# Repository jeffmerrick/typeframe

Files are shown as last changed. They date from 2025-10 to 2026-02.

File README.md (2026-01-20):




The Typeframe project is a collection of open-source hardware and software for building writerdecks/cyberdecks.

# PX-88

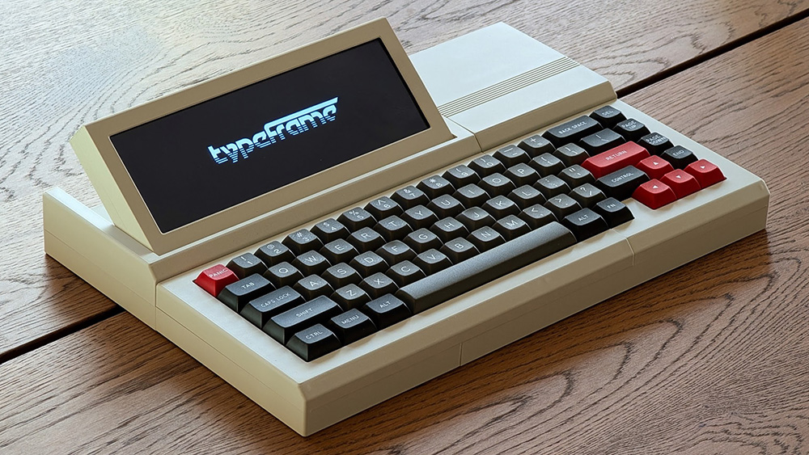
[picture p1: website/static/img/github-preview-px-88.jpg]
Typeframe PX-88


The first model, the PX-88, is a portable-ish computer inspired by the [Epson PX-4](https://www.homecomputermuseum.nl/en/collectie/epson/epson-px-4). The goal was to create a writerdeck that could be used with modern web-based editors.

## Features

- **Mechanical Keyboard**: A detachable 65% keyboard with hot-swappable switches.
- **Touch Screen**: No mouse needed.
- **One Power Connection**: A USB-C port that powers the device _and_ charges the battery.
- **Raspberry Pi 4 B:** Powerful enough to run web-based editors like Google Docs.
- **Software Setup**: A distraction-free laucher, boot splash images, and set up for keyboard shortcuts for screen brightness.
- **Easy to Build**: Minimal soldering required (just the power switch and status light!)

---

# PS-85

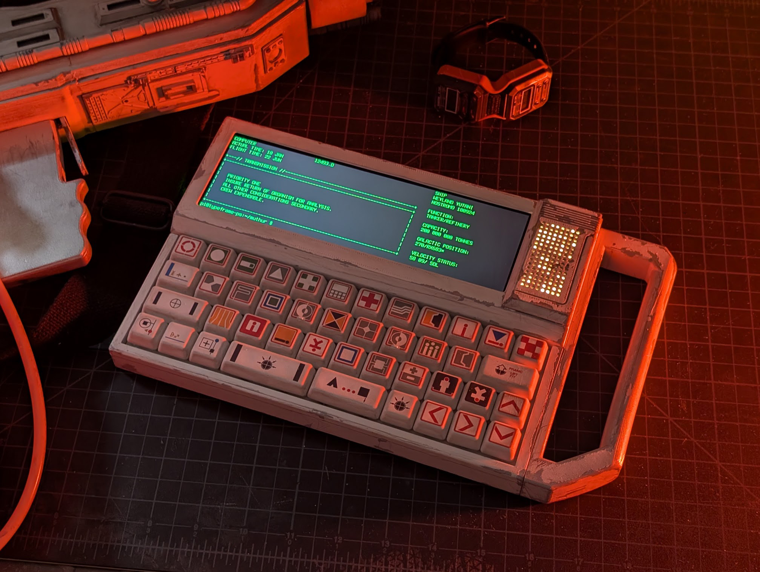
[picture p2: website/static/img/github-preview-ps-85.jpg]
Typeframe PS-85


The second model, the PS-85, is a rugged barebones slate-style portable computer inspired by the Alien universe

### Features

- **Carrying Handle**: A sturdy handle for easy transport.
- **Exposed GPIO**: Access to all GPIO pins for tinkering or adding your own Bonnets.
- **[MU/TH/UR](https://avp.fandom.com/wiki/MU/TH/UR_6000) LED Matrix**: An optional 9x16 LED matrix, just for fun.
- **Mechanical Keyboard**: A 40% keyboard with hot-swappable switches.
- **One Power Connection**: A Micro USB port that powers the device _and_ charges the battery.
- **Raspberry Pi Zero 2W**: Low power and compact.

## Documentation

For full assembly guides, bill of materials, and software setup instructions, please visit **[typeframe.net](https://www.typeframe.net)**

## Project Structure

- `px-88/`: Contains all files for the PX-88 model.
  - `hardware/`: 3D models and source CAD files.
  - `software/`: Scripts and configuration for the device.
- `ps-85/`: Contains all files for the PS-85 model.
  - `hardware/`: 3D models and source CAD files.
  - `software/`: Scripts and configuration for the device.
- `website/`: The Docusaurus source for the documentation site.

## License

This project uses multiple licenses for different parts of the work. Please see the `LICENSE` file for more details.

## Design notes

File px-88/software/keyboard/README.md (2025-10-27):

Keymaps for MK Point65 PCB from https://mechanicalkeyboards.com/products/mk-point65-keyboard-kit

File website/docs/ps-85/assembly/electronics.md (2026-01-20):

---
title: Electronics
sidebar_position: 2
description: Hooking up the electronics.
---

# Electronics Assembly

## Overview

Unlike the PX-88, you'll need to do more soldering for the PS-85. I'd never done it before this, so don't be intimidated if you haven't also! You will likely want to hook most things up before you start putting the case together to make sure the key components work. These steps will be repeated later with less detail in the full assembly guide.

## Soldering Connections to the PowerBoost

When I was putting mine together, I wished I had a diagram like this, so hopefully this helps you out.

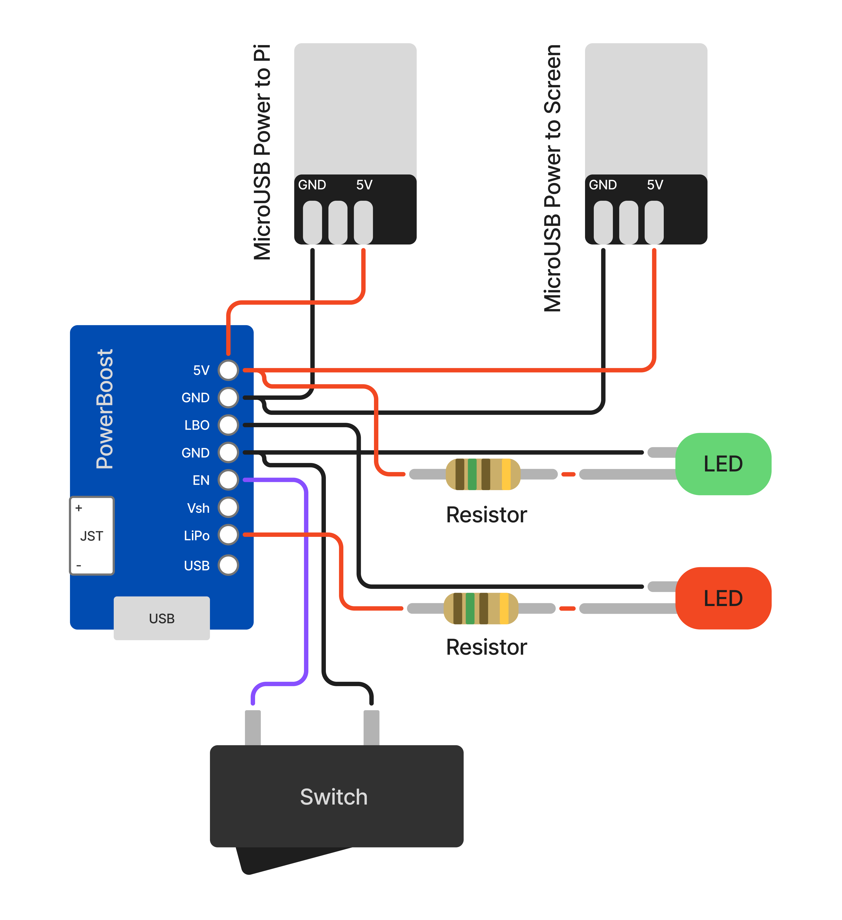
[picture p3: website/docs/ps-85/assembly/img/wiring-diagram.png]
PS-85 Wiring Diagram


| Soldered Connections                                              |
| ----------------------------------------------------------------- |
| PowerBoost `5V` &rarr; MicroB Plug 1 (Pi) `5V`                    |
| PowerBoost `GND` &rarr; MicroB Plug 1 (Pi) `GND`                  |
| PowerBoost `5V` &rarr; MicroB Plug 2 (Screen) `5V`                |
| PowerBoost `GND` &rarr; MicroB Plug 2 (Screen) `GND`              |
| PowerBoost `5V` &rarr; `Resistor` &rarr; Green LED `Long Leg`     |
| PowerBoost `GND` &rarr; Green LED `Short Leg`                     |
| PowerBoost `LBO` &rarr; Red LED `Short Leg`                       |
| PowerBoost `LiPo/BAT` &rarr; `Resistor` &rarr; Red LED `Long Leg` |
| PowerBoost `GND` &rarr; Power Switch `Terminal 1`                 |
| PowerBoost `EN` &rarr; Power Switch `Terminal 2`                  |

You can use any of the `GND` pins on the PowerBoost for the ground connections.

Remember that the power switch requires the wires to be disconnected to be seated in the case later, so you may want to use Dupont connectors for it here.

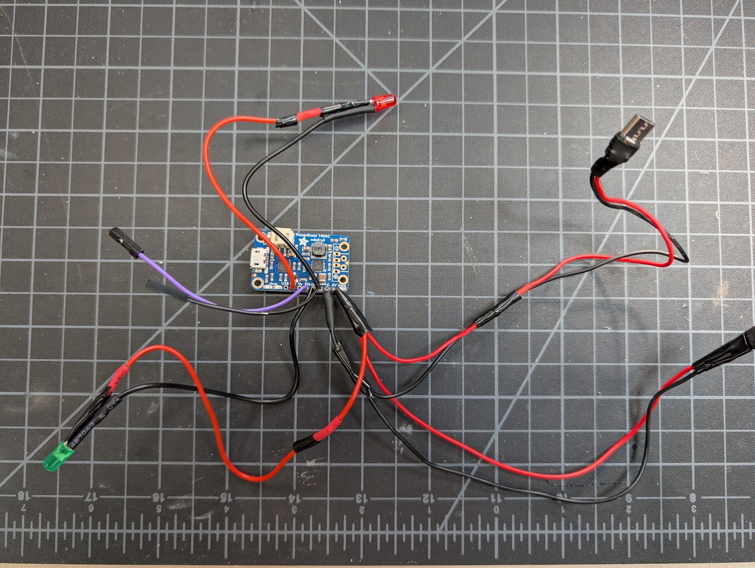
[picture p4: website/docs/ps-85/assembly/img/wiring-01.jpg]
PS-85 Wiring


## Screen

### 1. Assemble the DIY HDMI Cable and Plugs

Attach the two DIY HDMI plugs to either end of the DIY ribbon cable. If you're not sure which direction to insert the cable, look for the metal contacts on the cable - they should face the contacts inside the plugs.

### 2. Connect the Screen to Power and the Raspberry Pi

Plug the Micro USB power into the screen USB port labeled "Power". Plug one end of the DIY HDMI cable into the HDMI port on the screen and the other end into the Raspberry Pi's HDMI port.

## Raspberry Pi Power

Plug the remaining Micro USB port coming from the PowerBoost into the Pi port labeled `PWR IN`.

## Keyboard

You will likely want to print the keyboard plate before you start putting switches in the keyboard PCB. But once assembled, the keyboard should easily drop into the case.

Once assembled, just plug it in to the Raspberry Pi's USB port labeled `USB` with the USB-C to Micro USB cable.

## Battery

### 1. Reverse the Polarity of the Battery Connector

:::danger[Heads up!]

The battery connector may come with the polarity reversed. If the red wire is connected on the wrong side, you'll need to swap the wires so that red goes to positive and black goes to negative. You will 100% fry your PowerBoost if you don't check this! (Ask me how I know...)

:::

This is easy to do, no need to re-solder. You can use a small flathead screwdriver to gently pry up the plastic tabs on the connector and slide the wires out. Then just reinsert them in the correct order.

### 2. Connect the Battery to the PowerBoost 1000c

Plug the battery connector into the JST plug on the PowerBoost. Note the + and - symbols to ensure the polarity is correct. The Pi should power on at this point but won't boot until you complete the software setup.

## Testing

You'll need to jump to the [Software setup section](../software-setup/) to get the Pi booted and the screen working. Once you've done that, you can test all the connections before moving on to final assembly.

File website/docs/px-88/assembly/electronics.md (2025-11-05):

---
title: Electronics
sidebar_position: 2
description: Hooking up the electronics.
---

# Electronics Assembly

## Overview

Here, I'll go over how to connect the electronics for the PX-88. This includes connecting the Raspberry Pi, screen, Power Management HAT, and other components like the power switch and status light. You will likely want to hook most things up before you start putting the case together to make sure the key components work. These steps will be repeated later with less detail in the full assembly guide.

## Battery and Power Management HAT

### 1. Reverse the Polarity of the Battery Connector

:::danger[Heads up!]

The battery connector may come with the polarity reversed. If the red wire is connected on the wrong side, you'll need to swap the wires so that red goes to positive and black goes to negative.

:::

This is easy to do, no need to re-solder. You can use a small flathead screwdriver to gently pry up the plastic tabs on the connector and slide the wires out. Then just reinsert them in the correct order.

You want it to look like this:

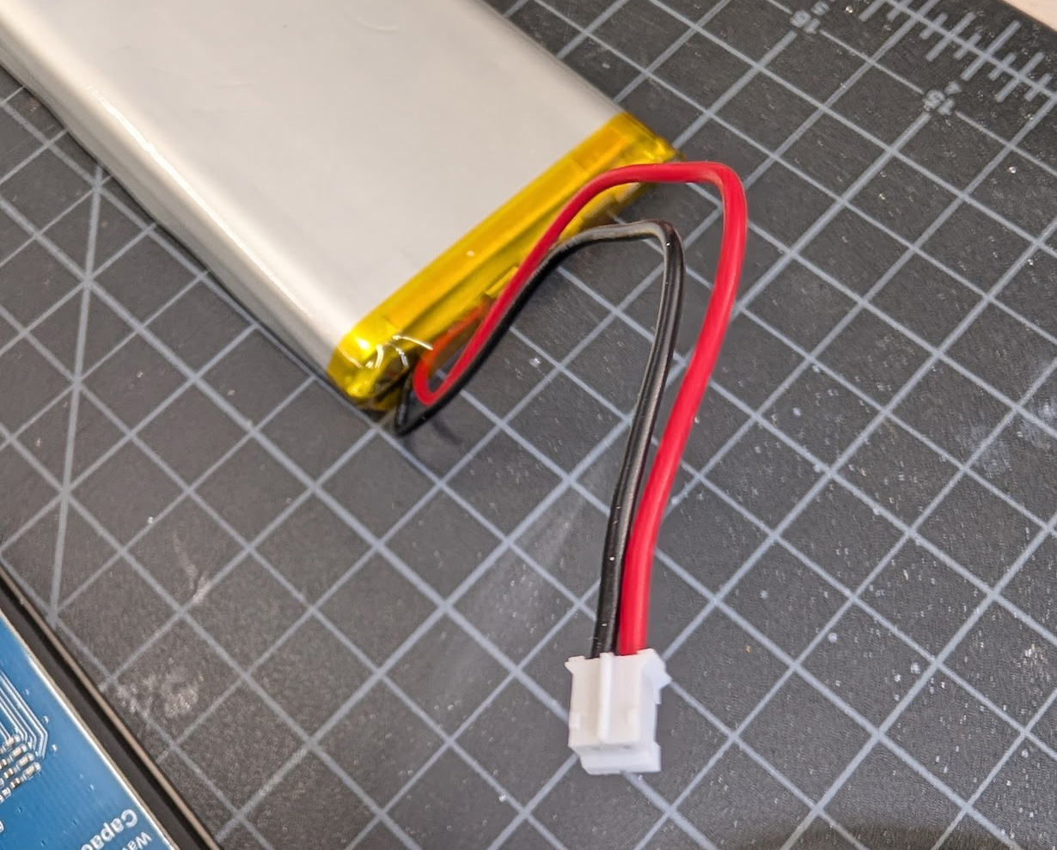
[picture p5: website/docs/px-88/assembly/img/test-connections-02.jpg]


Photos where the battery connects to the HAT may be a bit confusing as the extension cable does not have the wires swapped, but the battery connector does.

### 2. Attach the 200mm Extension Cable to the Battery

If you really want the colors to match, you can swap the wires on the extension cable as well, but it's not strictly necessary as long as you keep track of which wire is which.

### 3. Install the 1220 Lithium Battery

Insert the 1220 lithium battery into the battery holder on the Power Management HAT.

### 4. Attach the Power Management HAT to the Raspberry Pi

Push the GPIO header that came with the Power Management HAT into the GPIO pins on the Raspberry Pi, then the HAT itself onto the header. Don't worry about the standoffs since we're just testing, but hold on to them for later.

### 5. Connect the Battery to the Power Management HAT

Plug the battery connector into the battery port on the Power Management HAT. Note the + and - symbols to ensure the polarity is correct. In my photos the black wire on the extension cable is actually the positive wire.

## Screen

### 1. Connect the DSI Cable from the Screen to the Raspberry Pi

Using the longer 500mm DSI ribbon cable, connect one end to the screen and the other end to the DSI port on the Raspberry Pi. Make sure the cable is securely inserted and the connectors are properly aligned. If you're not sure which direction to insert the cable, look for the metal contacts on the cable - they should face the contacts inside the connector.

### 2. Connect the 4 Pin Cable to the GPIO Header

1. Plug the provided 4 pin connector into the screen - you'll see labels for each pin on the back of the screen. For mine they corresponded to the following wire colors (yours may be different, so double check!):

   - 5V - Yellow
   - GND - Blue
   - SDA1 - Purple
   - SCL1 - Green

2. Connect the other ends of the 4 pin connector to your Dupont female to male jumpers. You can choose the same colors to make things easier. Again, as we're just testing you can skip this step if you want to add the extension cable later.

3. Connect the jumpers to the GPIO header on the Power Management HAT as follows:

   - 5V - Yellow - 5V Power (Physical Pin 4)
   - GND - Blue - Ground (Physical Pin 6)
   - SDA - Purple - GPIO2 (SDA) (Physical Pin 3)
   - SCL - Green - GPIO3 (SCL) (Physical Pin 5)

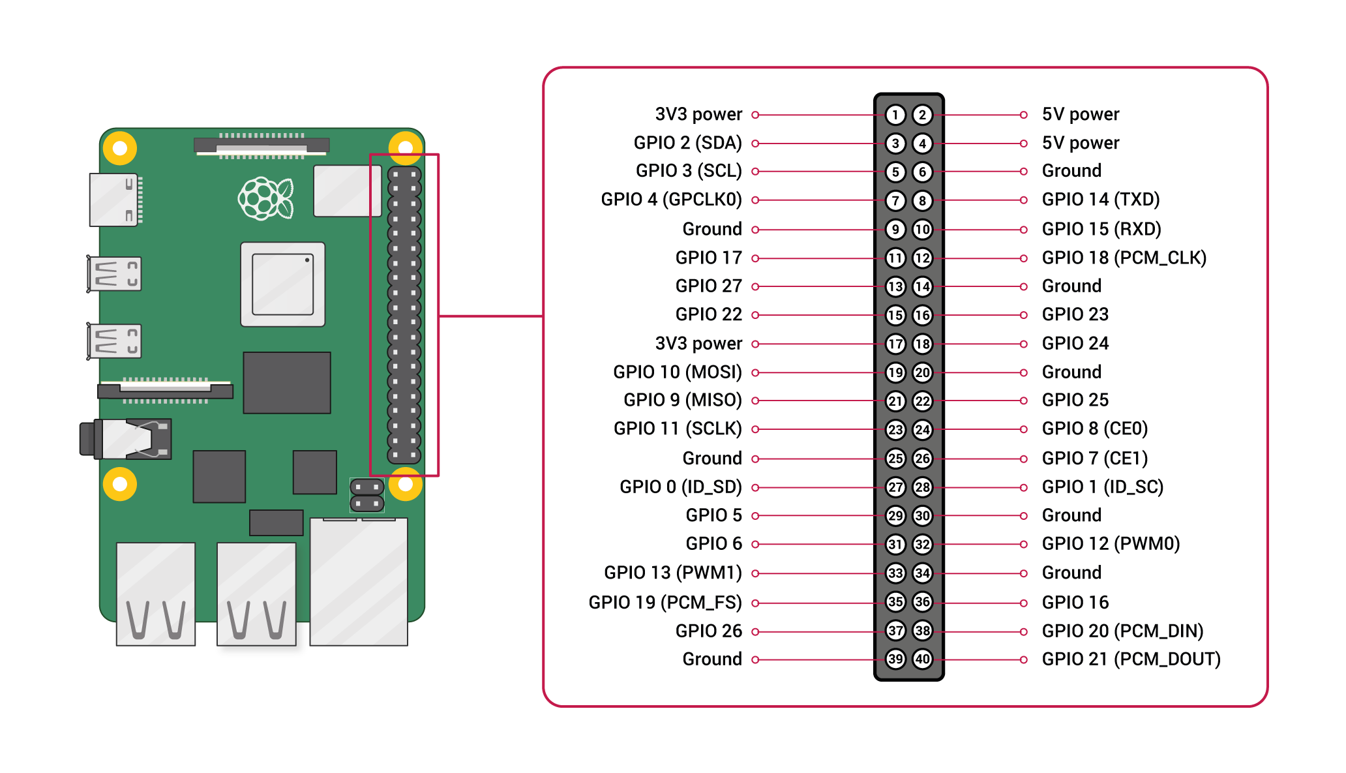
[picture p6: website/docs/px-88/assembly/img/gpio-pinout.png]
Raspberry Pi Pinout


Here's an older photo from when I was testing things out. You won't need to have the standoffs installed, but you can see the connections:

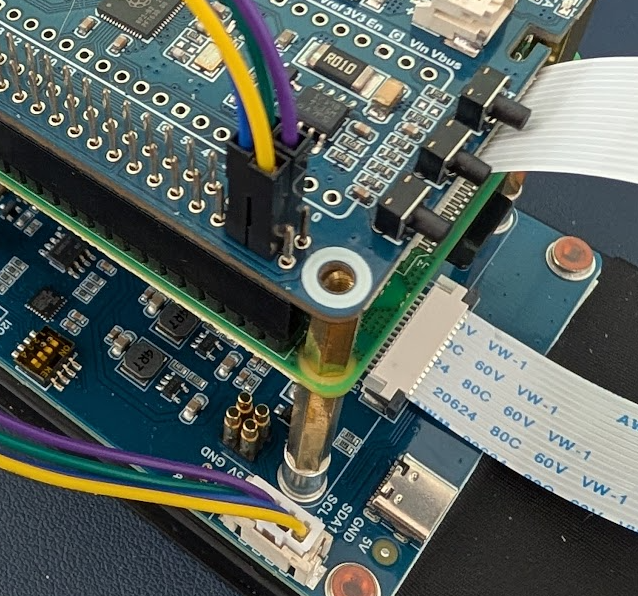
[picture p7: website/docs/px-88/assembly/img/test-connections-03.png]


## Keyboard

If you want to test out the keyboard, you can hook it up, but you'll need to follow the keyboard assembly to get the stabilizers, switches, and keycaps installed as well. You'll be able to assemble the rest of the keyboard case around it later, just removing a few of the switches and keys to access the screw mount points. But, you may elect to wait until later and use SSH or an extra keyboard for initial testing.

### 1. Connect Keyboard to Daughterboard

It connects with a small included cable. The cable goes in with the bigger metal contacts facing out and slots straight down.

### 2. Connect Daughterboard to Raspberry Pi

Using your small USB-A to USB-C cable, connect the daughterboard to one of the Raspberry Pi's USB ports.

## Power Switch

You'll need to do a bit of soldering here. You can also skip this step and use the onboard power button on the Power Management HAT for testing. If you choose to solder before installing the switch in the case, you may want to use Dupont jumpers to make it easier to connect and disconnect later. (Otherwise, you'll likely need to re-solder!)

### 1. Solder Wires to Power Switch

Solder Wires to Power Management HAT

Solder two female Dupont jumpers to the two terminals on the power switch. It doesn't matter which wire goes to which terminal. My soldering kit came with some heat shrink tubing, which I used here to cover the exposed contacts after soldering.

### 2. Solder Two Male Dupont Connectors to the Power Management HAT.

- Connect one to the Pin 19
- Connect the other to a Ground pin (labeled G)

Once the firmware is installed, this switch will perform the same function as the onboard power button on the HAT.

## Status LED

As with the power switch, you can add the status LED later if you'd like - it's easy to drop in after everything else is assembled.

### 1. Solder Dupont Jumpers to Status LED

Solder two female Dupont connectors to the two terminals on the status LED. Solder the red wire to the longer leg (positive) and the black wire to the shorter leg (negative). Include your 150Ω resistor in series with either wire.

### 2. Connect Jumpers to GPIO Header on Power Management HAT

- Connect the red wire (with resistor) to GPIO 19 (Physical Pin 35)
- Connect the black wire to a Ground pin (Physical Pin 39)

Note that the status LED won't work until some configuration is done later in the software setup section.

My test connections:

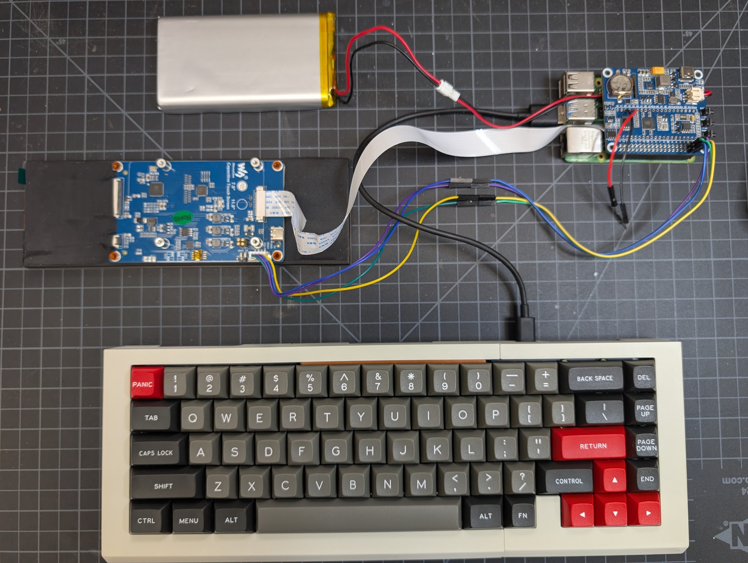
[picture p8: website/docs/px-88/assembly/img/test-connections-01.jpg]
Most Connections


Everything connected when it's installed in the case later:

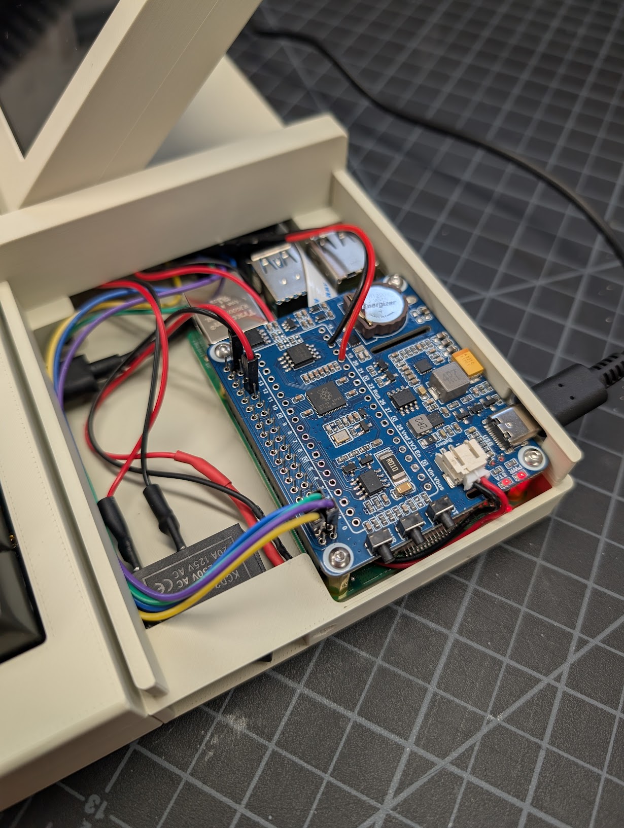
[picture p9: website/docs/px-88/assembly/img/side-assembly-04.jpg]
Completed Connections


## Testing

You'll need to jump to the [Software setup section](../software-setup/) to get the Pi booted, the screen working, and the Power Management HAT firmware installed. Once you've done that, you can test all the connections before moving on to final assembly.

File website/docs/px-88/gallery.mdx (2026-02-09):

---
title: Gallery
sidebar_position: 4
hide_table_of_contents: true
---

import { GalleryGrid } from "@site/src/components/GalleryGrid";

## Typeframe PX-88

<GalleryGrid
  images={[
    require("./img/typeframe-px-88-01.jpg"),
    require("./img/typeframe-px-88-02.jpg"),
    require("./img/typeframe-px-88-03.jpg"),
    require("./img/typeframe-px-88-04.jpg"),
    require("./img/typeframe-px-88-05.jpg"),
    require("./img/typeframe-px-88-06.jpg"),
    require("./img/typeframe-px-88-07.jpg"),
    require("./img/typeframe-px-88-08.jpg"),
  ]}
/>

### Earlier Prototype with Alternate Keycaps

<GalleryGrid
  images={[
    require("./img/typeframe-px-88-10.jpg"),
    require("./img/typeframe-px-88-09.jpg"),
    require("./img/typeframe-px-88-11.jpg"),
  ]}
/>

---

## Community Builds

### Paul's Build

[Paul Rickards](https://biosrhythm.com/) built a Typeframe with a ton of enhancements including a Pi 5, speaker, alternate power switch, and modified case to fit a different keyboard. He even made a battery status system tray icon! Thanks to Paul for also helping to uncover some issues with the build and documentation.

[Check out his build on Mastodon](https://mastodon.social/@paulrickards/115703267825409926).

<GalleryGrid
  images={[
    require("./img/typeframe-px-88-paul-1.jpg"),
    require("./img/typeframe-px-88-paul-2.jpg"),
    require("./img/typeframe-px-88-paul-3.jpg"),
  ]}
/>

---

Did you build your own? [E-mail me](mailto:jeff@typeframe.net) photos and I'll add them to the gallery!

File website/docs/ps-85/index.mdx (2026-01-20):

---
title: PS-85
sidebar_position: 1
hide_table_of_contents: true
---

import Image from "@theme/IdealImage";
import DocCardList from "@theme/DocCardList";

# Typeframe PS-85

<p>
  <Image img={require("./img/typeframe-ps-85-01.jpg")} />
</p>

The PS-85 is a rugged barebones slate-style portable computer inspired by the Alien universe.

Before I built the [PX-88](/docs/px-88/), I tried to modify the awesome [Penkesu](https://penkesu.computer) by Penk Chen to fit a hot-swap keyboard PCB. While I was somewhat successful, I wasn't happy with the result and it lost the charm of the original. After pivoting to the PX-88, I still had the working guts from my Penkesu experiment - so I decided to design a simple slate-style case around it. You'll find the parts and wiring are very similar to the Penkesu with a couple of additions.

### Features

- **Carrying Handle**: A sturdy handle for easy transport.
- **Exposed GPIO**: Access to all GPIO pins for tinkering or adding your own Bonnets.
- **[MU/TH/UR](https://avp.fandom.com/wiki/MU/TH/UR_6000) LED Matrix**: An optional 8x16 LED matrix, just for fun.
- **Mechanical Keyboard**: A 40% keyboard with hot-swappable switches.
- **One Power Connection**: A Micro USB port that powers the device _and_ charges the battery.
- **Raspberry Pi Zero 2W**: Low power and compact.

### Caveats

- **Lite OS**: With a Pi Zero you're likely going to want to run Raspberry Pi OS Lite and have a command-line only interface.
- **No Touch Screen**: While the screen supports touch, it requires a separate USB connection. (Doesn't matter if you're using the Lite OS anyway.)
- **No Hardware Screen Brightness**: The HDMI screen doesn't allow brightness control like a DSI screen.

<DocCardList />

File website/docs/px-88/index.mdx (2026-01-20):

---
title: PX-88

sidebar_position: 2
hide_table_of_contents: true
---

import Image from "@theme/IdealImage";
import DocCardList from "@theme/DocCardList";

# Typeframe PX-88

<p>
  <Image img={require("./img/typeframe-px-88-01.jpg")} />
</p>

The PX-88 is a portable-ish computer inspired by the [Epson PX-4](https://www.homecomputermuseum.nl/en/collectie/epson/epson-px-4). The goal was to create a writerdeck that could be used with modern web-based editors.

This is my first time building something of this scope, especially with CAD and electronics. I've tried to document everything in detail, so someone like myself with limited experience can tackle the project as well. If I can do it, you can too!

### Features

- **Mechanical Keyboard**: A detachable 65% keyboard with hot-swappable switches.
- **Touch Screen**: No mouse needed.
- **One Power Connection**: A USB-C port that powers the device _and_ charges the battery.
- **Raspberry Pi 4 B:** Powerful enough to run web-based editors like Google Docs.
- **Software Setup**: A distraction-free launcher, boot splash images, and setup for keyboard shortcuts for screen brightness.
- **Easy to Build**: Minimal soldering required (just the power switch and status light!)

<DocCardList />

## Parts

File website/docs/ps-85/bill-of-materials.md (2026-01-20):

---
sidebar_position: 1
description: Everything you need to build the PS-85.
---

# Bill of Materials

These are the components you'll need to build the PS-85. I've linked to the manufacturer, Adafruit, or Amazon, where I purchased most of my parts. Often the Amazon link will be a set of multiple variants/sizes, so you may be able to find the same part individually elsewhere. If you can find the parts at [Adafruit](https://www.adafruit.com/), please consider supporting them.

## Keyboard

| Component | Notes | Link |
| --- | --- | --- |
| **KPrepublic BM43 PCB** | I had the 43 key version from my earlier experiments, but an ortholinear layout would match the aesthetic better. No idea if the [BM40](https://kprepublic.com/products/bm40-rgb-40-hot-swap-custom-mechanical-keyboard-pcb-qmk-underglow-type-c-planck) would be able to be swapped in easily, you'd at least need a new plate. | [kprepublic.com](https://kprepublic.com/collections/bm43/products/bm43a-bm43-43-keys-40-custom-mechanical-keyboard-pcb-programmed-numpad-layouts-qmk-firmware-with-rgb-bottom-underglo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) [amazon.com](https://www.amazon.com/dp/B09163VRTV?th=1) |
| **Low Profile Plate Mount Stabilizers** | | [amazon.com](https://www.amazon.com/dp/B0F48MHHDR?th=1) |
| **Keyboard Switches - Cherry MX Compatible (x43)** | I had medium profile switches but you could get a different profile, just make sure you get the matching stabilizers. | [amazon.com](https://www.amazon.com/dp/B0F4Y41SLJ) |
| **Keycaps - MX Compatible (x43)** | Flat profiles like DSA or XDA match the aesthetic well and are more flexible since they don't need to go in a specific row. But any MX compatible keycaps will work. Because of the 40% layout you'll need some odd sizes - buying a full 80% TKL set should get you what you need. | [spkeyboards.com](https://spkeyboards.com/collections/keycap-sets/products/g20-semiotic-keycaps) |
| **Short USB-C to Micro-USB Cable** | I had one in my hoarded cables that I was able to use. It just has to reach from the keyboard to the Pi, so it can be quite short. | [adafruit.com](https://www.adafruit.com/product/3879) |

## Screen

| Component | Notes | Link |
| --- | --- | --- |
| **Waveshare 7.9inch HDMI LCD** | | [waveshare.com](https://www.waveshare.com/7.9inch-hdmi-lcd.htm) |
| **DIY Cable Parts - Straight HDMI Plug** | In my photos I have an angled version but the straight one should work fine. | [adafruit.com](https://www.adafruit.com/product/3548) |
| **DIY Cable Parts - Straight Mini HDMI Plug**  | | [adafruit.com](https://www.adafruit.com/product/3552) |
| **DIY Cable Parts - 20 cm Ribbon Cable** | | [adafruit.com](https://www.adafruit.com/product/3561) |
| **USB DIY Slim Connector Shell - MicroB Plug** | You'll actually need two, for the power to the screen and Pi. Get some extras in case you mess up the soldering like me. | [adafruit.com](https://www.adafruit.com/product/1826) |

## Computer

| Component | Notes | Link |
| --- | --- | --- |
| **Raspberry Pi Zero 2W with Header** | | [adafruit.com](https://www.adafruit.com/product/6008) |
| **microSD Card - 16GB+** | Get a quality SD card from a reputable brand. | [adafruit.com](https://www.adafruit.com/product/6010) [amazon.com](https://www.amazon.com/dp/B08L5HMJVW) |
| **3.7V 6000mAh 906090 LiPo JST PH2.0mm Battery** | | [amazon.com](https://www.amazon.com/dp/B0CRDMZQ3Q) |
| **PowerBoost 1000C** | | [adafruit.com](https://www.adafruit.com/product/2465) |
| **KCD3 SPST On-Off Switch, 2 Pin** | | [amazon.com](https://www.amazon.com/dp/B082PNCL61) |
| **Dupont Female to Male Extension Wires (x2)** | Optional, but recommended to make disconnecting the power switch easier. | [adafruit.com](https://www.adafruit.com/product/1954) [amazon.com](https://www.amazon.com/dp/B0BRTHR2RL) |
| **~150Ω Resistor (2x)** | | |
| **5mm Green LED** | For power indicator | [adafruit.com](https://www.adafruit.com/product/4203) [amazon.com](https://www.amazon.com/dp/B0CR886L92) |
| **5mm Red LED** | For low battery indicator | [adafruit.com](https://www.adafruit.com/product/4203) [amazon.com](https://www.amazon.com/dp/B0CR886L92) |
| **USB DIY Slim Connector Shell - MicroB Plug** | You'll actually need two, for the power to the screen and Pi. Get some extras in case you mess up the soldering like me. | [adafruit.com](https://www.adafruit.com/product/1826) |

## LED Matrix (Optional)

| Component | Notes | Link |
| --- | --- | --- |
| **2x20 Socket Riser Header for Raspberry Pi HATs and Bonnets** | You may want this either way to make the GPIO pins more easily accessible. | [adafruit.com](https://www.adafruit.com/product/4079) |
| **Adafruit CharliePlex LED Matrix Bonnet - 8x16 Warm White LEDs** | | [adafruit.com](https://www.adafruit.com/product/4122) |

## Screws and More

I used self-tapping M3 screws to avoid having to use heat-set inserts. You may be able to use normal M3 screws instead, but I have not tested that. There is enough room for socket head caps, so other heads should work as well.

| Component | Quantity | Notes | Link |
| --- | --- | --- | --- |
| **M3 x 10mm Self-tapping Screws** | 2 | | |
| **M3 x 16mm Self-tapping Screws** | 5 | | |
| **M3 x 20mm Self-tapping Screws** | 2 | | |
| **M3 x 25mm Self-tapping Screws** | 3 | | |
| **M2.5 x 4mm Screws** | 4 | | |
| **M2.5 x 8mm Screws** | 4 | | |
| **M2.5 x 20mm Screws** | 4 | | |
| **M2 x 4mm Screws** | 4 | | |
| **Wire** | | | [adafruit.com](https://www.adafruit.com/product/290) |
| **Matte White PLA Filament** | | If you're painting, any light color will be fine. | [amazon.com](https://www.amazon.com/dp/B089S1HB8K?th=1) |
| **Heat Resistant Tape** | | For securing the battery in the case. | [amazon.com](https://www.amazon.com/dp/B07F8TZZ4N) |
| **Grip Tape** | | Optional, for the bottom of the case to keep it from sliding around. Anything rubber and grippy would work. | [amazon.com](https://www.amazon.com/dp/B0FBGYF432) |

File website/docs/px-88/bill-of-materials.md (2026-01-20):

---
sidebar_position: 1
description: Everything you need to build the PX-88.
---

# Bill of Materials

These are the components you'll need to build the PX-88. I've linked to the manufacturer, Adafruit, or Amazon, where I purchased most of my parts. Often the Amazon link will be a set of multiple variants/sizes, so you may be able to find the same part individually elsewhere. If you can find the parts at [Adafruit](https://www.adafruit.com/), please consider supporting them.

## Keyboard

| Component | Notes | Link |
| --- | --- | --- |
| **MK Point65 PCB** | I chose the multi-layout version, however the RGB version should also work. | [mechanicalkeyboards.com](https://mechanicalkeyboards.com/products/mk-point65-pcb?variant=49801892331820) |
| **MK Point65 Daughterboard** | | [mechanicalkeyboards.com](https://mechanicalkeyboards.com/products/mk-point65-daughterboard-s11-udb) |
| **PCB Mount Stabilizers** | | [mechanicalkeyboards.com](https://mechanicalkeyboards.com/products/durock-stabilizers-v2-pcb-mount-screw-in-tkl-kit) |
| **Keyboard Switches - Cherry MX Compatible (x70)** | You can of course get whatever type of switches you prefer. But since there is no plate for the switches, just make sure you get switches that have 5 pins (the extra two plastic pins on the sides) for better stability. | [mechanicalkeyboards.com](https://mechanicalkeyboards.com/products/cherry-mx2a-blue-60g-clicky) |
| **Keycaps - MX Compatible (x70)** | Flat profiles like DSA or XDA match the portable computer aesthetic well and are more flexible since they don't need to go in a specific row. But any MX compatible keycaps will work. Note that if you get the linked 60% modifiers, you'll still need a `1.75U Shift`, a `1U Fn`, and the four `1U` keys you want on the right (typically `Del` or `Home`, `PgUp`, `PgDn`, and `End`). The "Alternate" kit will cover that and hopefully comes back in stock. | [spkeyboards.com](https://spkeyboards.com/products/dsa-dolch?variant=49434848428310) |
| **Short USB-C to USB-A Cable** | I had one in my hoarded cables that I was able to use. It just has to reach from the keyboard to the Pi, so it can be quite short: ~150mm (6 in). | [adafruit.com](https://www.adafruit.com/product/4472) |

## Screen

| Component | Notes | Link |
| --- | --- | --- |
| **Waveshare 7.9inch DSI LCD** | | [waveshare.com](https://www.waveshare.com/7.9inch-dsi-lcd.htm) |
| **500mm DSI Cable** | These may be labeled for use with the Raspberry Pi Camera, but they will work for the DSI screen as well. | [amazon.com](https://www.amazon.com/dp/B08662272F) |
| **150-200mm Dupont Female to Male Extension Wires (x4)** | Note that these need to be low-profile (it's a tight fit) and they apparently come in different sizes. | [adafruit.com](https://www.adafruit.com/product/1954) [amazon.com](https://www.amazon.com/dp/B0BRTHR2RL) |

## Computer

| Component | Notes | Link |
| --- | --- | --- |
| **Raspberry Pi 4 Model B - 4GB+ RAM** | | [adafruit.com](https://www.adafruit.com/product/4564) [raspberrypi.com](https://www.raspberrypi.com/products/raspberry-pi-4-model-b/) |
| **microSD Card - 32GB+** | Get a quality SD card from a reputable brand. | [adafruit.com](https://www.adafruit.com/product/6010) [amazon.com](https://www.amazon.com/dp/B08L5HMJVW) |
| **3.7V 10000mAh LiPo JST PH2.0mm Battery** | I ran into issues with some batteries not having a high enough discharge rate. Look for batteries with a 1S 3C rate or higher. There is room in the case for batteries with slightly different dimensions, but not much taller than 11mm. | [amazon.com](https://www.amazon.com/dp/B0D3LMBJC5) |
| **200mm JST PH2.0mm 2 Pin Male to Female Extension Cable** | | [amazon.com](https://www.amazon.com/dp/B0D1XS3W39) |
| **Waveshare Power Management HAT (B)** | | [waveshare.com](https://www.waveshare.com/power-management-hat-b.htm) |
| **1220 Lithium Battery** | For the clock on the Power Management HAT. Not sure if it's strictly necessary, but I added it. | [amazon.com](https://www.amazon.com/dp/B00004YK0L) |
| **KCD3 SPST Momentary Switch, 2 Pin** | I'm linking to the listing where I found mine, however the momentary version seems to no longer be there. Searching for "KCD3 momentary switch" brings up some options. | ~~[amazon.com](https://www.amazon.com/dp/B0BLJVFYKV)~~ |
| **Dupont Female to Male Extension Wires (x2)** | Optional, but recommended to make disconnecting the power switch easier. You'll have extras if you get a pack for the screen. | [adafruit.com](https://www.adafruit.com/product/1954) [amazon.com](https://www.amazon.com/dp/B0BRTHR2RL) |
| **~150Ω Resistor** | | |
| **5mm Green LED** | | [adafruit.com](https://www.adafruit.com/product/4203) [amazon.com](https://www.amazon.com/dp/B0CR886L92) |
| **Dupont Female to Any Jumper Wires (x2)** | You'll only need the female side, the other side will be soldered to the LED and resistor. | [adafruit.com](https://www.adafruit.com/product/1954) [amazon.com](https://www.amazon.com/dp/B0BRTHR2RL) |
| | | |

## Screws and More

I used self-tapping M3 screws to avoid having to use heat-set inserts. You may be able to use normal M3 screws instead, but I have not tested that. There is enough room for socket head caps, so other heads should work as well.

| Component | Quantity | Notes | Link |
| --- | --- | --- | --- |
| **M3 x 6mm Self-tapping Screws**  | 2 | | [amazon.com](https://www.amazon.com/dp/B0CDBCJBYK) |
| **M3 x 10mm Self-tapping Screws** | 7 | | |
| **M3 x 12mm Self-tapping Screws** | 1 | | |
| **M3 x 14mm Self-tapping Screws** | 2 | | |
| **M3 x 16mm Self-tapping Screws** | 5 | | |
| **M3 x 20mm Self-tapping Screws** | 9 | | |
| **M3 Washers** | 4 | Optional, but I used for the PCB mounting. | |
| **M2.5 x 12mm Screws** | 4 | | |
| **Matte Beige PLA Filament** | | I got good results with Overture Matte Beige PLA if you're going beige. | [amazon.com](https://www.amazon.com/dp/B0DRG3P2PY) |
| **Heat Resistant Tape** | | For securing the battery in the case. | [amazon.com](https://www.amazon.com/dp/B07F8TZZ4N) |

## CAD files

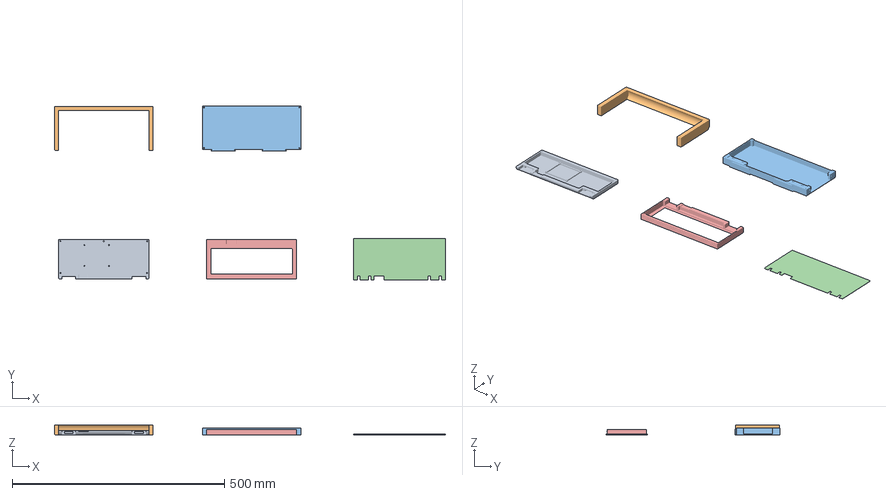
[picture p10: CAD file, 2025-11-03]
px-88/hardware/print-files/tight-tolerances/3MF/main.3mf
920.0 x 409.9 x 23.4 mm
screen bottom
screen border
case
case lid
screen top

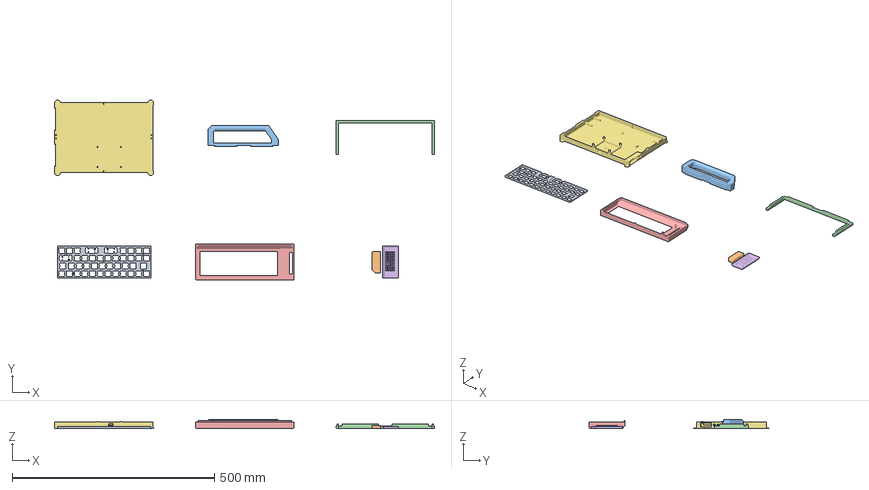
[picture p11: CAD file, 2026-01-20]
ps-85/hardware/print-files/3MF/px-85-all.3mf
940.5 x 445.2 x 22.0 mm
plate
gpio cover
handle
keyboard top
screen top
charlieplex
case bottom

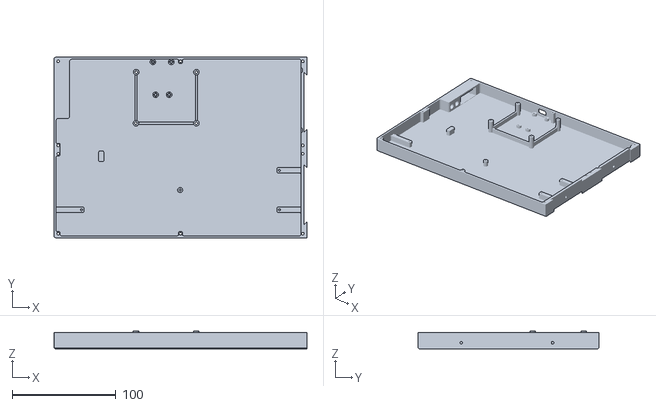
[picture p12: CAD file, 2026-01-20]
ps-85/hardware/print-files/STL/case_bottom.stl
243.6 x 174.0 x 17.3

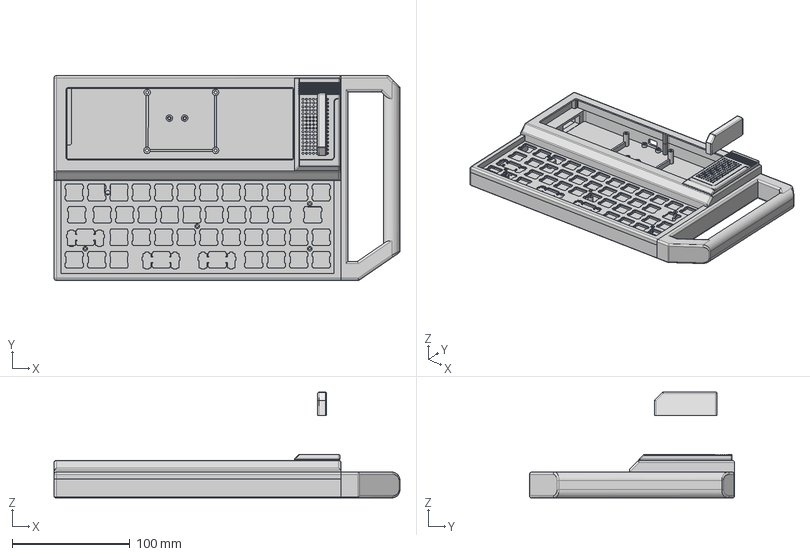
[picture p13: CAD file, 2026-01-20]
ps-85/hardware/source-files/typeframe-ps-85.step
293.6 x 174.0 x 89.9 mm
keyboard plate (1)
case bottom
screen top
keyboard top
handle
charlieplex

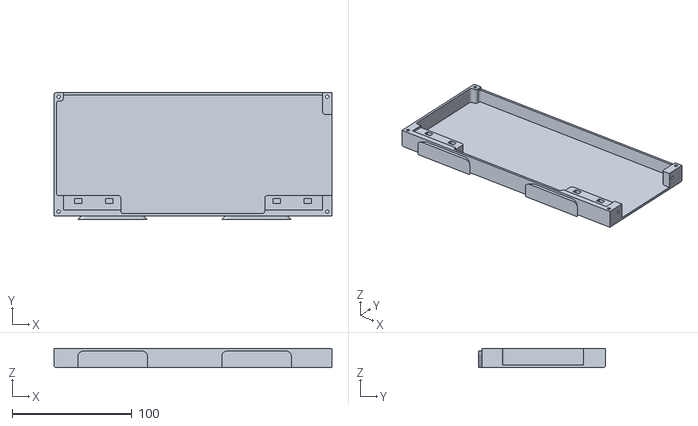
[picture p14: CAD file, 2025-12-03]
px-88/hardware/print-files/loose-tolerances/STL/case_bottom.stl
232.0 x 106.0 x 16.0

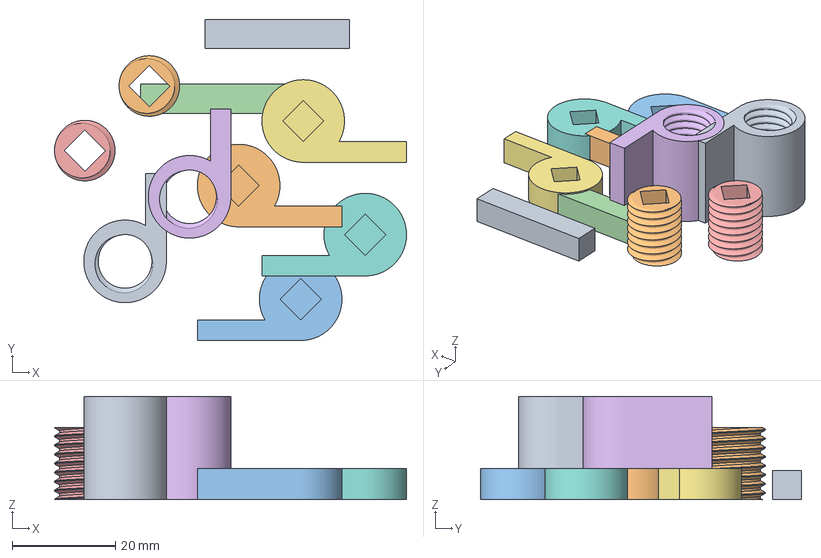
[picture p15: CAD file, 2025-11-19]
px-88/hardware/print-files/tight-tolerances/3MF/hinges.3mf
68.2 x 62.2 x 20.0 mm
hinge barrel x 2
hinge cap left x 2
hinge cap right x 2
hinge shaft x 2
hinge slider x 2

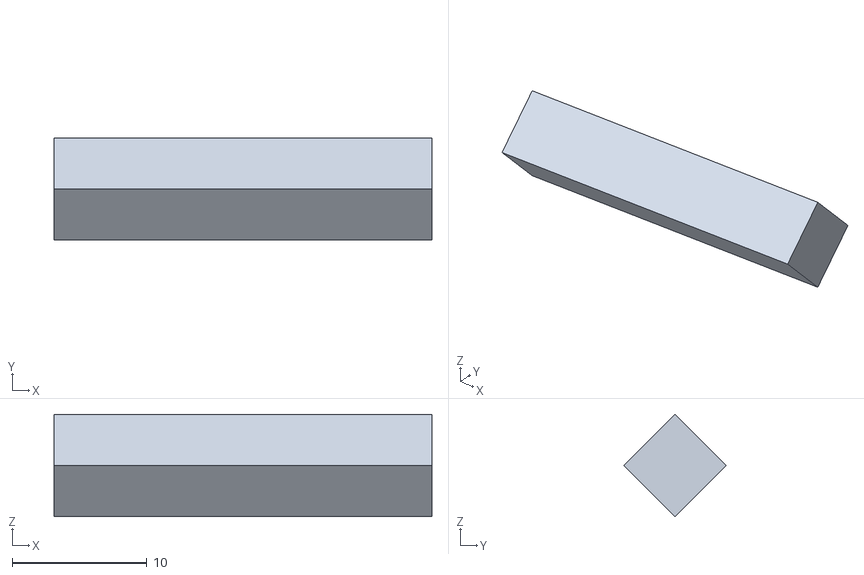
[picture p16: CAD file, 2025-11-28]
px-88/hardware/print-files/tight-tolerances/STL/hinge_shaft_x2_0.15mm.stl
28.0 x 7.58 x 7.58

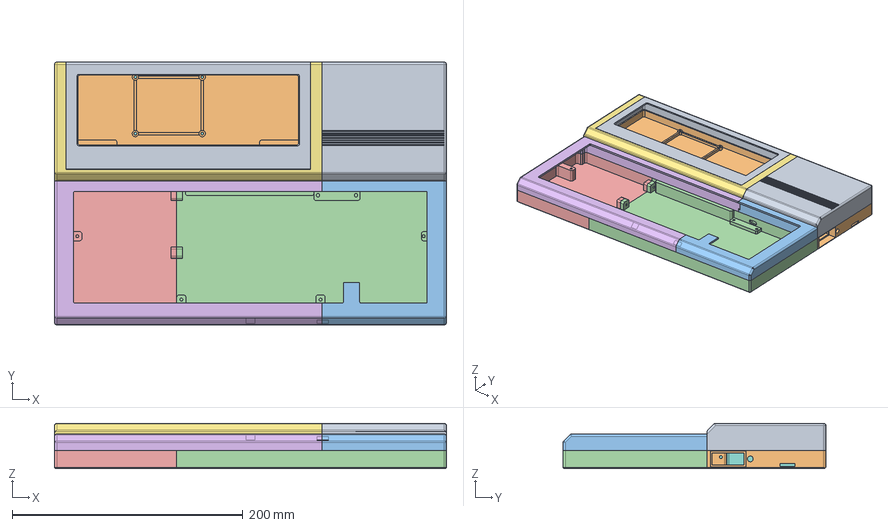
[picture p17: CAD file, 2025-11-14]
px-88/hardware/source-files/typeframe-px-88.step
340.0 x 228.1 x 39.4 mm
screen
hinge x 2
screen border
case
side
keyboard case

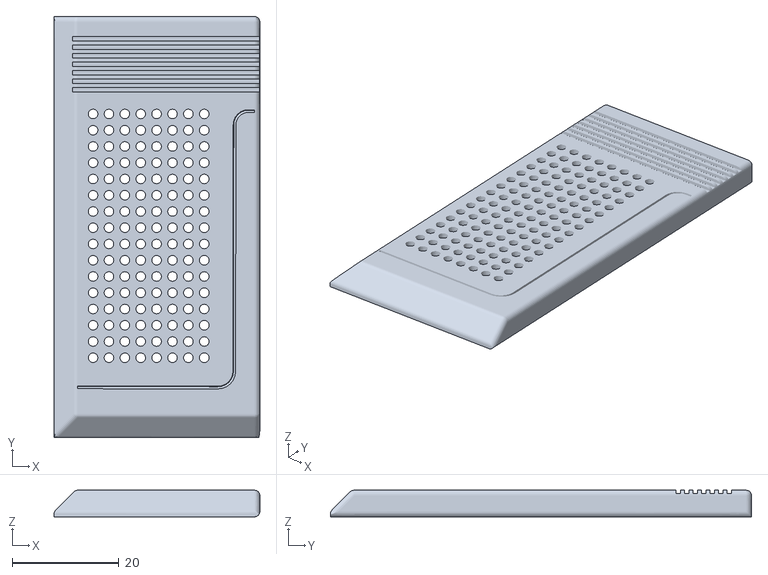
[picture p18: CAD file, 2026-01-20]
ps-85/hardware/print-files/STL/charlieplex.stl
38.6 x 79.0 x 5.00

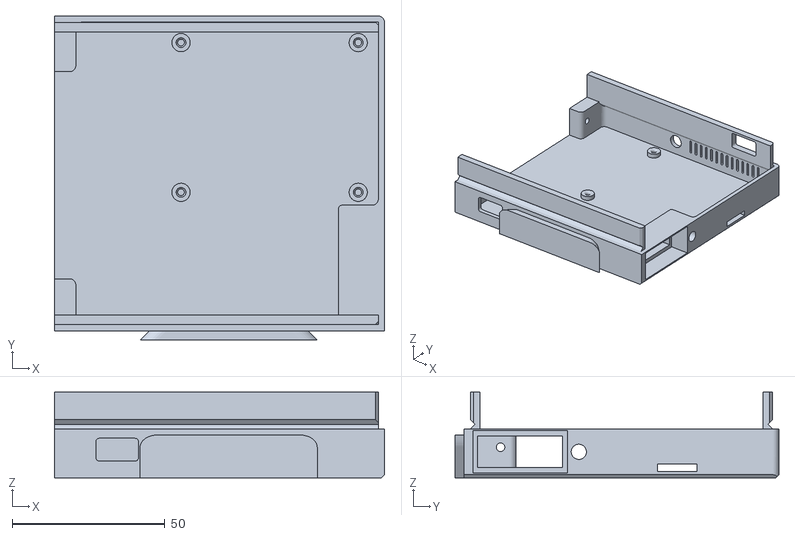
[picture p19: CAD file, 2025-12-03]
px-88/hardware/print-files/loose-tolerances/STL/side_bottom.stl
108.0 x 106.0 x 28.0

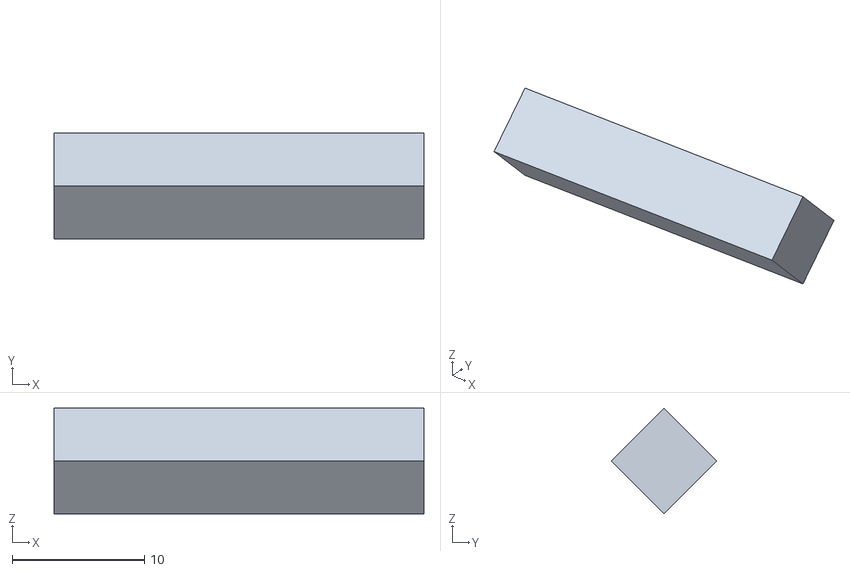
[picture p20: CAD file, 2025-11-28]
px-88/hardware/print-files/tight-tolerances/STL/hinge_shaft_x2_0mm.stl
28.0 x 8.00 x 8.00

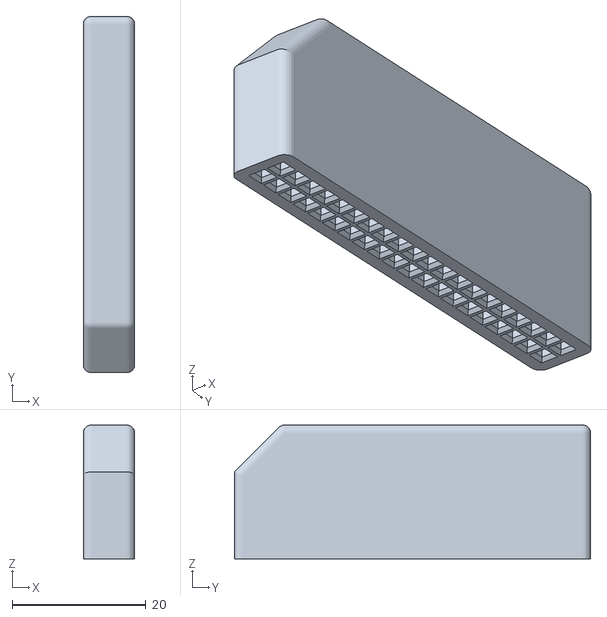
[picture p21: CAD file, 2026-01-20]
ps-85/hardware/print-files/STL/gpio_cover.stl
7.68 x 53.2 x 20.0

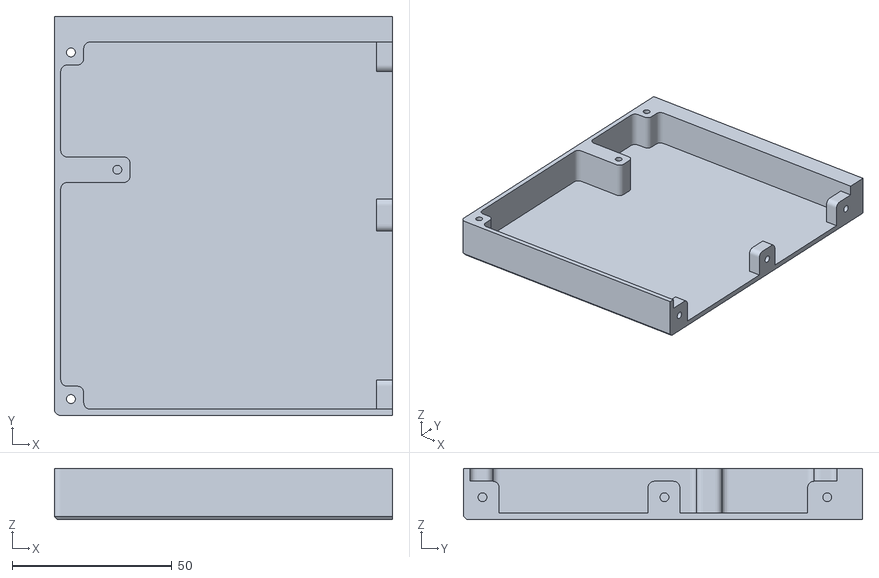
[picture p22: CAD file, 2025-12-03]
px-88/hardware/print-files/loose-tolerances/STL/keyboard_case_bottom_left.stl
106.0 x 125.0 x 16.0

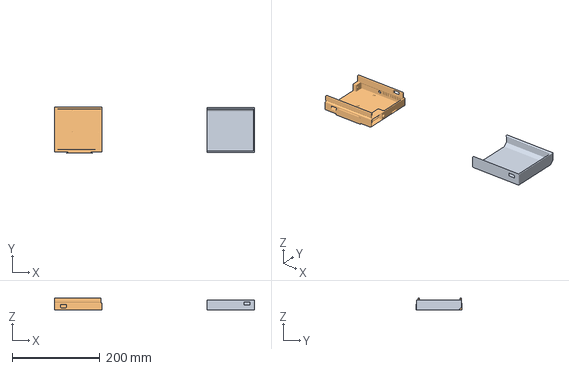
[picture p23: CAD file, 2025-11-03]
px-88/hardware/print-files/tight-tolerances/3MF/side.3mf
455.9 x 106.0 x 28.0 mm
side top
side bottom

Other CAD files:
px-88/hardware/print-files/tight-tolerances/STL/hinge_shaft_x2_0.05mm.stl
ps-85/hardware/print-files/STL/keyboard_plate.stl
px-88/hardware/print-files/loose-tolerances/STL/keyboard_case_top_right.stl
px-88/hardware/print-files/tight-tolerances/3MF/keyboard_case.3mf
ps-85/hardware/print-files/STL/handle.stl
ps-85/hardware/print-files/STL/keyboard_top.stl
ps-85/hardware/print-files/STL/screen_top.stl
ps-85/hardware/source-files/typeframe-ps-85.f3z
px-88/hardware/print-files/loose-tolerances/STL/badge_bottom.stl
px-88/hardware/print-files/loose-tolerances/STL/badge_top.stl
px-88/hardware/print-files/loose-tolerances/STL/case_lid.stl
px-88/hardware/print-files/loose-tolerances/STL/hinge_barrel_x2_0.05mm.stl
px-88/hardware/print-files/loose-tolerances/STL/hinge_barrel_x2_0.10mm.stl
px-88/hardware/print-files/loose-tolerances/STL/hinge_barrel_x2_0.15mm.stl
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

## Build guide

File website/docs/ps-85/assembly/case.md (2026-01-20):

---
title: Case
sidebar_position: 3
description: Putting everything together.
---

# Case Assembly

## Overview

This section covers the full assembly of the PS-85 case, including installing the electronics, screen, and keyboard. Familiarize yourself with the [electronics assembly](./electronics.md) guide first - there's less detail here as I'm assuming you already have an idea of how the electronics all connect. You can do most of the first steps in any order, just make sure you get the handle on before securing the battery. If you plan on [painting and weathering](./finishing.md), it will be easier to do that before final assembly.

## Main Assembly

### 1. Install PowerBoost, Switch and LEDs

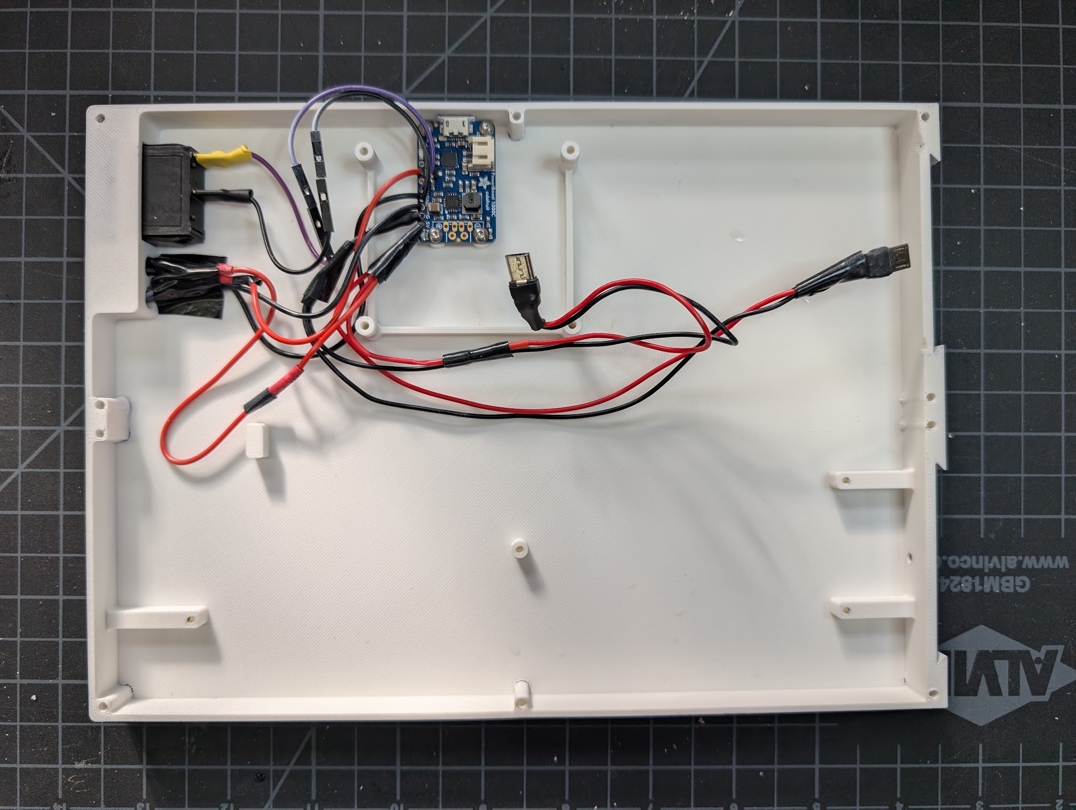
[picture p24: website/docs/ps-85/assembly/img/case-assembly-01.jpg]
Installing PowerBoost, Switch and LEDs


Screw the PowerBoost into the standoffs using four M2.5x4 screws. Insert the power switch from the outside of the case and the LEDs from the inside. You may need to tape down the LEDs to keep them in place.

### 2. Install Handle

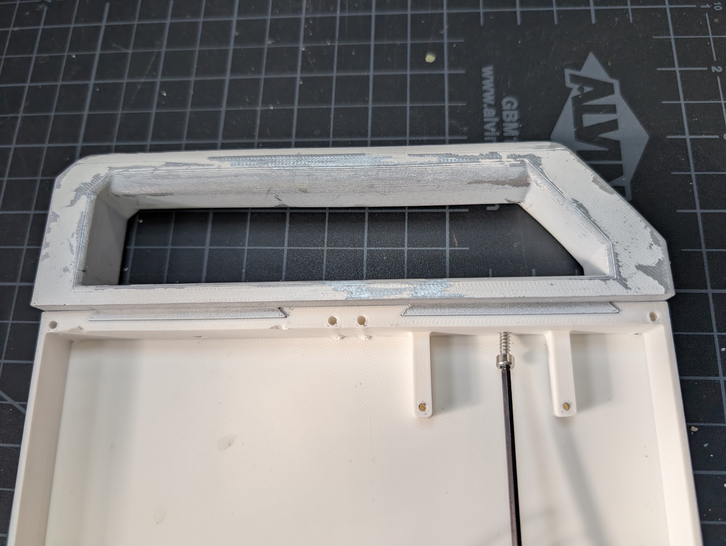
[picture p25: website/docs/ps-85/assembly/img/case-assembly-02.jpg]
Installing Handle


Slide the handle into the dovetail joints, then secure it with two M3x10 screws. A ball-end allen wrench will make this easier.

### 3. Install Keyboard and Keyboard Plate

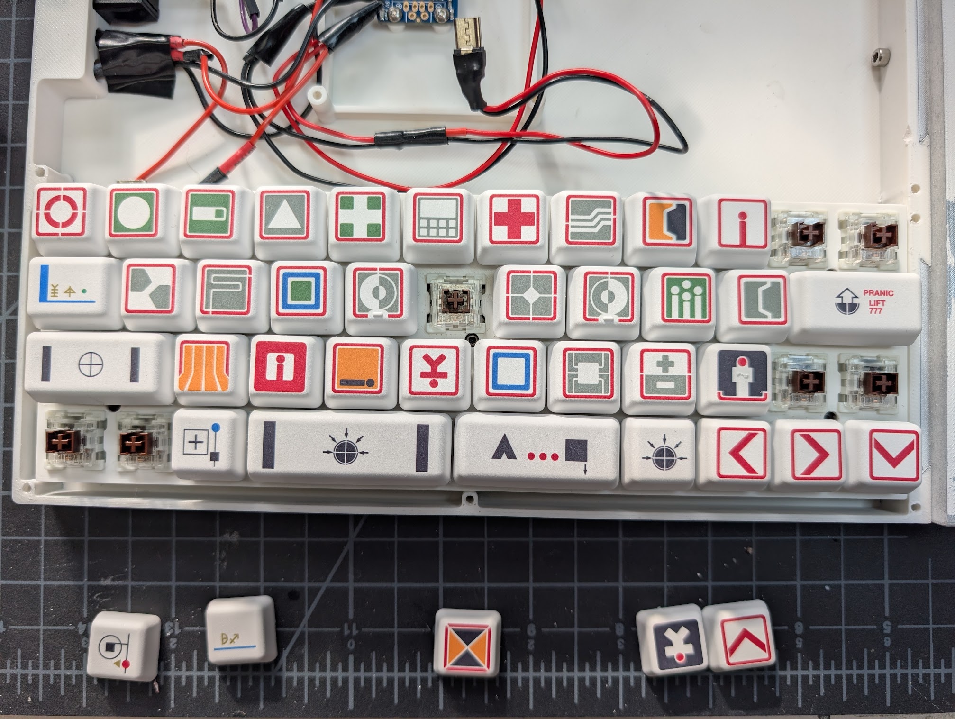
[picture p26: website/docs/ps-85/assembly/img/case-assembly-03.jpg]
Installing Keyboard and Keyboard Plate


I had the keyboard already assembled, so the photo here just shows the keys removed to access the PCB screws. But essentially you'll just need to secure the PCB to the case with four M2x4 screws - the switches will hold the plate in place once snapped in.

### 4. Install Pi Zero

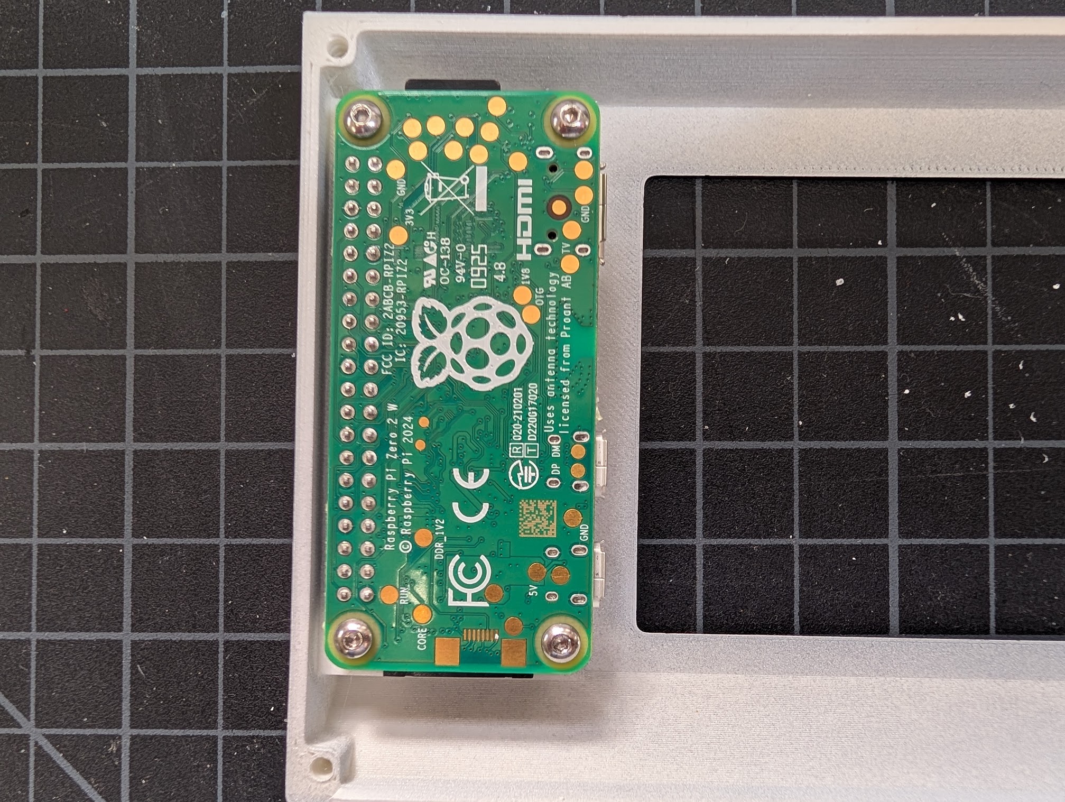
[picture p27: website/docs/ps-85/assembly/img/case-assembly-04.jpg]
Installing Pi Zero


Secure the Pi Zero to the standoffs on the screen top with four M2.5x8 screws.

### 5. Connect Electronics

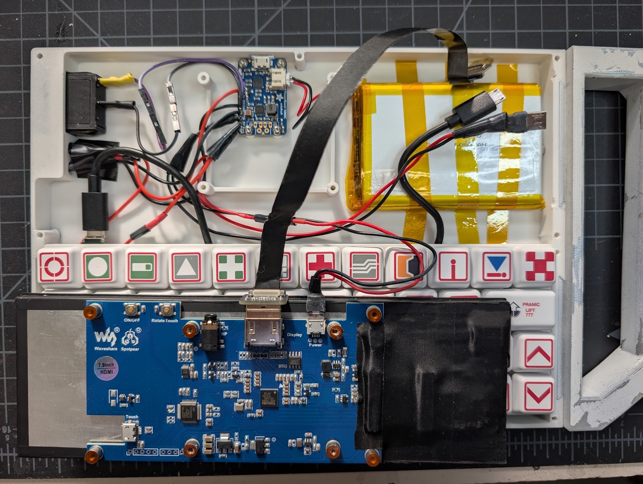
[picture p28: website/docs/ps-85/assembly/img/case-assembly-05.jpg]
Connecting Electronics


Plug in everything except the cables that go to the Pi. More details on this in the [electronics assembly](./electronics.md) guide. Secure the battery with the thermal tape and plug it into the PowerBoost.

### 6. Partly Install Screen

Screw in the screen from the bottom of the case _**only on the non-handle side**_ with two M2.5x20 screws. I found this was easiest from the bottom with the case hanging off the edge of a table. Be careful not to pinch any cables inside. Make sure the HDMI, power and keyboard cables are sticking out towards the handle.

### 7. Connect Cables to Pi

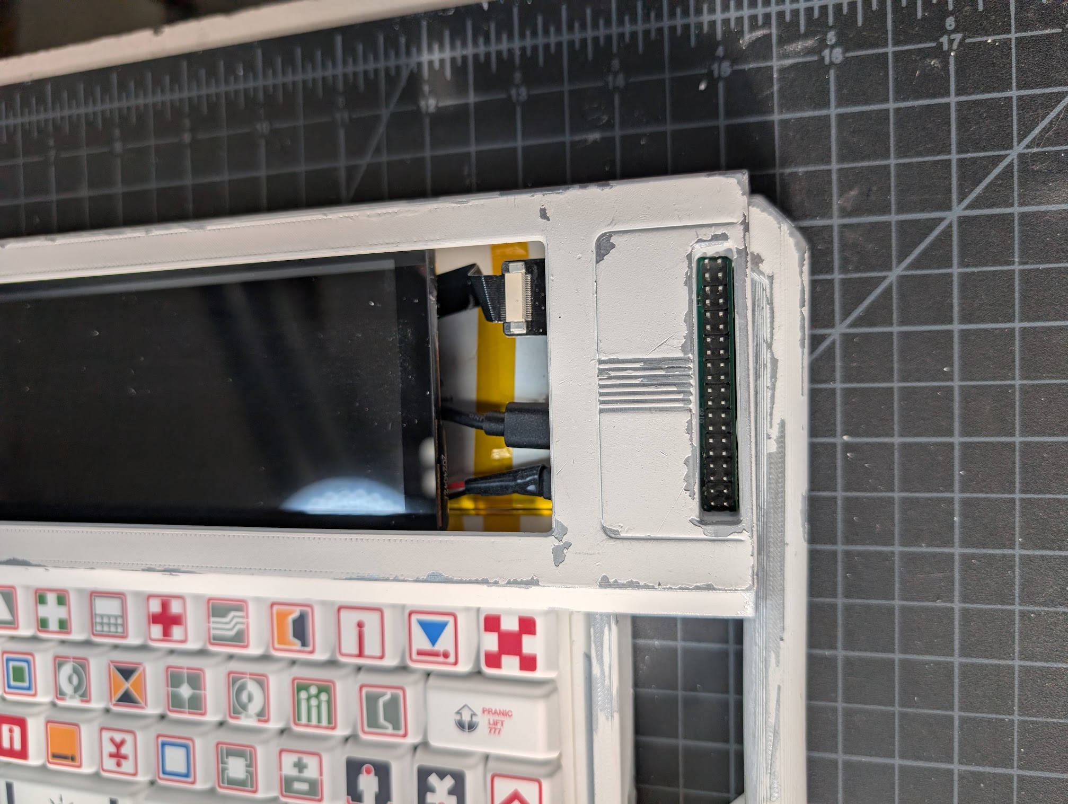
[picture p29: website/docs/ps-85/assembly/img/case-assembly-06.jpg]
Connecting Cables to Pi


Flip the screen top over and place it so it overlaps the screen, then plug the cables into the Pi. (Note the different PWR and USB labeled ports on the Pi Zero.) Then gently lift up the handle side of the screen so you can slide the cables under it and the screen top into place.

### 8. Finish Installing Screen

Screw in the remaining two M2.5x20 screws from the bottom to secure the left side of the screen.

### 9. Join Screen Top to Case Bottom

Using three M3x25 screws in the back and two M3x20 screws in the middle, secure the screen top to the case bottom.

### 10. Install Keyboard Top

Using five M3x16 screws, secure the keyboard top to the case bottom.

### 11. Grip Tape (Optional)

Optionally, you can apply grip tape to the bottom of the case for added traction.

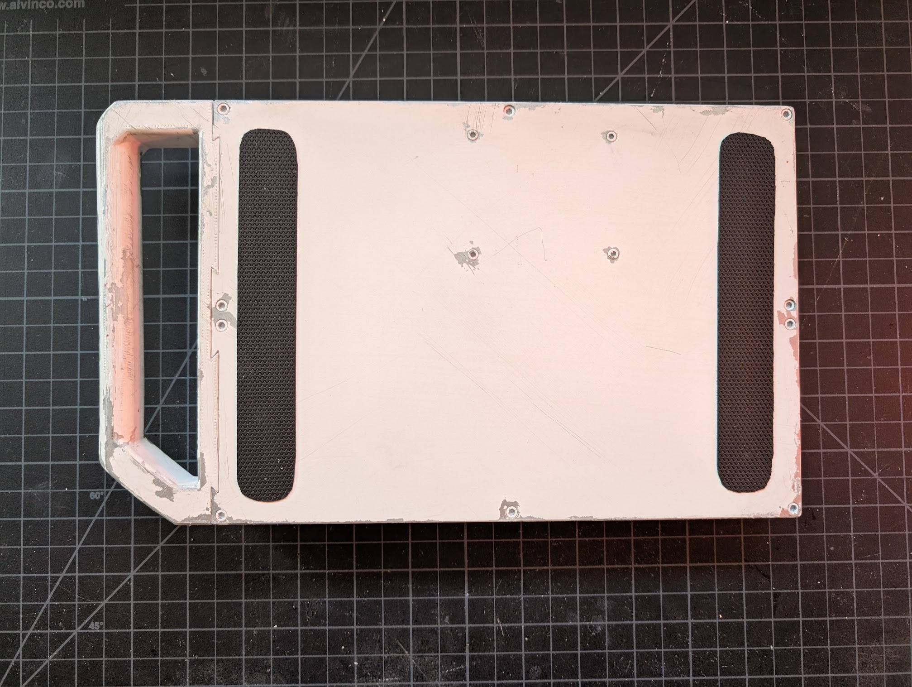
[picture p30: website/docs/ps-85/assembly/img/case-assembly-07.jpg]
Grip Tape


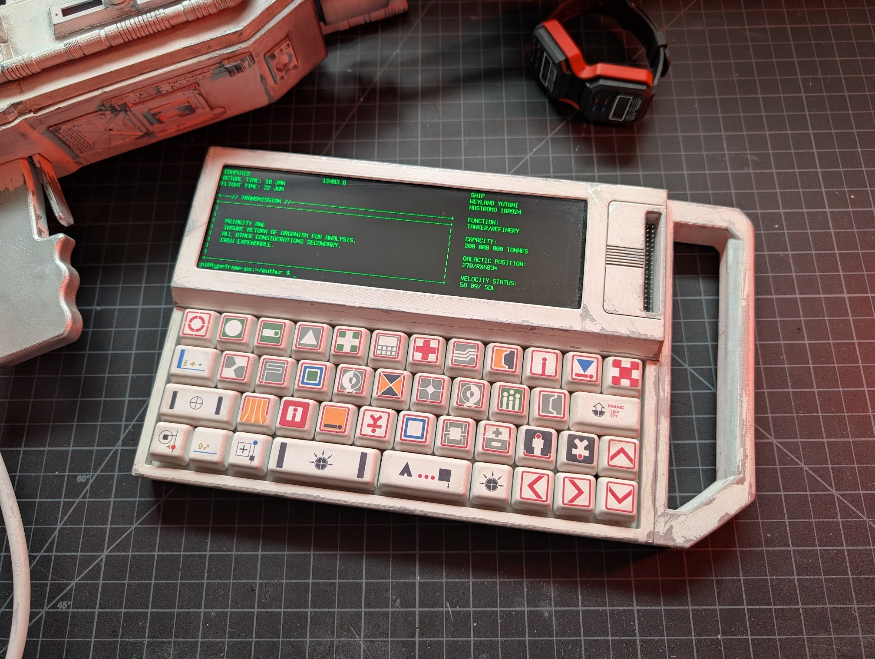
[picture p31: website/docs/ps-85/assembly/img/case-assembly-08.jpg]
Complete PS-85


Your PS-85 is now fully assembled!

## GPIO Cover (Optional)

The GPIO cover can be installed at any time. It just slots into the GPIO cutout.

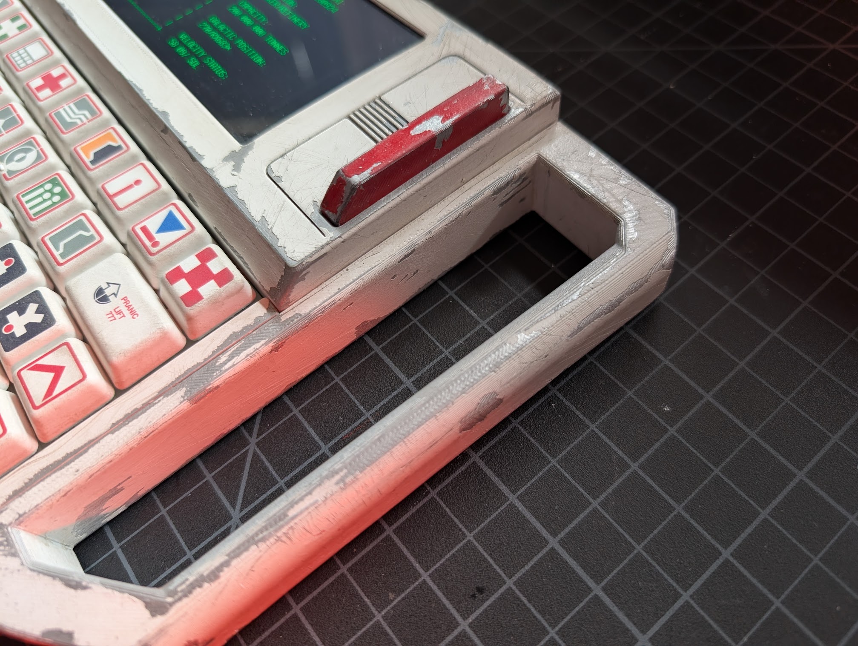
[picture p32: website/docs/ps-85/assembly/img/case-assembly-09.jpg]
Installing GPIO Cover


## MU/TH/UR LED Matrix (Optional)

This will be pretty self-explanatory, the cover for the CharliePlex just snaps on and you can plug the matrix into the Pi's GPIO pins using the riser.

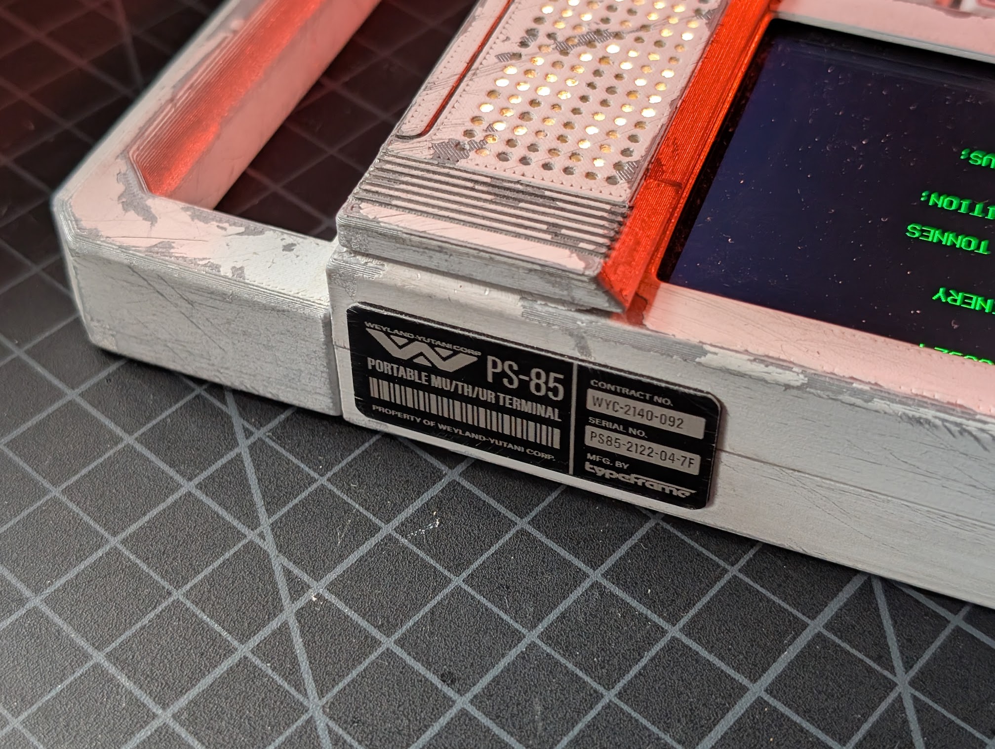
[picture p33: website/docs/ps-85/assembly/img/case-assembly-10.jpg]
Installing MU/TH/UR LED Matrix


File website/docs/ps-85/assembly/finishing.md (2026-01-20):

---
title: Finishing
sidebar_position: 4
description: Finishing touches
---

# Finishing Touches

## Painting and Weathering

I won't go into a ton of detail here, just the general process. For more details, check out OddViking on YouTube, his techniques for weathering stormtrooper armor work well here.

1. Spray the parts with a [metallic silver paint](https://www.amazon.com/dp/B000PQGE2M). Let dry.
2. Apply a masking agent (I used toothpaste) to the areas you want to be chipped. Let dry.
3. Spray the parts with a [satin white paint](https://www.amazon.com/dp/B002BWOS8A). Let dry.
4. Scrape off the masking agent with a fingernail and/or brush to reveal the silver underneath. (Easiest to do under running water.)
5. Add additional scratches with 80 grit sandpaper, a file or any other tools.
6. Assemble everything.
7. Apply an acrylic wash. Mix a bit of black and brown acrylic paint with water and carefully brush it onto the case, avoiding getting water on any electronics. Wipe off the excess with a towel. Let dry.

## Laser Engraved Badge

This was just an excuse for me to get a cheap laser engraver. The SVG for the badge can be found in the repository and will engrave on a 50mm x22mm (Approx. 2" x 1") metal plate [like these](https://www.amazon.com/dp/B0BMX68HGD).

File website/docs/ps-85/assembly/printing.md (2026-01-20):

---
title: Printing
sidebar_position: 1
description: Tips for printing.
---

# Printing the Case

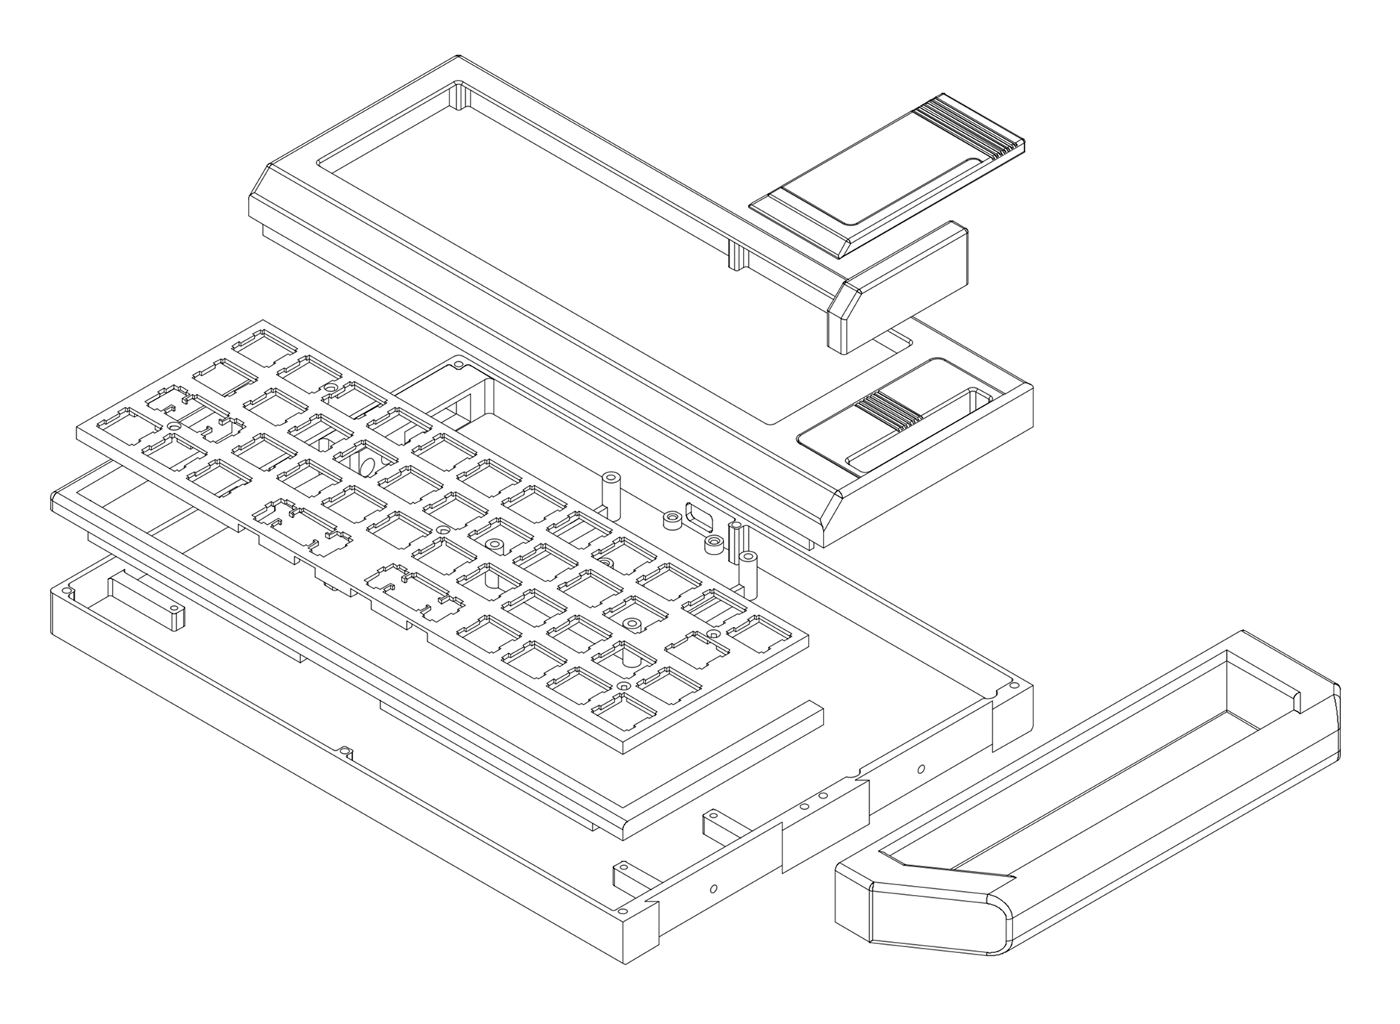
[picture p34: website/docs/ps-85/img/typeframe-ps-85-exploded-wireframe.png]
PS-85 Exploded Wireframe


## Overview

The case is split into parts that can be printed on an FDM printer with at least a 250mm x 200mm bed.

## Print Files

- [**3MF**](https://github.com/jeffmerrick/typeframe/tree/main/ps-85/hardware/print-files/3MF) - Saved from PrusaSlicer with painted-on supports. These should be ready to slice and print.
- [**STL**](https://github.com/jeffmerrick/typeframe/tree/main/ps-85/hardware/print-files/STL) - Raw STL files for each part.

## Source Files

- [**STEP**](https://github.com/jeffmerrick/typeframe/tree/main/ps-85/hardware/source-files/typeframe-ps-85.step) - STEP file of the entire assembly.
- [**F3Z**](https://github.com/jeffmerrick/typeframe/tree/main/ps-85/hardware/source-files/typeframe-ps-85.f3z) - Fusion 360 file. Fair warning that the timeline is a bit of a mess, though I did try to keep components named and somewhat organized.

## Keyboard Plate

I generated the keyboard plate using [Keyboard STL Generator](https://github.com/jeffminton/keyboard_stl_generator). I modified the exported file, so if you want to use a different keyboard you'll likely need to do the same. But this should get you most of the way there!

## Tolerances and Parameters

Default tolerances are pretty tight but worked for me on my Prusa MK4. If you run into issues, let me know which parts and I can try to export out STLs with looser tolerances.

### Default Tolerance Parameters

| Parameter | Value |
| --- | --- |
| `pressFitTolerance` | 0.00 mm |
| `closeFitTolerance` | 0.05 mm |
| `freeFitTolerance` | 0.1 mm  |
| `screwCounterboreDepth` | 2.8 mm  |
| `screwCounterboreDiameter` | 5 mm |
| `screwPassthroughDiameter` | 3 mm |
| `screwTappingDiameter` | 2.6 mm  |

## Changing Parameters in Fusion 360

If you need to customize the parameters further for your printer, you can open the F3Z file in Fusion 360 and modify them there.

1. Download [Fusion 360 for Personal Use](https://www.autodesk.com/products/fusion-360/personal).
2. Open the `typeframe-ps-85.f3z` file.
3. Go to the **Modify** menu and select **Change Parameters**. <br />
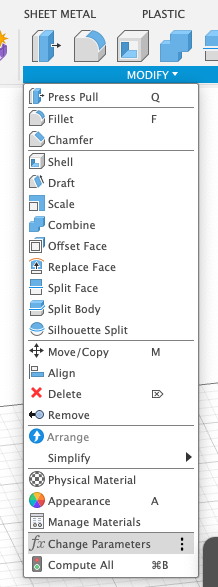
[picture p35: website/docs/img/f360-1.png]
   
4. Modify the parameters as needed.
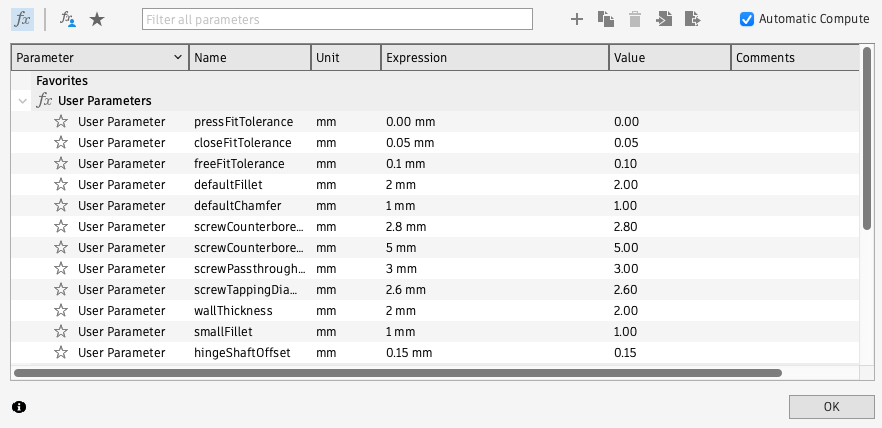
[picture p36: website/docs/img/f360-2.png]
   
5. You can now export new STL files with **File > Export**. Make sure only the part you want to export is visible in the browser. (Otherwise it seems to export out everything visible.)<br />
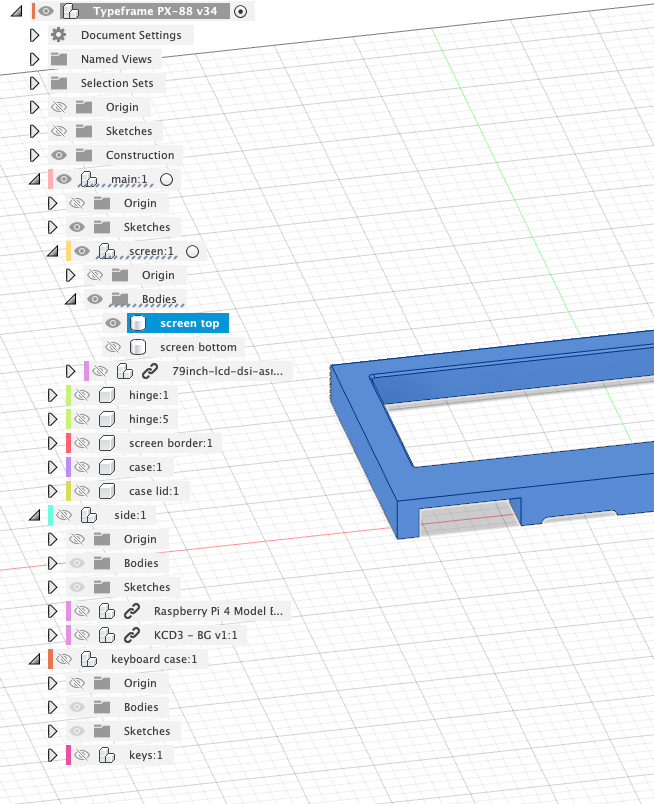
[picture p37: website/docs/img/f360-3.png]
   
6. Alternatively you may be able to send the selected part directly to your slicer with **File > 3D Print**. No need to hide the other parts this way.

## Supports

The files print pretty well with minimal supports. But you will need supports for some parts, mostly for the larger port holes. The 3MF files have supports painted on.

## Print Settings

I printed on a Prusa MK4 with a 0.4mm nozzle and 0.2mm layer height using PLA filament. I had the best results with a smooth PEI sheet for bed adhesion. For the case bottom I used helper discs to keep the corners from lifting. You may also want to use a brim for some parts if you have adhesion issues.

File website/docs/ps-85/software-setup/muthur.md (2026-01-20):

---
title: MU/TH/UR LED Matrix
sidebar_position: 5
description: Light up the LED Matrix
---

# MU/TH/UR LED Matrix

If you opted to include the [MU/TH/UR](https://en.wikipedia.org/wiki/MU_/_TH_/_UR) LED Matrix in your PS-85 build, you can set it up to display a simple blinking pattern similar that seen in the Alien movies.

The CharliePlex LED Matrix Bonnet is well documented over on [Adafruit's website](https://learn.adafruit.com/adafruit-charlieplex-bonnet/python-examples) if you want to explore more functionality.

### 1. Installation

1. Make the MU/TH/UR Directory

   ```bash
   cd /home/pi
   mkdir muthur
   cd muthur
   ```

2. Download the Script and Bash Files

   ```bash
   wget https://raw.githubusercontent.com/jeffmerrick/typeframe/main/ps-85/software/muthur/lights.py
   wget https://raw.githubusercontent.com/jeffmerrick/typeframe/main/ps-85/software/muthur/start.sh
   wget https://raw.githubusercontent.com/jeffmerrick/typeframe/main/ps-85/software/muthur/stop.sh
   chmod +x start.sh stop.sh
   ```

3. Create Virtual Environment

   ```bash
   python3 -m venv venv
   ```

4. Activate Virtual Environment

   ```bash
   source venv/bin/activate
   ```

5. Install Dependencies

   ```bash
   pip install adafruit-circuitpython-is31fl3731 adafruit-circuitpython-framebuf RPi.GPIO Pillow
   ```

6. Enable I2C (if not already enabled)

   ```bash
   sudo raspi-config nonint do_i2c 0
   ```

### 2. Controlling the Lights

#### Manually with the Python script

With the virtual environment activated:

```bash
python3 lights.py
```

```bash
python3 lights.py off
```

When you're done:

```bash
deactivate
```

#### With the Bash scripts

To turn on the lights:

```bash
./start.sh
```

To turn off the lights:

```bash
./stop.sh
```

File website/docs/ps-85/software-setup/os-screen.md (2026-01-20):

---
title: OS & Screen
sidebar_position: 2
description: Installing Raspberry Pi OS and configuring the display.
---

## Flash OS & Boot

### 1. Flash Raspberry Pi OS Trixie

1. Connect the SD card to your computer
2. Download and use [Raspberry Pi Imager](https://www.raspberrypi.com/software/) to flash the latest Raspberry Pi OS Lite (64-bit) - Trixie to the SD card.

:::tip[OS customization]

I highly recommend configuring WiFi and SSH options in the imager under **"OS customization -> Edit Settings"**. This will allow the Pi to connect to your WiFi right after the first boot, and you can SSH in to more easily configure it. You can choose a hostname and username. For the purposes of this guide, we'll assume the hostname is `typeframe-ps.local` and the username is `pi`. Leaving the username as `pi` will make things easier on you later as it's hardcoded in some scripts.

:::

### 2. Configure Display Support

1. After image flashing is completed, open the `config.txt` file in the root directory of the SD card.
2. Add the following code at the end of `config.txt`, save, and safely eject the SD card:

   ```
   hdmi_group=2
   hdmi_mode=87
   hdmi_timings=400 0 220 32 110 1280 0 10 10 10 0 0 0 60 0 59400000 3
   ```

If you boot before adding this, you can SSH into the Pi and edit the file in `/boot/firmware/config.txt`. Then reboot. (Side note: everything seems to work fine without this, but it's in the Waveshare documentation so I included it here.)

### 3. First Boot

1. Insert the SD card into the Raspberry Pi.
2. Plug the USB power cable into the Pi.
3. The Raspberry Pi will power on - wait for a few seconds for the display to initialize.
4. You're booted up and should be in the terminal.

## SSH into the Raspberry Pi

If you configured WiFi and SSH in the imager, you can SSH into the Pi from your computer using the hostname you set (e.g., `typeframe-ps.local`):

```bash
ssh pi@typeframe-ps.local
```

This will allow you to copy and paste commands more easily than working directly on the PS-85.

## Screen Rotation Configuration

The default display orientation is portrait. We want it to be landscape. You'll need to set this in two places: one for the desktop environment and one for the terminal.

### Terminal Configuration

1. To rotate the display in the terminal, open the boot command line for editing.

   ```bash
   sudo nano /boot/firmware/cmdline.txt
   ```

2. Add the following command to the **beginning** of the first line in `cmdline.txt`, followed by a space before the existing `console=` parameter:

   ```bash
   video=HDMI-A-1:400x1280M@60,rotate=270
   ```

   **For example:** If your `cmdline.txt` currently starts with `console=tty1 root=PARTUUID=...`, change it to:

   ```
   video=HDMI-A-1:400x1280M@60,rotate=270 console=tty1 root=PARTUUID=...
   ```

3. Save the file and exit `(Ctrl+X, Y, Enter)`.

4. Restart to apply the rotation.

   ```bash
   sudo reboot
   ```

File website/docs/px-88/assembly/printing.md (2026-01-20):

---
title: Printing
sidebar_position: 1
description: Tips for printing.
---

# Printing the Case

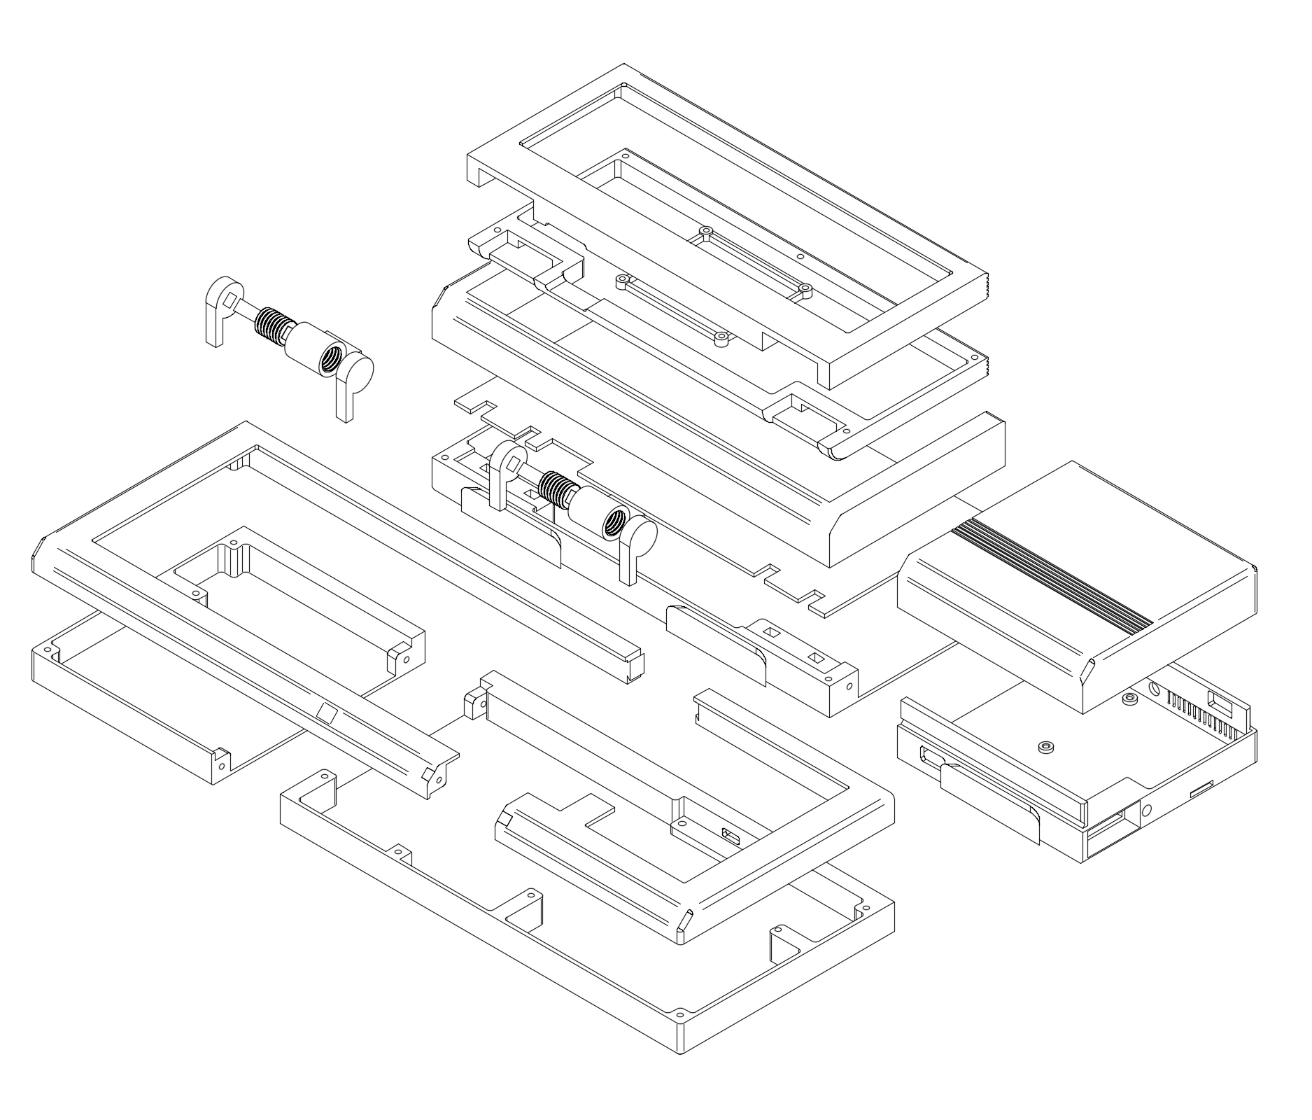
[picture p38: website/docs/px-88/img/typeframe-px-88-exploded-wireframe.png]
PX-88 Exploded Wireframe


## Overview

The case is split into parts that can be printed on an FDM printer with at least a 232mm x 130mm bed.

## Print Files

### Tight Tolerances

- [**3MF**](https://github.com/jeffmerrick/typeframe/tree/main/px-88/hardware/print-files/tight-tolerances/3MF) - Saved from PrusaSlicer with painted-on supports. These should be ready to slice and print.
- [**STL**](https://github.com/jeffmerrick/typeframe/tree/main/px-88/hardware/print-files/tight-tolerances/STL) - Raw STL files for each part. Parts with multiples are suffixed with `_x#`.

### Loose Tolerances

- [**STL**](https://github.com/jeffmerrick/typeframe/tree/main/px-88/hardware/print-files/loose-tolerances/STL) - Raw STL files for each part. Parts with multiples are suffixed with `_x#`.

_See more on tolerances below._

## Source Files

- [**STEP**](https://github.com/jeffmerrick/typeframe/tree/main/px-88/hardware/source-files/typeframe-px-88.step) - STEP file of the entire assembly.
- [**F3Z**](https://github.com/jeffmerrick/typeframe/tree/main/px-88/hardware/source-files/typeframe-px-88.f3z) - Fusion 360 file. Fair warning that the timeline is a bit of a mess, though I did try to keep components named and somewhat organized.

## Tolerances and Parameters

Default tolerances are pretty tight but worked for me on my Prusa MK4. However, others had trouble with them on other printers so I've included a set of STLs with looser tolerances as well. Each set also includes hinge parts with a few different offsets

### Default Tight Tolerance Parameters

| Parameter | Value |
| --- | --- |
| `pressFitTolerance` | 0.00 mm |
| `closeFitTolerance` | 0.05 mm |
| `freeFitTolerance` | 0.1 mm  |
| `screwCounterboreDepth` | 2.8 mm  |
| `screwCounterboreDiameter` | 5 mm |
| `screwPassthroughDiameter` | 3 mm |
| `screwTappingDiameter` | 2.6 mm  |

### Loose Tolerance Parameters

| Parameter | Value |
| --- | --- |
| `pressFitTolerance` | 0.05 mm |
| `closeFitTolerance` | 0.15 mm |
| `freeFitTolerance` | 0.2 mm  |
| `screwCounterboreDepth` | 2.8 mm  |
| `screwCounterboreDiameter` | 5.2 mm  |
| `screwPassthroughDiameter` | 3.2 mm  |
| `screwTappingDiameter` | 2.8 mm  |

### Hinge Tolerances

The **`hingeShaftOffset`** determines the resistance level of the hinges. You want this quite tight as they will loosen over time. The offset you need will vary depending on your printer and print settings. I was able to print with a 0mm offset and get the shaft into the slider a plumbers wrench. I've included versions with a 0.05mm, 0.10mm, and 0.15mm offset for you to try out as well. In addition if you have trouble screwing the slider into the barrel, I've included versions of the barrel with the same offsets as well.

## Changing Parameters in Fusion 360

If you need to customize the parameters further for your printer, you can open the F3Z file in Fusion 360 and modify them there.

1. Download [Fusion 360 for Personal Use](https://www.autodesk.com/products/fusion-360/personal).
2. Open the `typeframe-px-88.f3z` file.
3. Go to the **Modify** menu and select **Change Parameters**. <br />
   Fusion 360 Change Parameters
4. Modify the parameters as needed.
   Fusion 360 Change Parameters
5. You can now export new STL files with **File > Export**. Make sure only the part you want to export is visible in the browser. (Otherwise it seems to export out everything visible.)<br />
   Fusion 360 Change Parameters
6. Alternatively you may be able to send the selected part directly to your slicer with **File > 3D Print**. No need to hide the other parts this way.

## Supports

The files print pretty well with minimal supports. But you will need supports for some parts, mostly for the larger port holes. The 3MF files have supports painted on.

## Print Settings

I printed on a Prusa MK4 with a 0.4mm nozzle and 0.2mm layer height using PLA filament. I had the best results with a smooth PEI sheet for bed adhesion since there are some large parts.

## Credits

The ingenious friction hinge design is from [KatDelgado on Printables](https://www.printables.com/model/658393-friction-hinge-mechanism). Thanks to the detailed information there, I was able to adapt it for this project.

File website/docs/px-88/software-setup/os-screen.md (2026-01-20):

---
title: OS & Screen
sidebar_position: 2
description: Installing Raspberry Pi OS and configuring the display.
---

## Flash OS & Boot

### 1.Flash Raspberry Pi OS Trixie

1. Connect the SD card to your computer
2. Download and use [Raspberry Pi Imager](https://www.raspberrypi.com/software/) to flash the latest Raspberry Pi OS (64-bit) - Trixie to the SD card.

:::tip[OS customization]

I highly recommend configuring WiFi and SSH options in the imager under **"OS customization -> Edit Settings"**. This will allow the Pi to connect to your WiFi right after the first boot, and you can SSH in to more easily configure it. You can choose a hostname and username. For the purposes of this guide, we'll assume the hostname is `typeframe.local` and the username is `pi`. Leaving the username as `pi` will make things easier on you later as it's hardcoded in some scripts.

:::

### 2. Configure Display Support

1. After image flashing is completed, open the `config.txt` file in the root directory of the SD card.
2. Add the following code at the end of `config.txt`, save, and safely eject the SD card:

   ```
   dtoverlay=vc4-kms-v3d
   # DSI1 Use (recommended for Pi4B)
   dtoverlay=vc4-kms-dsi-waveshare-panel,7_9_inch
   # DSI0 Use (alternative)
   # dtoverlay=vc4-kms-dsi-waveshare-panel,7_9_inch,dsi0
   ```

If you boot before adding this, you can SSH into the Pi and edit the file in `/boot/firmware/config.txt`. Then reboot.

### 3. First Boot

1. Insert the SD card into the Raspberry Pi.
2. Plug the USB power cable into the Pi, _not_ the Power Management HAT if you have it installed.
3. The Raspberry Pi will power on - wait for a few seconds for the display to initialize.
4. You're booted up - the touch screen should work, but you'll still need to rotate the screen.

## SSH into the Raspberry Pi

If you configured WiFi and SSH in the imager, you can SSH into the Pi from your computer using the hostname you set (e.g., `typeframe.local`):

```bash
ssh pi@typeframe.local
```

This will allow you to copy and paste commands more easily than working directly on the PX-88.

## Screen Rotation Configuration

The default display orientation is portrait. We want it to be landscape. You'll need to set this in two places: one for the desktop environment and one for the terminal.

### 1. Desktop Configuration

1. Open **"Control Centre" → "Screens"** from the desktop menu. _In older versions of Raspberry Pi OS, this may be under "Preferences" → "Screen Configuration"._

2. Go to **"Screens" → "DSI-2" → "Orientation"**, choose "Right", and finally click **"Apply"** to complete the display and touch synchronous rotation.

For detailed steps with images, see the [Waveshare wiki documentation](https://www.waveshare.com/wiki/7.9inch_DSI_LCD#Bookworm_Touch_Screen_Rotation).

### 2. Disable the On-Screen Keyboard

By default, the on-screen keyboard will pop up whenever you select a text field. You'll find the option to disable it under **"Control Centre" → "Display" → "On-Screen Keyboard"**. Select **"Disabled"**.

### 3. Terminal Configuration

1. To rotate the display in the terminal, open the boot command line for editing.

   ```bash
   sudo nano /boot/firmware/cmdline.txt
   ```

2. Add the following command to the **beginning** of the first line in `cmdline.txt`, followed by a space before the existing `console=` parameter:

   ```bash
   video=DSI-1:400x1280e,rotate=270
   ```

   **For example:** If your `cmdline.txt` currently starts with `console=tty1 root=PARTUUID=...`, change it to:

   ```
   video=DSI-1:400x1280e,rotate=270 console=tty1 root=PARTUUID=...
   ```

3. Save the file and exit `(Ctrl+X, Y, Enter)`.

4. Restart to apply the rotation.

   ```bash
   sudo reboot
   ```

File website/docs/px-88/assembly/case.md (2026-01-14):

---
title: Case
sidebar_position: 3
description: Putting everything together.
---

# Case Assembly

## Overview

This section covers the full assembly of the PX-88 case, including installing the electronics, screen, and keyboard. Familiarize yourself with the [electronics assembly](./electronics.md) guide first - there's less detail here as I'm assuming you already have an idea of how the electronics all connect.

## Keyboard

### 1. Join Case Bottom Halves

Using two M3x10 screws and one M3x12 screw, join the two bottom halves of the keyboard case together. The longer screw goes in the front. You may want to use a ball-end allen wrench here as the angle is somewhat awkward.

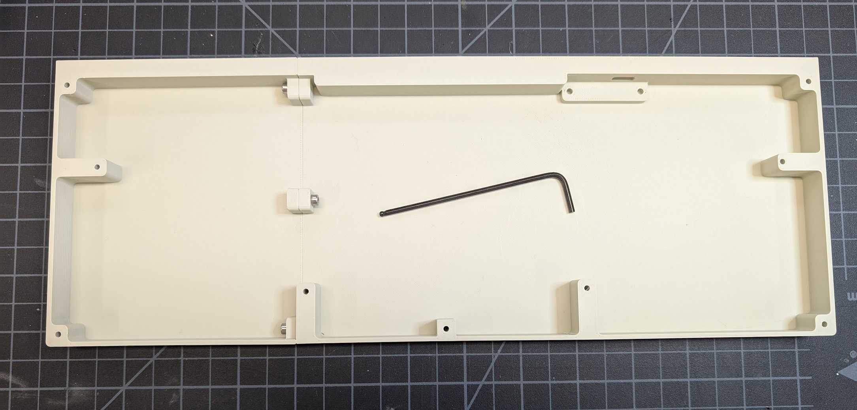
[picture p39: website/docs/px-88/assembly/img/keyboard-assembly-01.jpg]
Joining Bottom Halves


### 2. Install the Keyboard Daughterboard

Using two M3x6 screws, install the keyboard daughterboard into the bottom of the case. Plug the included cable into the daughterboard.

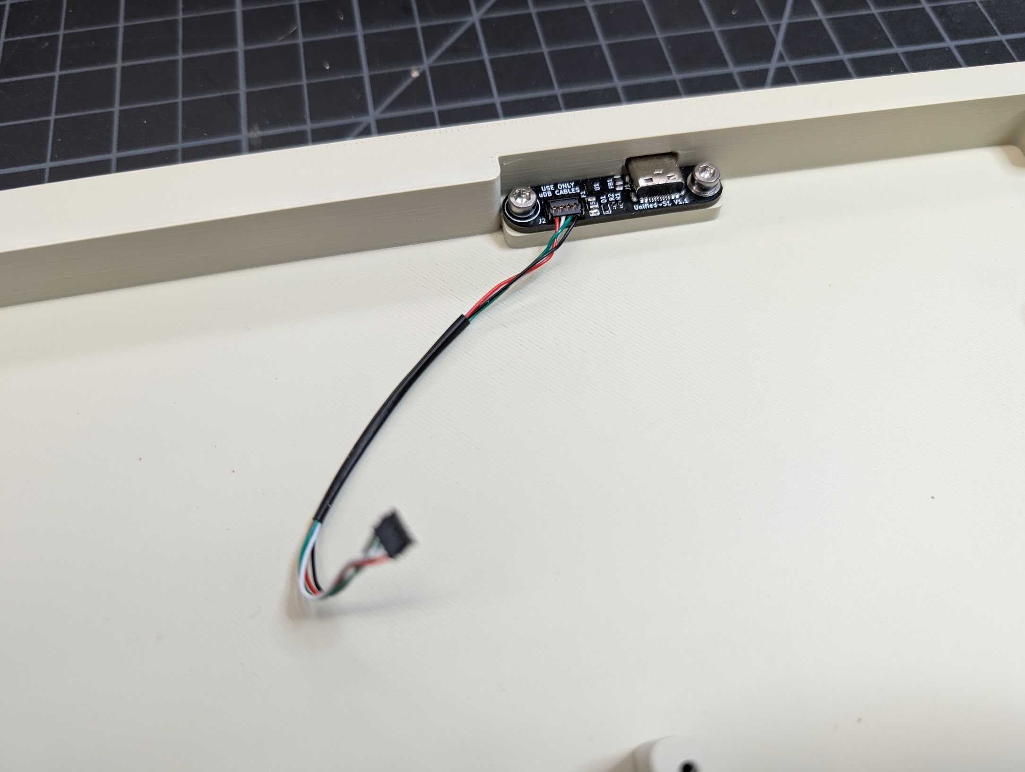
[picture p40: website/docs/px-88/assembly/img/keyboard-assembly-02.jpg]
Install Daughterboard


### 3. Install the Keyboard Stabilizers

Using the included hardware, install the keyboard stabilizers into the PCB.

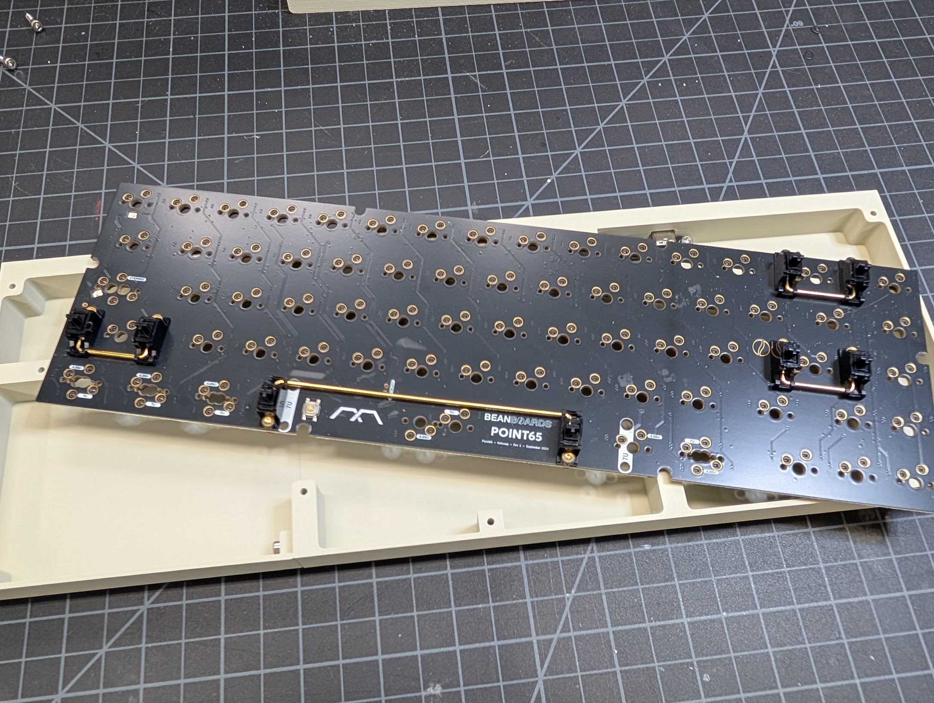
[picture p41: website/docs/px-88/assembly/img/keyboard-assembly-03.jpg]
Install Stabilizers


### 4. Connect the Daughterboard to the Keyboard PCB

Connect the daughterboard cable to the bottom of the keyboard PCB.

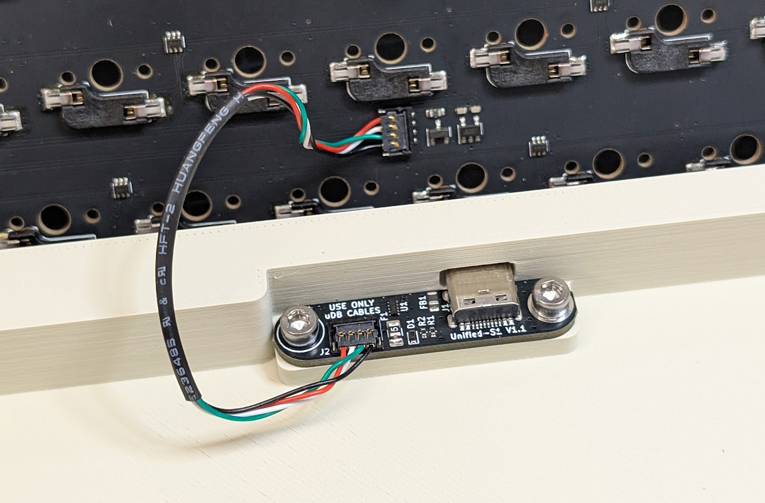
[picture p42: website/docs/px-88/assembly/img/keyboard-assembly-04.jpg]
Connect Daughterboard Cable


### 5. Install the Keyboard PCB

Using the 4 M3x10 screws, install the keyboard PCB into the case. I used M3 washers here as well, but it seemed to work fine without them. You'll see a rubber band on the back of the PCB in the photo - this was to prevent the PCB from flexing down when typing, but it ended up being unnecessary.

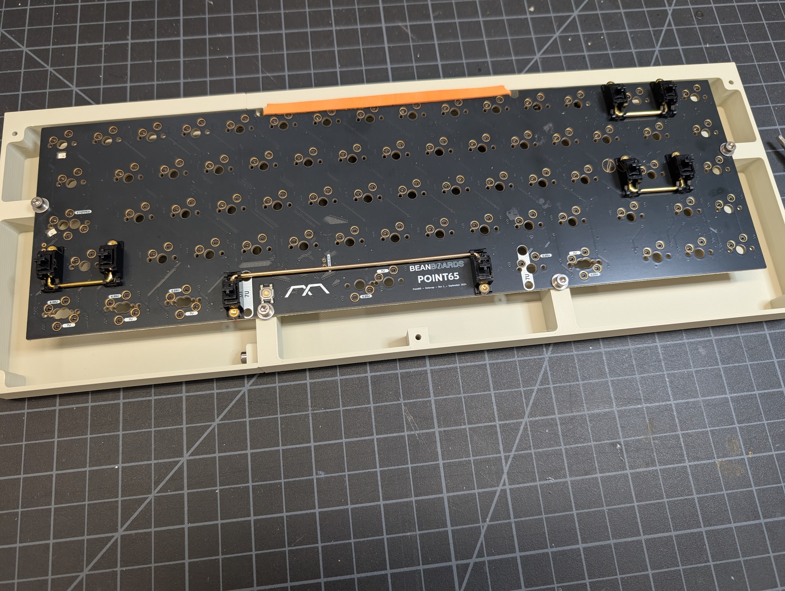
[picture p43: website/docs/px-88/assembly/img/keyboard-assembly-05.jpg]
Install Keyboard PCB


### 6. Join the Case Top Halves

Slide the two top halves of the keyboard case together at the dovetail in the back. Then, using one M3x10 screw, connect them in the front. The screw will stick out a little bit but that's okay.

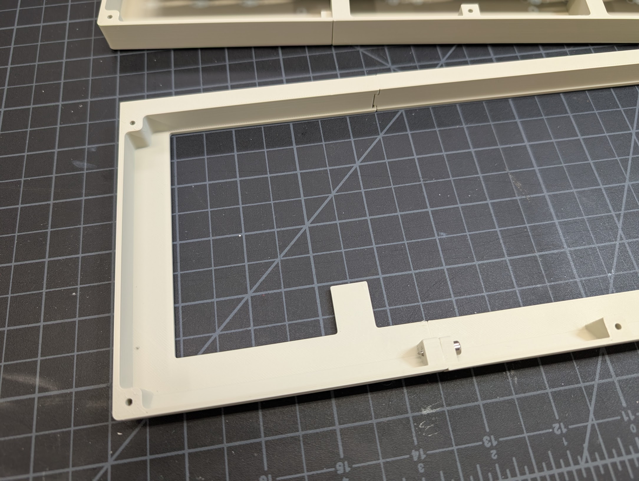
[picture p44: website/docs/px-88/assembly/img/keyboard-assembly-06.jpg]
Join Top Halves


### 7. Join the Top and Bottom Halves

Using five M3x20 screws, join the top and bottom halves of the keyboard case together.

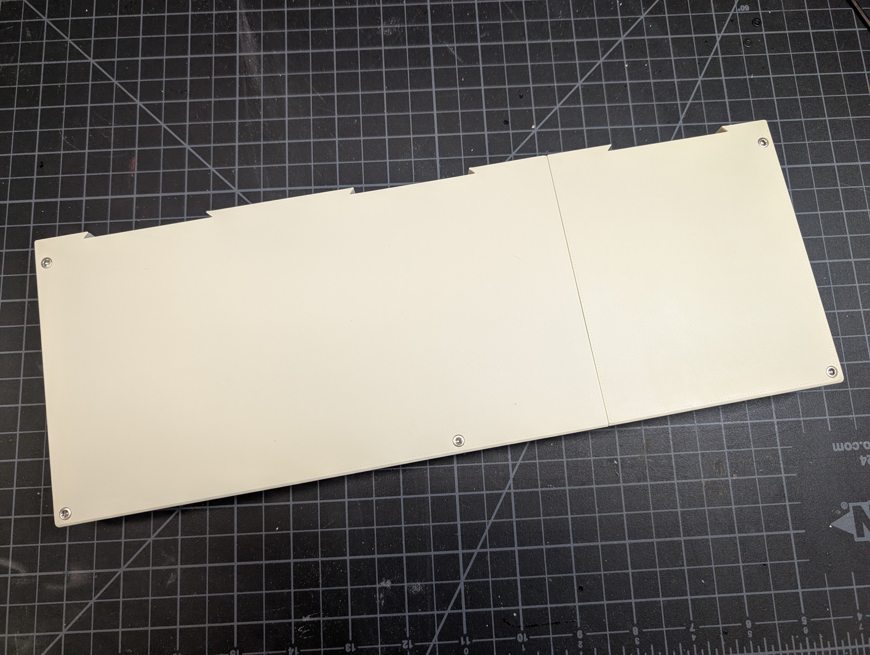
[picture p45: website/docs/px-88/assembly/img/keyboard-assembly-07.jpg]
Join Top and Bottom Halves


### 8. Install Switches and Keycaps

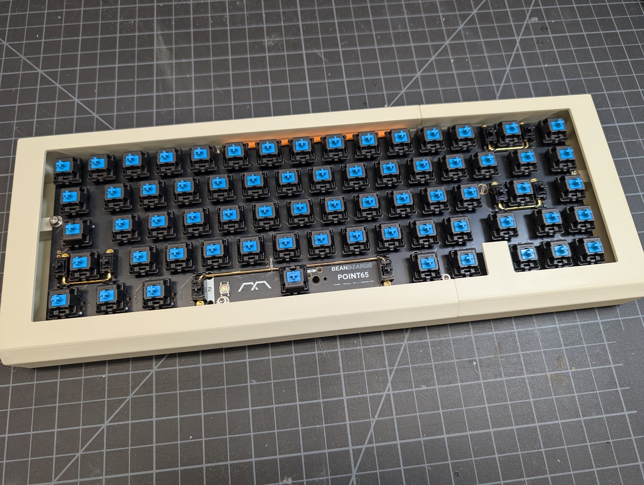
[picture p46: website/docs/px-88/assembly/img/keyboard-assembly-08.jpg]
Install Switches

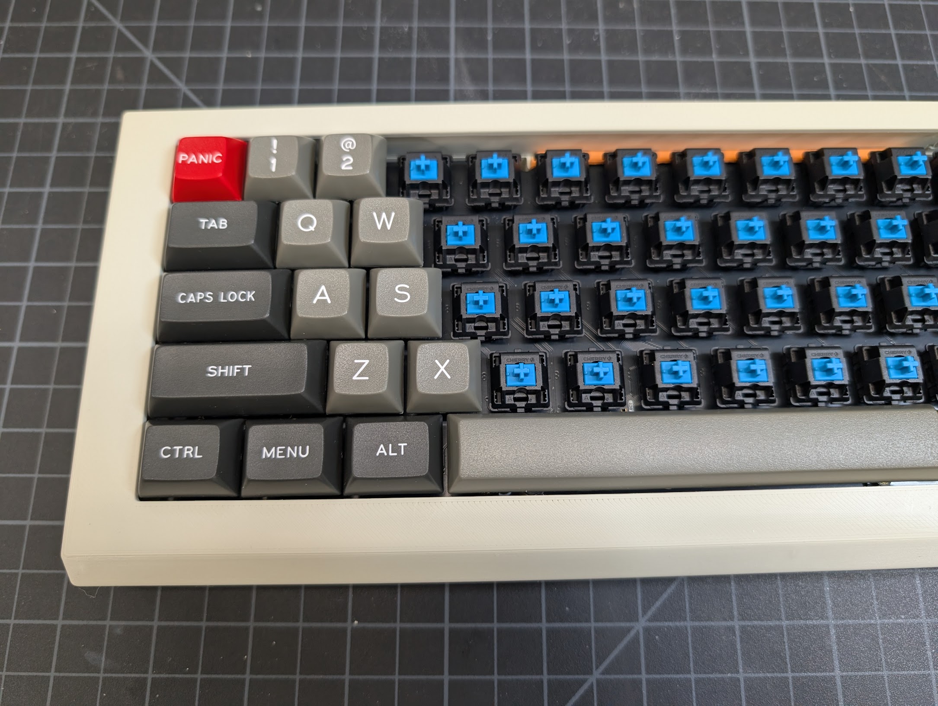
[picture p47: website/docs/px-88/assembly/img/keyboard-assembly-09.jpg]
Install Keycaps


**Congratulations!** You now have a finished keyboard! You can use it with or without the rest of the PX-88 case. Just connect it via USB-C to your computer.

## Case Bottom

### 1. Join the Case Bottom Halves

Using two M3x14 screws, join the two bottom halves of the case together.

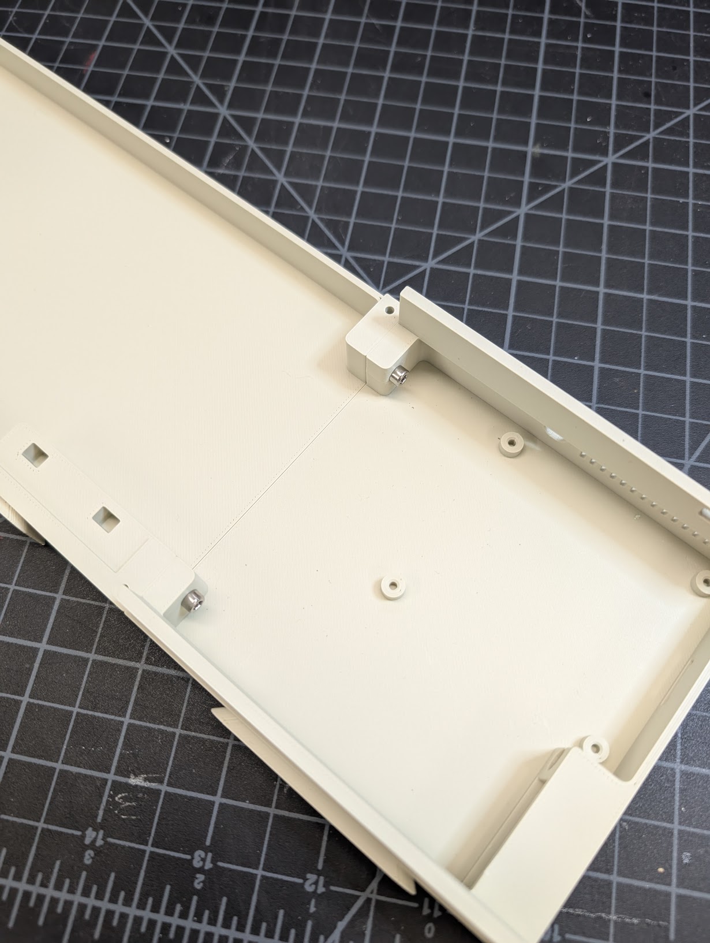
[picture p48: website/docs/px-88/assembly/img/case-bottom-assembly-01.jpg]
Join Case Bottom Halves


### 2. Add the Screen Frame

Flip over the case bottom. Using 4 M3x20 screws, attach the screen frame to the bottom half of the case.

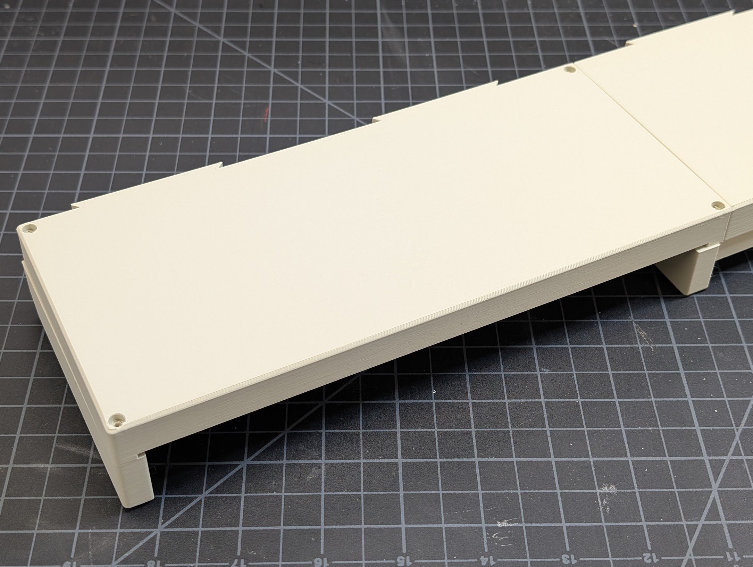
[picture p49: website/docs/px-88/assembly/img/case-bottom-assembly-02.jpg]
Add Screen Frame


### 3. Install the Battery

Make sure you have the extension cable connected to the battery. (I don't in the photo, but it's easier to do in this step.) Secure the battery in the left side of the case bottom using thermal tape.

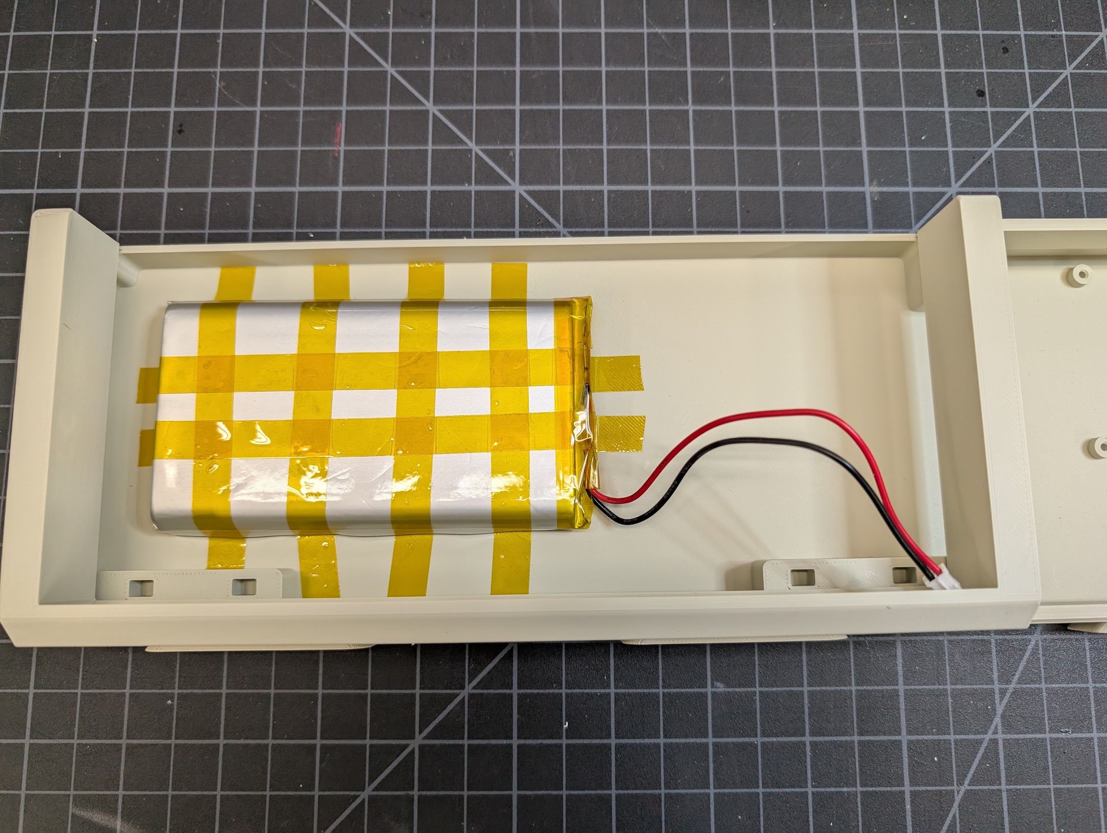
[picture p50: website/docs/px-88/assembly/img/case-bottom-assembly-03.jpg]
Install Battery


## Screen

### 1. Attach the Screen to the Screen Back

1. Attach the DSI cable and 4 pin cable (+ extension jumpers) to the screen as described in the [electronics assembly](./electronics.md) guide.

2. Using four M2.5x12 screws, attach the screen to the screen back at the screen's four standoff mounting points.

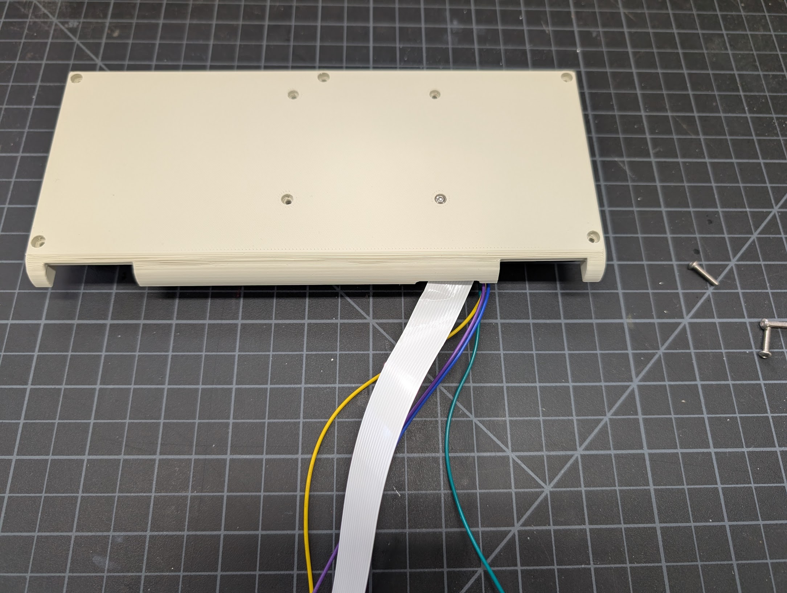
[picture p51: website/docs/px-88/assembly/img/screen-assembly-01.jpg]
Attach Screen Back


### 2. Join the Screen Back to the Front

Using five M3x16 screws, join the screen back and the screen front, being careful not to pinch any cables.

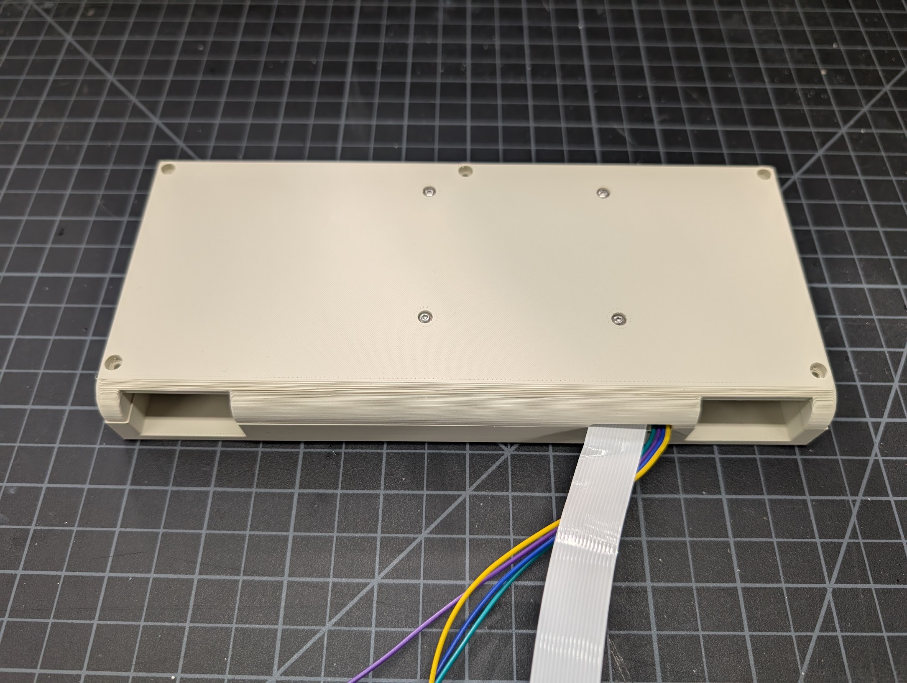
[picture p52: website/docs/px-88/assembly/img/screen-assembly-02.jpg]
Join Screen Back to Front


### 3. Assemble the Hinges

:::warning[Hinge Update Coming]
The hinges seem to get loose pretty quickly with normal usage and have trouble holding up the screen. I plan to revisit them in the future, but just be aware you'll likely experience this issue.
:::

This ingenious friction hinge design was created by [KatDelgado on Printables](https://www.printables.com/model/658393-friction-hinge-mechanism). The shaft that goes into the threaded slider should be very tight as this is what provides the resistance and keeps the screen upright. No glue should be required.

1. Insert the shaft into the threaded slider.
2. Screw the shaft into the hinge body.
3. Add the caps on each end.

Repeat for the other hinge.

Assemble Hinges

### 4. Attach the Hinges to the Screen

Slide the hinges into the slots on the bottom of the screen assembly.

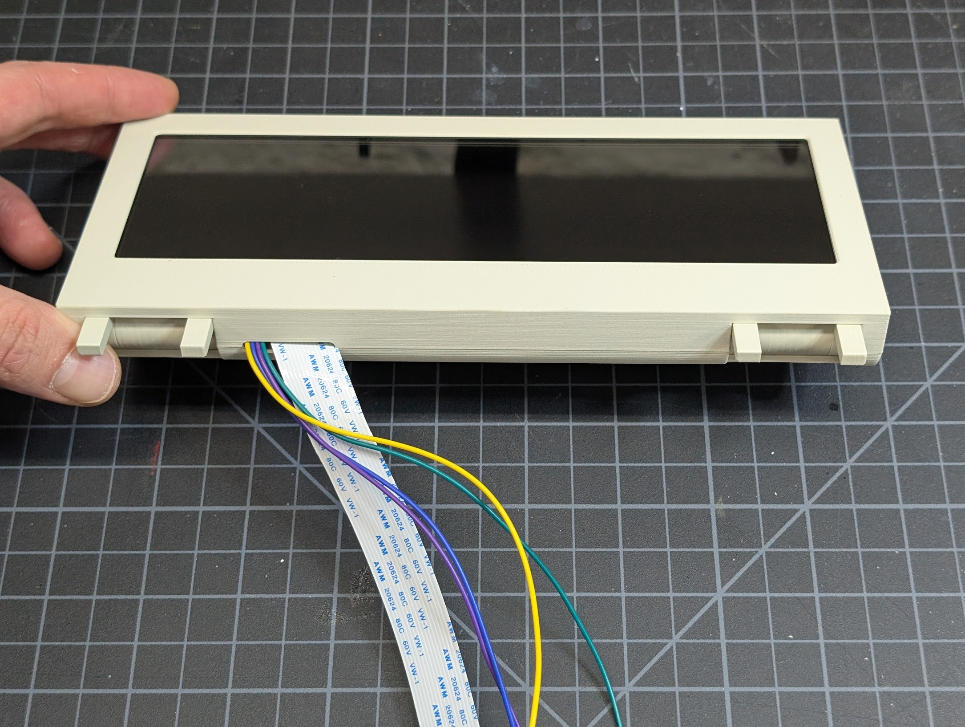
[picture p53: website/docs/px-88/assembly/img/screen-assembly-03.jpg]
Attach Hinges to Screen


### 5. Route the Screen Cables Through the Case Bottom

1. Route the DSI cable and 4 pin cable through the case bottom next to the battery.
2. Slide the case lid into place.

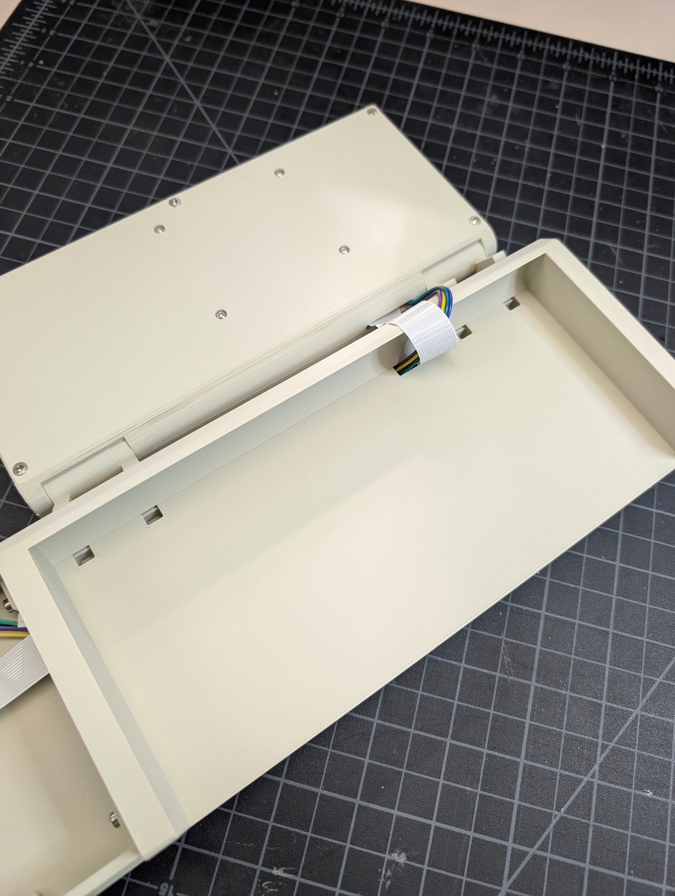
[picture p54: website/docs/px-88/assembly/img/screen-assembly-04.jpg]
Route Screen Cables


### 6. Attach the Screen Assembly to the Case Bottom

Slide the hinges into the slots on the front of the case bottom.

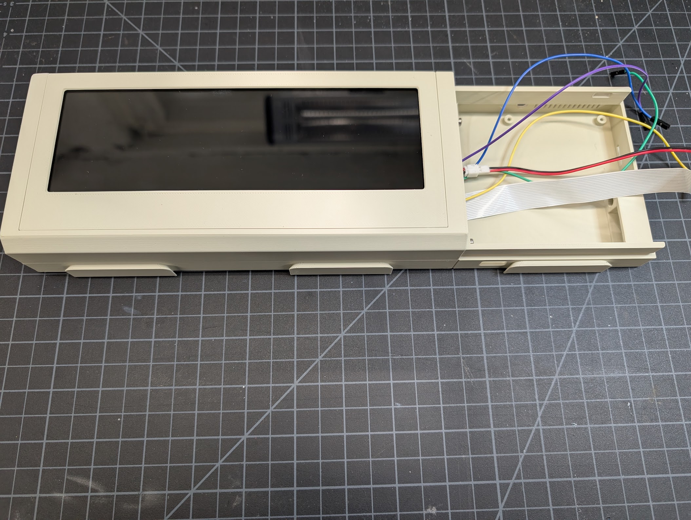
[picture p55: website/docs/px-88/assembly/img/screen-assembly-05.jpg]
Attach Screen Assembly to Case Bottom


## Case Side

:::danger[Stop! Set up software first!]

You must at least install the [Power Management HAT Firmware](../software-setup/power-management-hat.md) before this step. It requires connecting the Pi directly to power and the Pi's USB-C power port will be inaccessible once it's in the case.

:::

### 1. Install the Raspberry Pi in the Case

Using the standoffs included with the Power Management HAT, install the Raspberry Pi into the case side. I found using the included M2.5 screws to assist in screwing in the standoffs made it easier. You may also want to plug in the keyboard USB cable now. I didn't in the photo and it was awkward to do later.

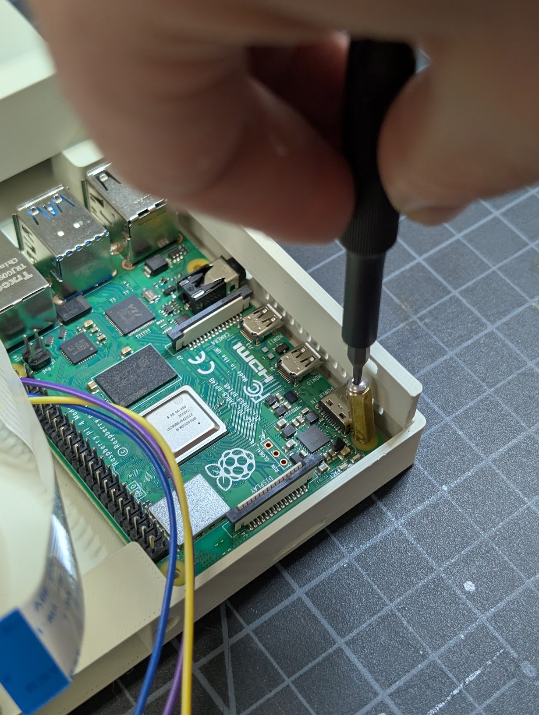
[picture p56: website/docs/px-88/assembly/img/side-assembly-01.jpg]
Install Raspberry Pi


### 2. Connect Screen to the Pi

1. Connect the DSI cable to the DSI port on the Raspberry Pi.
2. Route the battery cable on top of the Pi.

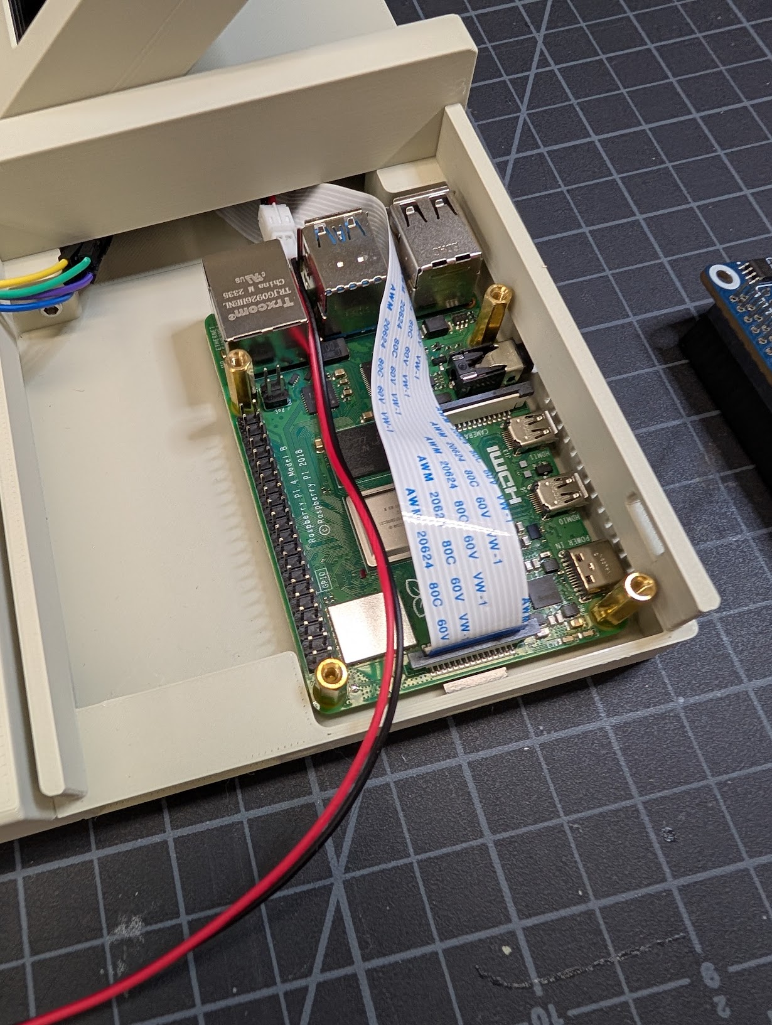
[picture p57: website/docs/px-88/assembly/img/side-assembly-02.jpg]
Connect Screen to Pi


### 3. Install the Power Switch

Follow the [electronics assembly](./electronics.md#power-switch) guide to solder the wires to the switch and Power Management HAT. Note that if you don't use Dupont jumpers you'll need to install the power switch with wires attached into the case before soldering the wires to the HAT.

1. Slide the power switch into the case side from the outside of the case.
2. Connect power switch jumper cables to jumper cables soldered to the Power Management HAT.

### 4. Install the Power Management HAT

1. Align the Power Management HAT with the GPIO pins on the Raspberry Pi and press down firmly to seat it.
2. Secure the HAT with the included M2.5 screws.

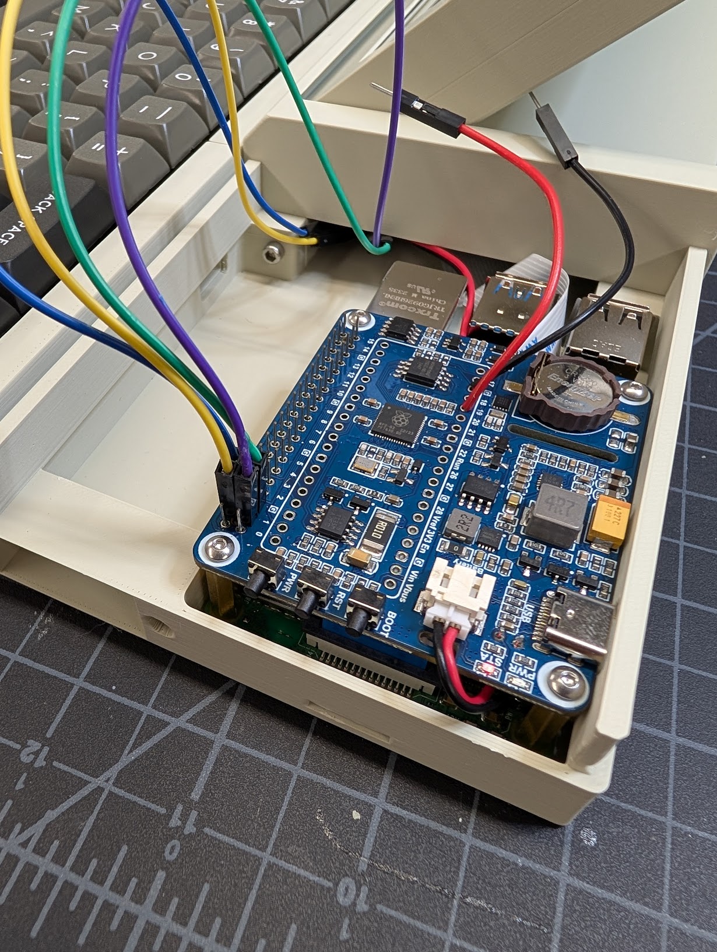
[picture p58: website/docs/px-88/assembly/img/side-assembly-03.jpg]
Install Power Management HAT


### 5. Install the Status LED

Follow the [electronics assembly](./electronics.md#status-led) guide to solder the jumper wires and resistor to the LED.

1. Insert the LED into the hole next to the power switch from the inside of the case.
2. Connect the LED jumper cables to the proper GPIO pins on the Power Management HAT header.

### 6. Connect the Keyboard to the Case

1. Slide the keyboard down onto the dovetails on the front of the case.
2. Plug the keyboard into the USB-C cable that's connected to the Pi.

### 7. Final Connections

1. Plug the battery cable into the Power Management HAT.
2. Plug the 4 pin screen cable into the Power Management HAT header as outlined in the [electronics assembly](./electronics.md#2-connect-the-4-pin-cable-to-the-gpio-header) guide.

Here's what everything looks like when fully connected:

Final Connections

### 8. Close the Case Side

Slide the case side top half from the right into the rails on the bottom half.

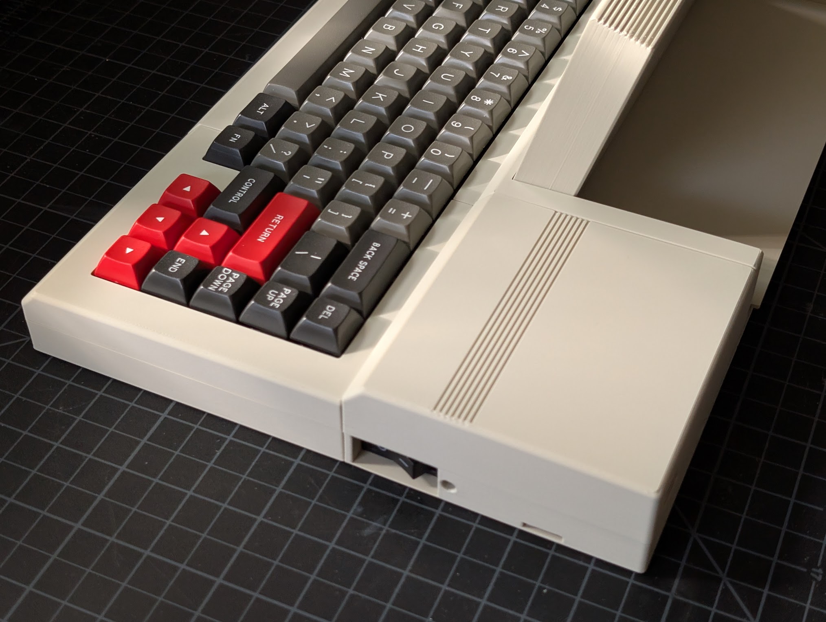
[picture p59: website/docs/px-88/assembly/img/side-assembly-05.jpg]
Close Case Side


:::success[Congratulations!]
You have finished assembling the PX-88!
:::

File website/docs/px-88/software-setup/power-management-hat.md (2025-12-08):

---
title: Power Management HAT
sidebar_position: 3
description: Flash the firmware for the Power Management HAT.
---

# Power Management HAT Setup

This section details the necessary steps to configure the HAT for Button Control (Power ON/Soft Shutdown) using a `systemd` service and the Waveshare provided example firmware.

I had to make some changes to the official Waveshare guide to get it working; this is what worked for me. For complete documentation, see the [Waveshare Power Management HAT (B) Wiki](<https://www.waveshare.com/wiki/Power_Management_HAT_(B)>).

## Set Up RP2040 Development Tools

This prepares the Raspberry Pi to compile and flash the firmware for the HAT's onboard RP2040 microcontroller.

1. Configure Pico Compile Environment:

   ```bash
   cd ~
   wget https://raw.githubusercontent.com/raspberrypi/pico-setup/master/pico_setup.sh
   chmod +x pico_setup.sh
   ./pico_setup.sh
   sudo reboot
   ```

2. Install and Compile OpenOCD:

   ```bash
   cd ~/pico
   sudo apt install automake autoconf build-essential texinfo libtool libftdi-dev libusb-1.0-0-dev
   git clone https://github.com/raspberrypi/openocd.git --recursive --branch rp2040-v0.12.0 --depth=1

   cd openocd
   ./bootstrap
   ./configure --enable-ftdi --enable-sysfsgpio --enable-bcm2835gpio
   make -j3
   sudo make install
   ```

## Install Soft Shutdown Script

This ensures the Raspberry Pi OS runs a script to listen for the shutdown signal from the HAT.

1. Download and Extract Files:

   ```bash
   cd ~
   wget https://files.waveshare.com/upload/4/44/Power-Management-HAT.zip
   unzip Power-Management-HAT.zip

   # Move the Python script
   sudo mkdir -p $HOME/bin/PowerManagementHAT
   sudo mv -f ~/Power-Management-HAT/StatusDetection.py $HOME/bin/PowerManagementHAT/
   ```

2. Create the `systemd` Service File:

   ```bash
   sudo nano /etc/systemd/system/waveshare-shutdown.service
   ```

   Paste and save (Ctrl+X, Y, Enter) the following configuration:

   ```ini
   [Unit]
   Description=Waveshare Power HAT Shutdown Monitor
   After=multi-user.target

   [Service]
   Type=simple
   User=root
   Group=root
   ExecStart=/usr/bin/python3 /home/pi/bin/PowerManagementHAT/StatusDetection.py
   Restart=always
   RestartSec=5
   StandardOutput=journal
   StandardError=journal

   [Install]
   WantedBy=multi-user.target
   ```

3. Enable and Start the Service:

   ```bash
   sudo systemctl daemon-reload
   sudo systemctl enable waveshare-shutdown.service
   sudo systemctl start waveshare-shutdown.service
   ```

## Enable UART Listening

For the battery status to work, enable UART on the Raspberry Pi. This will allow the RP2040 to send battery status data to the Pi.

```bash
sudo raspi-config nonint do_serial 1
```

You can also find this in the `raspi-config` interface under **"Interface Options" → "Serial Port"**.

## Compile and Flash the Button Firmware

This final step flashes firmware that enables button control.

:::warning[Check Power Connection]
Make sure you have power connected directly to the Pi and not the Power Management HAT before proceeding with the firmware flashing. The HAT will restart and we don't want the Pi to lose power during this process.
:::

### 1. Get Demo Source Code

```bash
cd ~
wget https://files.waveshare.com/upload/2/27/Power-example.7z
7z x ./Power-example.7z
```

### 2. Edit Source Code to Enable Button Demo

Open the main C file (`~/Power-example/Power_Management_HAT.c`) and enable the `Button_Ctr_` lines while commenting out the `Period_Time_` lines.

```c
   int main()
   {
   /* Initialize function */
   Button_Ctr_Init();
   //Period_Time_Init();
   //Cycle_Time_Init();

   /*Calls loop functions*/
   while (true)
   {
      Button_Ctr_Loop();
      //Period_Time_Loop();
      //Cycle_Time_Loop();
   }

   return 0;
   }
```

### 3. Compile the Firmware

```bash
cd ~/Power-example/build/
export PICO_SDK_PATH=/home/pi/pico/pico-sdk
cmake ..
make -j
```

### 4. Flash the Firmware to the HAT

Place the HAT in **BOOTSEL mode**, then run:

```bash
openocd -f interface/raspberrypi-swd.cfg -f target/rp2040.cfg -c "program ./Power_Management_HAT.elf verify reset exit"
```

### 5. Confirm the Firmware is Working

Unplug the USB cable from the Pi, reconnect it to the Power Management HAT. You can now use the onboard power button to turn the Pi on and off.

---

## Default Button Behavior

Once the firmware is running, the onboard PWR button will function as follows:

| Action | Duration | Result |
| :--- | :--- | :--- |
| **Power On** | Short Press (< 2 seconds) | The HAT powers the Raspberry Pi on. |
| **Soft Shutdown**  | Long Press (> 4 seconds but < 8 seconds) | Pi executes a soft shutdown, and the HAT cuts power. |
| **Hard Power Off** | Very Long Press (> 8 seconds) | HAT immediately cuts power to the Pi. |

---

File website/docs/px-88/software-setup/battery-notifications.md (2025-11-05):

---
title: Battery Notifications (WIP)
sidebar_position: 8
description: Set up desktop battery notifications.
---

# Battery Notifications Setup

:::warning[WIP]
This is a work in progress; it doesn't seem to be currently working correctly.
:::

The idea here is to have a background service that monitors the battery status from the Power Management HAT and sends desktop notifications when the battery is low.

### 1. Copy battery status scripts from GitHub

```bash
# Download battery status scripts from GitHub
cd ~/Typeframe
wget https://raw.githubusercontent.com/jeffmerrick/typeframe/refs/heads/main/px-88/software/battery_monitor.py
wget https://raw.githubusercontent.com/jeffmerrick/typeframe/refs/heads/main/px-88/software/send_user_notification.sh
```

### 2. Make the scripts executable

```bash
chmod +x ~/Typeframe/battery_monitor.py
chmod +x ~/Typeframe/send_user_notification.sh
```

### 3. Create systemd service

```bash
sudo nano /etc/systemd/system/battery-monitor.service
```

Paste the following configuration, change the username from `pi` if necessary:

```ini
[Unit]
Description=Battery Monitor with Notifications
After=graphical-session.target
Wants=graphical-session.target

[Service]
Type=simple
ExecStart=/home/pi/Typeframe/battery_monitor.py
Restart=always
RestartSec=30
User=root
Environment=PYTHONUNBUFFERED=1
Environment=WAYLAND_DISPLAY=wayland-1
Environment=XDG_RUNTIME_DIR=/run/user/1000

[Install]
WantedBy=multi-user.target
```

```bash
# Reload systemd and enable service
sudo systemctl daemon-reload
sudo systemctl enable battery-monitor.service
sudo systemctl start battery-monitor.service
```

```bash
# Check service status
sudo systemctl status battery-monitor.service

# View service logs
sudo journalctl -u battery-monitor.service -f

# Test battery reading manually
sudo python3 /home/pi/Typeframe/battery_monitor.py
```

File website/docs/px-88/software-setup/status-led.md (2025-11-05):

---
title: Status LED
sidebar_position: 4
description: Set up the status LED.
---

# Status LED Setup

If you've installed the status LED as described in the assembly section, here's what you need to do on the software side to get it working. I found a [helpful guide](https://www.richinfante.com/2021/08/11/raspberry-pi-gpio-status-lights) that explains how this all works.

### 1. Test the LED

This will turn the LED on for 1 second and then turn it off again.

```bash
gpioset -c gpiochip0 13=1
sleep 1
gpioset -c gpiochip0 13=0
```

### 2. Edit Configuration

```bash
sudo nano /boot/firmware/config.txt
```

Add the following line at the end:

```bash
# Activity LED indicator on GPIO 13
dtoverlay=act-led,gpio=13
```

### 3. Reboot

```bash
sudo reboot
```

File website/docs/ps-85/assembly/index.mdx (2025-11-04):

---
title: Assembly
sidebar_position: 2
hide_table_of_contents: true
---

import DocCardList from "@theme/DocCardList";

# Assembly

<DocCardList />

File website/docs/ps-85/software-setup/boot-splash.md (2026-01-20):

---
title: Boot Splash Screen
sidebar_position: 3
description: Customize the boot splash screen.
---

# Customize the Boot Splash Screen

The Raspberry Pi displays a boot splash screen during startup. You can customize this screen to show an Alien-themed image or any other image of your choice. You can also hide it completely in `raspi-config` if you prefer.

### 1. Change Boot Splash Image

Change the Raspberry Pi boot splash image to a custom Alien image.

1. Open a terminal and go to the Plymouth theme directory:
   ```bash
   cd /usr/share/plymouth/themes/pix/
   ```
2. (Optional) Back up the original splash image:
   ```bash
   sudo mv splash.png splash.png.bk
   ```
3. Download the Nostromo boot splash image from GitHub:
   ```bash
   sudo wget https://raw.githubusercontent.com/jeffmerrick/typeframe/main/ps-85/software/images/nostromo-boot.png -O splash.png
   ```
4. Refresh the Plymouth theme:
   ```bash
   sudo plymouth-set-default-theme -R pix
   ```

:::tip[Custom Images]
Images need to be rotated 90 degrees clockwise since the display isn't rotated until after boot. Match the screen size of 1280x400 pixels for best results.
:::

### 2. Hide Boot Text

Edit the Plymouth theme configuration to hide boot text:

```bash
sudo nano /usr/share/plymouth/themes/pix/pix.script
```

Remove or comment out the last lines:

```bash
#message_sprite = Sprite();
#message_sprite.SetPosition(screen_width * 0.1, screen_height * 0.9, 10000);
#
#fun message_callback (text) {
#       my_image = Image.Text(text, 1, 1, 1);
#       message_sprite.SetImage(my_image);
#       sprite.SetImage (resized_image);
#}
#
#Plymouth.SetUpdateStatusFunction(message_callback);
```

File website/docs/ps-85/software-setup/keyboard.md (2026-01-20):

---
title: Keyboard
sidebar_position: 1
description: Configuring the keyboard.
---

# Keyboard Setup

## Overview

The [BM43 documentation](http://kpchn.com/s/PoHJ?path=%2F003-BM%20Series) is somewhat confusing. No matter what I did I couldn't get the keyboard to work with usevia.app. During my troubleshooting I flashed the VIA firmware, however the PCB might actually come with it pre-flashed as I discovered I was able to configure it with the Keychron configuration app instead of the official VIA app. If anyone figures out more details, let me know so I can update the docs!

### 1. Connect with the Keychron App

1. Download the keyboard layout JSON file. I have a working one in the repo in [ps-85/software/keyboard](https://github.com/jeffmerrick/typeframe/tree/main/ps-85/software/keyboard).
2. Plug in the keyboard and navigate to [https://launcher.keychron.com/](https://launcher.keychron.com/).
3. Click "Connect".
4. Choose the BM43 in the dialog and click "Connect"
5. When prompted choose the JSON file you downloaded in step 1.

### 2. Modify Key Mappings

Since this is a 40% keyboard, you'll want to customize it in a way that makes sense to you. Here's what I did:

**Default Layer (Layer 0)**
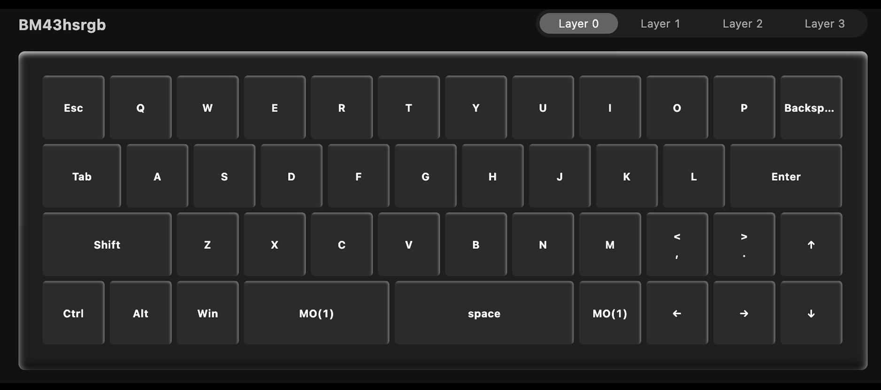
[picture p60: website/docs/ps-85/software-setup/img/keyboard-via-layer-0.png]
Default Keymap


**Function Layer (Layer 1)**
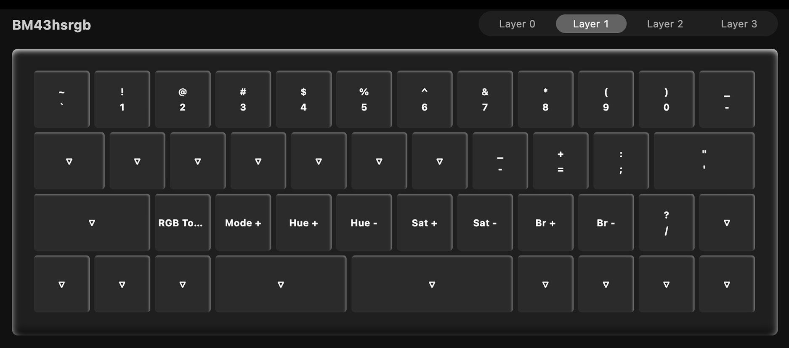
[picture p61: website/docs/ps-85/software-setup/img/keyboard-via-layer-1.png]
Function Layer Keymap


I also exported this out so you can use mine if you'd like, also in [ps-85/software/keyboard](https://github.com/jeffmerrick/typeframe/tree/main/ps-85/software/keyboard).

### 3. Save Changes

Changes are saved automatically as you make them. When you're done, just unplug the keyboard and it's ready to go!

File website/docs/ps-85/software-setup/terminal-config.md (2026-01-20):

---
title: Terminal
sidebar_position: 4
description: Customize your terminal style
---

# Customize the Terminal

Make everything a retro green terminal with a larger font and add some Nostromo-themed boot text.

## Font Configuration

### 1. Install Terminus Font

It might already be pre-installed, but just to be safe.

```bash
sudo apt update
sudo apt install fonts-terminus
```

### 2. Configure Console Font

Edit the console setup configuration:

```bash
sudo nano /etc/default/console-setup
```

Set the following values:

```
ACTIVE_CONSOLES="/dev/tty[1-6]"
CHARMAP="UTF-8"
CODESET="guess"
FONT=""
FONTFACE="Terminus"
FONTSIZE="12x24"
VIDEOMODE=
```

### 3. Apply the Configuration

Apply the font changes:

```bash
sudo setupcon
```

The font should now be active. However, it won't persist after reboot yet (see next step).

### 4. Fix Font Persistence

The font configuration doesn't seem to persist across reboots by default so we need to create a service to enforce it.

Create the service file:

```bash
sudo nano /etc/systemd/system/console-font-fix.service
```

Add the following content:

```ini
[Unit]
Description=Fix Console Font Persistence
After=getty.target systemd-vconsole-setup.service

[Service]
Type=oneshot
ExecStart=/bin/sh -c '/usr/bin/setupcon'
StandardOutput=journal

[Install]
WantedBy=multi-user.target
```

Enable and start the service:

```bash
sudo systemctl daemon-reload
sudo systemctl enable console-font-fix.service
sudo systemctl restart console-font-fix.service
sudo systemctl status console-font-fix.service
```

## Nostromo-Themed Boot Text

This displays some Nostromo-themed text in the terminal on boot. It's set up to work with the font size we configured above.

### 1. Create the Nostromo Display Script

Add the display function to your `.bashrc` file:

```bash
nano ~/.bashrc
```

Add this complete code at the end of the file:

```bash
# --- NOSTROMO LOGIN SCREEN SETUP ---

# Set green color for prompt
echo -ne "\e[92m"
PS1='\[\e[92m\]\u@\h:\w \$ '

# Apply font configuration
sudo setupcon
clear

function display_nostromo_screen() {
   # 1. Clear the screen and set text color to green
   tput clear
   tput setaf 2  # Set foreground color to green

   # 2. Define the dynamic date variable (Actual Time)
   CURRENT_DATE=$(date +'%e %^b' | sed 's/^ *//')

   # 3. Calculate FLIGHT_TIME (155 days ahead of CURRENT_DATE)
   FLIGHT_TIME=$(date -d "+155 days" +'%e %^b' | sed 's/^ *//')

   # 3. Print the top header section (Rows 0-2)

   # Row 0
   tput cup 0 0; echo "COMPUTER"
   tput cup 0 30; echo "12493.D"
   tput cup 0 74; echo "SHIP"

   # Row 1
   tput cup 1 0; echo "ACTUAL TIME: ${CURRENT_DATE}"
   tput cup 1 74; echo "WEYLAND YUTANI"

   # Row 2
   tput cup 2 0; echo "FLIGHT TIME: ${FLIGHT_TIME}"
   tput cup 2 74; echo "NOSTROMO 180924"

   # --- BOX START ---

   # Transmission Header (Row 4)
   tput cup 4 0; echo "+---// TRANSMISSION //-----------------------------------------------+"

   # Top Edge of the Box (Row 5)
   tput cup 5 0; echo "+--------------------------------------------------------------------+"

   # Vertical Sides (Rows 6-13)
   for R in {6..13}; do
      tput cup $R 0; echo "|"
      tput cup $R 69; echo "|"
   done

   # --- Directive Text (Inside Box) ---
   TEXT_COL=4 # Starting column for the text inside the border

   tput cup 8 $TEXT_COL; echo "PRIORITY ONE"
   tput cup 9 $TEXT_COL; echo "INSURE RETURN OF ORGANISM FOR ANALYSIS."
   tput cup 10 $TEXT_COL; echo "ALL OTHER CONSIDERATIONS SECONDARY."
   tput cup 11 $TEXT_COL; echo "CREW EXPENDABLE."

   # Bottom Edge of the Box (Row 14)
   tput cup 14 0; echo "+--------------------------------------------------------------------+"

   # 4. Print the main information sections (Right Side)

   # Row 4 (FUNCTION)
   tput cup 4 74; echo "FUNCTION:"
   tput cup 5 74; echo "TANKER/REFINERY"

   # Row 7 (CAPACITY)
   tput cup 7 74; echo "CAPACITY:"
   tput cup 8 74; echo "200 000 000 TONNES"

   # Row 10 (GALACTIC POSITION)
   tput cup 10 74; echo "GALACTIC POSITION:"
   tput cup 11 74; echo "270/RX683*"

   # Row 13 (VELOCITY STATUS)
   tput cup 13 74; echo "VELOCITY STATUS:"
   tput cup 14 74; echo "58 09/ 5DL"

   # 5. Reset the terminal properties for the user prompt
   tput sgr0    # Reset all attributes (color, etc.)
}

# Execute the function to display the screen before the prompt appears
display_nostromo_screen

# --- END NOSTROMO LOGIN SCREEN DISPLAY ---
```

### 2. Test the Setup

Source the updated `.bashrc` to test immediately:

```bash
source ~/.bashrc
```

If it displays correctly, reboot to verify persistence:

```bash
sudo reboot
```

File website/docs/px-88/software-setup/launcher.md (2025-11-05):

---
title: Application Launcher
sidebar_position: 7
description: Set up the terminal-based application launcher.
---

# Install the Application Launcher

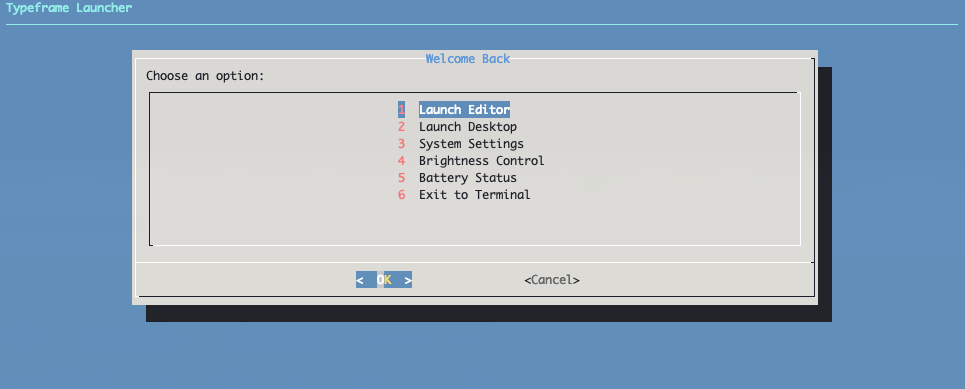
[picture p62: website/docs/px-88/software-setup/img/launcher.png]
Launcher Screenshot


This is a bash script that provides a terminal-based application launcher for the PX-88. It allows you to easily launch a full-screen browser window with a URL of your choice from a text-based menu when booting to the terminal.
By default, it opens Google Docs, but you can edit `launcher.sh` to open anything you'd like. It also allows you to control the screen brightness and view the battery status.

### 1. Configure Boot Behavior

First, set the Pi to boot to terminal instead of desktop:

```bash
sudo raspi-config nonint do_boot_behaviour B2
```

Boot options:

- **B1** - Console (text console, requiring user to login)
- **B2** - Console Autologin (text console, automatically logged in as 'pi' user)
- **B3** - Desktop (desktop GUI, requiring user to login)
- **B4** - Desktop Autologin (desktop GUI, automatically logged in as 'pi' user)

### 2. Install Required Dependencies

```bash
sudo apt-get install dialog
```

### 3. Copy Launcher Script

Download or copy the launcher file to the Typeframe directory in your home directory.

```bash
# Download launcher script from GitHub
cd ~/Typeframe
mkdir ~/launcher
wget https://raw.githubusercontent.com/jeffmerrick/typeframe/refs/heads/main/px-88/software/launcher/launcher.sh

# Make the shell script executable
sudo chmod +x launcher.sh
```

### 4. Auto-launch on Boot

To automatically start the launcher when you boot, run this command to add the launcher to your `.bashrc`:

```bash
echo '~/Typeframe/launcher/launcher.sh' >> ~/.bashrc
```

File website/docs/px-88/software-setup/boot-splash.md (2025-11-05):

---
title: Boot Splash Screen
sidebar_position: 6
description: Customize the boot splash screen.
---

# Customize the Boot Splash Screen

The Raspberry Pi displays a boot splash screen during startup. You can customize this screen to show a Typeframe-themed image or any other image of your choice. You can also hide it completely in `raspi-config` if you prefer.

### 1. Change Boot Splash Image

To change the Raspberry Pi boot splash image to a custom Typeframe image:

1. Open a terminal and go to the Plymouth theme directory:
   ```bash
   cd /usr/share/plymouth/themes/pix/
   ```
2. (Optional) Back up the original splash image:
   ```bash
   sudo mv splash.png splash.png.bk
   ```
3. Download the Typeframe boot splash image from GitHub:
   ```bash
   sudo wget https://raw.githubusercontent.com/jeffmerrick/typeframe/main/px-88/software/images/typeframe-boot-simple.png -O splash.png
   ```
4. Refresh the Plymouth theme:
   ```bash
   sudo plymouth-set-default-theme -R pix
   ```

:::tip[Custom Images]
Images need to be rotated 90 degrees clockwise since the display isn't rotated until after boot. Match the screen size of 1280x400 pixels for best results.
:::

### 2. Hide Boot Text

Edit the Plymouth theme configuration to hide boot text:

```bash
sudo nano /usr/share/plymouth/themes/pix/pix.script
```

Remove or comment out the last lines:

```bash
#message_sprite = Sprite();
#message_sprite.SetPosition(screen_width * 0.1, screen_height * 0.9, 10000);
#
#fun message_callback (text) {
#       my_image = Image.Text(text, 1, 1, 1);
#       message_sprite.SetImage(my_image);
#       sprite.SetImage (resized_image);
#}
#
#Plymouth.SetUpdateStatusFunction(message_callback);
```

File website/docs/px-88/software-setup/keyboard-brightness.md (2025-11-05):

---
title: Keyboard Brightness Control
sidebar_position: 5
description: Set up keyboard brightness shortcuts.
---

# Keyboard Brightness Control Setup

## Configure Brightness Control Shortcuts

### 1. Copy Brightness Scripts

```bash
# Download launcher scripts from GitHub
mkdir ~/Typeframe
cd ~/Typeframe
wget https://raw.githubusercontent.com/jeffmerrick/typeframe/refs/heads/main/px-88/software/brightness_up.sh
wget https://raw.githubusercontent.com/jeffmerrick/typeframe/refs/heads/main/px-88/software/brightness_down.sh
```

Make sure these scripts are executable:

```bash
chmod +x ~/Typeframe/brightness_*.sh
```

### 2. Configure labwc Keyboard Shortcuts

Add the following keyboard shortcuts to your `~/.config/labwc/rc.xml` file, creating it if it doesn't already exist:

```xml
<?xml version="1.0"?>
<openbox_config xmlns="http://openbox.org/3.4/rc">
	<!-- Your existing configuration -->

	<keyboard>
		<!-- Hardware brightness keys (if configured in VIA) -->
		<keybind key="XF86MonBrightnessUp">
			<action name="Execute">
				<command>/bin/sh -c '$HOME/Typeframe/brightness_up.sh'</command>
			</action>
		</keybind>
		<keybind key="XF86MonBrightnessDown">
			<action name="Execute">
				<command>/bin/sh -c '$HOME/Typeframe/brightness_down.sh'</command>
			</action>
		</keybind>

		<!-- Alternative shortcuts using Super + Arrow keys -->
		<keybind key="W-Up">
			<action name="Execute">
				<command>/bin/sh -c '$HOME/Typeframe/brightness_up.sh'</command>
			</action>
		</keybind>
		<keybind key="W-Down">
			<action name="Execute">
				<command>/bin/sh -c '$HOME/Typeframe/brightness_down.sh'</command>
			</action>
		</keybind>
	</keyboard>
</openbox_config>
```

### 3. Reload labwc Configuration

After editing the `rc.xml` file, reload the labwc configuration:

```bash
labwc-pi --reconfigure
```

or reboot:

```bash
sudo reboot
```

### 4. Test Brightness Controls

You can now control brightness using:

- **Hardware Brightness Keys** (I configured as `MO(1) + PgUp` and `MO(1) + PgDown` in VIA)
- **Super + Up Arrow** - Increase brightness
- **Super + Down Arrow** - Decrease brightness

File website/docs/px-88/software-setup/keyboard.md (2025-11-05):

---
title: Keyboard
sidebar_position: 1
description: Configuring the keyboard.
---

# Keyboard Setup

## Overview

The keyboard PCB comes ready to go with firmware installed, but you may want to adjust the key mappings. I recommend connecting the keyboard to a larger computer for this, since the touch screen on the PX-88 would make it difficult.

## Adjust Key Mappings with VIA

### 1. Connect with VIA

1. Download the keymap JSON file. You can find them on the Mechanical Keyboards [product page](https://mechanicalkeyboards.com/products/mk-point65-keyboard-kit), but I've also dropped them into the repository in [px-88/software/keyboard](https://github.com/jeffmerrick/typeframe/tree/main/px-88/software/keyboard). There are different files for the RGB and Multi-Layout versions of the PCB.
2. Plug in the keyboard and navigate to [https://www.usevia.app/](https://www.usevia.app/).
3. You'll need to go to the settings (gear icon) and toggle "Show Design tab" on.
4. Navigate to the Design tab (paintbrush icon) and click "Load" to import the keymap JSON file you downloaded earlier.
5. Now navigate to the "Configure" tab (keyboard icon) and click "Authorize device".
6. Choose Point 65 Hotswap in the dialog and click "Connect"

### 2. Modify Key Mappings

I don't remember the defaults, but here's what I landed on:

**Default Layer (Layer 0)**
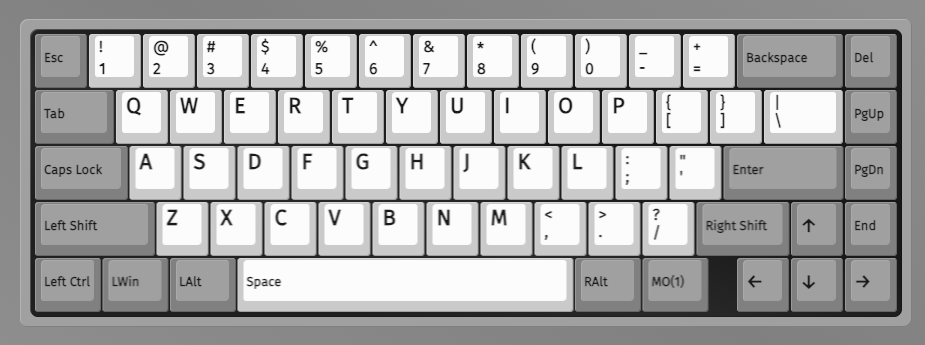
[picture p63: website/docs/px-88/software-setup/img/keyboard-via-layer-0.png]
Default Keymap


**Function Layer (Layer 1)**
Function Layer Keymap

The keyboard had some lights on by default on the left side. In order to turn them off, I had to use the `RGB Toggle` key. In addition, I mapped the screen brightness controls to `MO(1) + PgUp` and `MO(1) + PgDn` using the `Screen +` and `Screen -` keycodes. We'll set up shortcuts to make those work later in the setup.

### 3. Save Changes

Changes are saved automatically as you make them. When you're done, just unplug the keyboard and it's ready to go!

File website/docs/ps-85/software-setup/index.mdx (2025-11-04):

---
title: Software
sidebar_position: 3
hide_table_of_contents: true
---

import DocCardList from "@theme/DocCardList";

# Software Setup

<DocCardList />

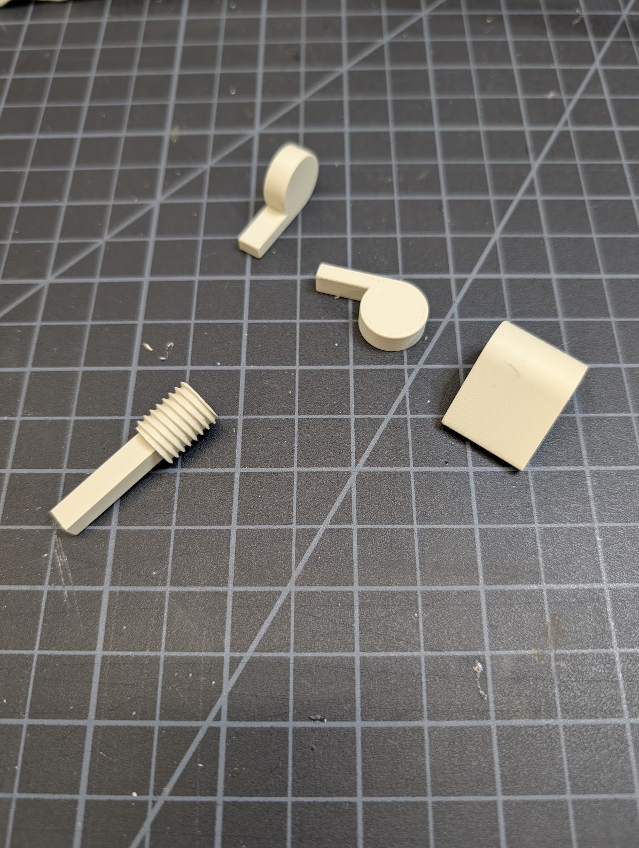
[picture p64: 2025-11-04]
website/docs/px-88/assembly/img/hinge-assembly-01.jpg

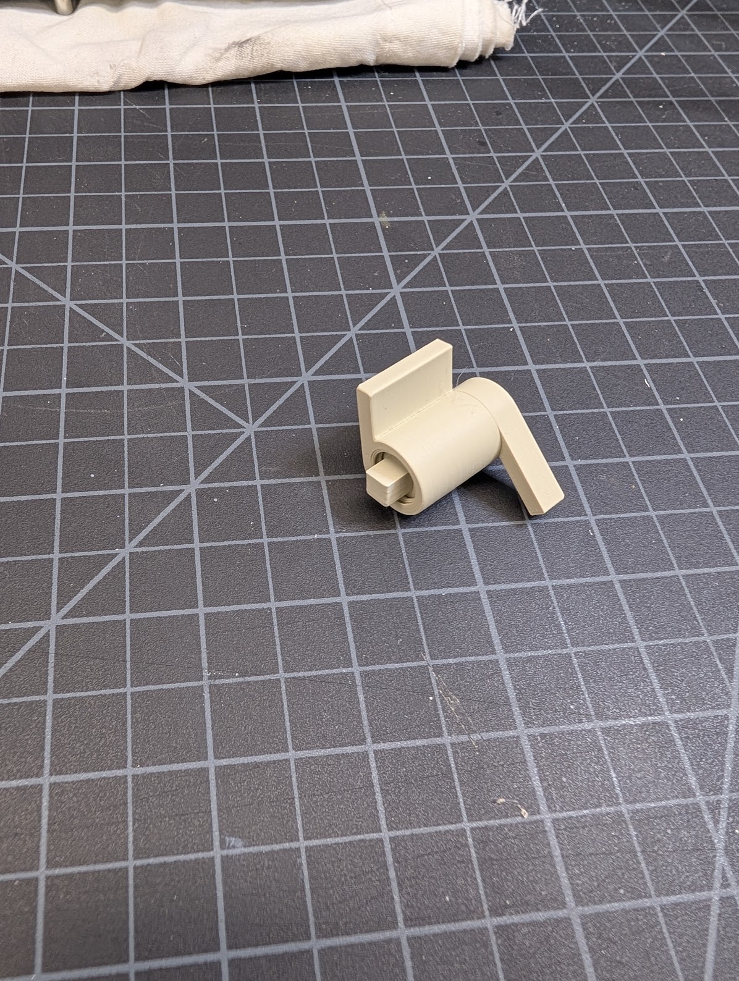
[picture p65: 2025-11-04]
website/docs/px-88/assembly/img/hinge-assembly-03.jpg

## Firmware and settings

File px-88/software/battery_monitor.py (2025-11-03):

#!/usr/bin/env python3
"""
Battery monitoring service with notifications
Monitors battery level and sends notifications at key thresholds
"""

import time
import serial
import re
import sys
import subprocess
import os

# Battery Configuration
UART_PORT = "/dev/ttyS0"
BAUDRATE = 115200

# Notification thresholds (in descending order)
NOTIFICATION_LEVELS = [50, 40, 30, 25, 20, 15, 10, 5]

# State file to track notifications and previous level
STATE_FILE = "/tmp/battery_monitor_state"

def parse_uart_line(line):
    patterns = {
        "Power_State": r"Power_State\s*:\s*(\d+)",
        "Running_State": r"Running_State\s*:\s*(\d+)",
        "Vin_Voltage": r"Vin_Voltage\(V\)\s*:\s*([\d.]+)",
        "Vout_Voltage": r"Vout_Voltage\(V\)\s*:\s*([\d.]+)",
        "Vout_Current": r"Vout_Current\(MA\)\s*:\s*([\d.]+)"
    }
    result = {}
    for key, pat in patterns.items():
        m = re.search(pat, line)
        if m:
            result[key] = float(m.group(1)) if "Voltage" in key or "Current" in key else int(m.group(1))
    return result

def get_battery_status(num_readings=3):
    ser = None
    try:
        ser = serial.Serial(UART_PORT, BAUDRATE, timeout=3)  # Increased timeout
        current_reading = {}
        expected_keys = {"Power_State", "Running_State", "Vin_Voltage", "Vout_Voltage", "Vout_Current"}
        
        # Try multiple times to get a complete reading
        for attempt in range(50):  # Increased attempts
            try:
                line = ser.readline().decode(errors='ignore').strip()
                if not line:
                    continue
                    
                parsed = parse_uart_line(line)
                if parsed:
                    current_reading.update(parsed)
                    # Check if we have a complete reading
                    if expected_keys.issubset(current_reading.keys()):
                        return current_reading.copy()
                        
            except serial.SerialException as e:
                print(f"Serial exception on attempt {attempt}: {e}", file=sys.stderr)
                break
            except Exception as e:
                print(f"Unexpected error on attempt {attempt}: {e}", file=sys.stderr)
                continue
                
        # If we get here, we didn't get a complete reading
        if current_reading:
            print(f"Incomplete reading after 50 attempts: {current_reading}", file=sys.stderr)
        else:
            print("No UART data received after 50 attempts", file=sys.stderr)
        return {}
        
    except Exception as e:
        print(f"Error opening UART: {e}", file=sys.stderr)
        return {}
    finally:
        if ser and ser.is_open:
            ser.close()

def estimate_percentage(status):
    vin = status.get("Vin_Voltage", 0)
    
    if vin > 4.0:
        percent = 100  # Charging/plugged in
    else:
        # Battery discharge curve mapping
        if vin >= 4.0:
            percent = 100
        elif vin >= 3.8:
            percent = 80 + int((vin - 3.8) / 0.2 * 20)
        elif vin >= 3.7:
            percent = 60 + int((vin - 3.7) / 0.1 * 20)
        elif vin >= 3.6:
            percent = 40 + int((vin - 3.6) / 0.1 * 20)
        elif vin >= 3.4:
            percent = 20 + int((vin - 3.4) / 0.2 * 20)
        elif vin >= 3.2:
            percent = int((vin - 3.2) / 0.2 * 20)
        else:
            percent = 0
    
    return max(0, min(100, percent))

def load_state():
    """Load previous state from file"""
    try:
        if os.path.exists(STATE_FILE):
            with open(STATE_FILE, 'r') as f:
                lines = f.read().strip().split('\n')
                notified_levels = set(map(int, lines[0].split(','))) if lines[0] else set()
                previous_percentage = int(lines[1]) if len(lines) > 1 else 100
                is_charging = lines[2] == 'True' if len(lines) > 2 else False
                return notified_levels, previous_percentage, is_charging
    except:
        pass
    return set(), 100, False

def save_state(notified_levels, percentage, is_charging):
    """Save current state to file"""
    try:
        with open(STATE_FILE, 'w') as f:
            f.write(','.join(map(str, sorted(notified_levels))) + '\n')
            f.write(str(percentage) + '\n')
            f.write(str(is_charging) + '\n')
    except Exception as e:
        print(f"Error saving state: {e}", file=sys.stderr)

def send_notification(title, message, urgency="normal"):
    """Send notification to desktop user via wfpanelctl"""
    try:
        script_path = "/home/pi/Typeframe/send_user_notification.sh"
        
        if urgency == "critical":
            cmd = ['/usr/sbin/runuser', '-u', 'pi', '--', script_path, 'critical', f"{title}: {message}"]
        else:
            cmd = ['/usr/sbin/runuser', '-u', 'pi', '--', script_path, 'notify', f"{title}: {message}"]
        
        result = subprocess.run(cmd, check=False, capture_output=True, text=True)
        print(f"Notification sent: {title} - {message}")
        if result.returncode != 0:
            print(f"Notification command returned: {result.returncode}", file=sys.stderr)
            print(f"Notification stdout: {result.stdout}", file=sys.stderr)
        if result.stderr:
            print(f"Notification stderr: {result.stderr}", file=sys.stderr)
    except Exception as e:
        print(f"Error sending notification: {e}", file=sys.stderr)

def monitor_battery():
    """Main monitoring loop"""
    print("Starting battery monitoring service...")
    
    # Get initial battery status for startup notification
    initial_status = get_battery_status()
    if initial_status:
        initial_percentage = estimate_percentage(initial_status)
        send_notification("Battery Monitor", f"Started - {initial_percentage}% battery", "low")
    else:
        send_notification("Battery Monitor", "Started - Reading battery...", "low")
    
    # Rolling readings for median calculation
    voltage_history = []
    max_history = 5  # Keep last 5 readings for median
    
    # Load previous state
    notified_levels, previous_percentage, was_charging = load_state()
    
    # Track consecutive failures for retry logic
    consecutive_failures = 0
    max_consecutive_failures = 5
    
    # Track if we need to check for missed notifications after reconnection
    had_communication_failure = False
    
    try:
        while True:
            # Get battery status
            status = get_battery_status()
            if not status:
                consecutive_failures += 1
                had_communication_failure = True
                print(f"No battery data available (attempt {consecutive_failures}/{max_consecutive_failures})")
                
                if consecutive_failures >= max_consecutive_failures:
                    print("Too many consecutive failures, waiting longer before retry...")
                    time.sleep(60)  # Wait longer after multiple failures
                    consecutive_failures = 0  # Reset counter
                else:
                    time.sleep(5)  # Quick retry for initial failures
                continue
            
            # Reset failure counter on successful read
            consecutive_failures = 0
            
            current_voltage = status.get("Vin_Voltage", 0)
            
            # Add to voltage history
            voltage_history.append(current_voltage)
            if len(voltage_history) > max_history:
                voltage_history.pop(0)  # Remove oldest reading
            
            # Use median voltage for percentage calculation (immune to outliers)
            sorted_voltages = sorted(voltage_history)
            if len(sorted_voltages) % 2 == 0:
                # Even number of readings - average the middle two
                mid = len(sorted_voltages) // 2
                median_voltage = (sorted_voltages[mid-1] + sorted_voltages[mid]) / 2
            else:
                # Odd number of readings - take the middle one
                median_voltage = sorted_voltages[len(sorted_voltages) // 2]
            
            status_for_calc = status.copy()
            status_for_calc["Vin_Voltage"] = median_voltage
            
            percentage = estimate_percentage(status_for_calc)
            is_charging = median_voltage > 4.1  # Consider charging if voltage is high
            
            print(f"Battery: {percentage}% (Current: {current_voltage:.2f}V, Median: {median_voltage:.2f}V)")
            print(f"Charging state: {is_charging}, Was charging: {was_charging}")
            
            # Check if we just recovered from communication failure
            if had_communication_failure:
                print("Communication restored - checking for missed notifications")
                had_communication_failure = False
                # Force check all notification levels to catch any missed during outage
                for level in NOTIFICATION_LEVELS:
                    if percentage <= level and level not in notified_levels and not is_charging:
                        urgency = "critical" if level <= 10 else "normal"
                        send_notification(
                            "Low Battery Warning",
                            f"Battery level: {percentage}% ({median_voltage:.2f}V) - Missed during communication outage",
                            urgency
                        )
                        notified_levels.add(level)
                        print(f"Sent missed notification for {level}% threshold")
            
            # Check for charging state change
            if is_charging and not was_charging:
                print("State change detected: Plugged in")
                send_notification("Battery", "Device plugged in - Charging", "low")
                # Reset notification levels when plugged in
                notified_levels = set()
            elif not is_charging and was_charging:
                print("State change detected: Unplugged")
                send_notification("Battery", "Device unplugged - Running on battery", "low")
            
            # Only check for low battery notifications when not charging and battery is going down
            if not is_charging and percentage < previous_percentage:
                for level in NOTIFICATION_LEVELS:
                    if percentage <= level and level not in notified_levels:
                        # Determine urgency based on level
                        if level <= 10:
                            urgency = "critical"
                        elif level <= 20:
                            urgency = "normal"
                        else:
                            urgency = "low"
                        
                        send_notification(
                            "Low Battery Warning",
                            f"Battery level: {percentage}% ({median_voltage:.2f}V)",
                            urgency
                        )
                        notified_levels.add(level)
                        break  # Only notify for one level per check
            
            # Save current state
            save_state(notified_levels, percentage, is_charging)
            
            # Update previous values
            previous_percentage = percentage
            was_charging = is_charging
            
            # Check every 5 seconds for responsive monitoring
            time.sleep(5)
                
    except KeyboardInterrupt:
        print("\nStopping battery monitor...")
    except Exception as e:
        print(f"Unexpected error: {e}", file=sys.stderr)
        time.sleep(60)  # Wait before potential restart

if __name__ == "__main__":
    monitor_battery()

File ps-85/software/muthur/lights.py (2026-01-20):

import time
import random
import board
import busio
from adafruit_is31fl3731.charlie_bonnet import CharlieBonnet as Display
import sys

i2c = busio.I2C(board.SCL, board.SDA)
display = Display(i2c)

MIN_BRIGHT = 1
MAX_BRIGHT = 20

if len(sys.argv) > 1 and sys.argv[1] == "off":
    i2c = busio.I2C(board.SCL, board.SDA)
    display = Display(i2c)
    for x in range(display.width):
        for y in range(display.height):
            display.pixel(x, y, 0)
    sys.exit(0)


# ----- cluster generation -----

clusters = []  # each: {pixels, on, next}

num_clusters = int((display.width * display.height) / 4)

for _ in range(num_clusters):
    cx = random.randrange(display.width)
    cy = random.randrange(display.height)

    size = random.randint(3, 7)
    pixels = []

    for _ in range(size):
        x = min(display.width - 1, max(0, cx + random.randint(-1, 1)))
        y = min(display.height - 1, max(0, cy + random.randint(-1, 1)))
        pixels.append((x, y))

    on = random.random() < 0.6

    hold = random.uniform(2.0, 6.0) if on else random.uniform(0.5, 2.0)

    clusters.append({
        "pixels": list(set(pixels)),
        "on": on,
        "next": time.monotonic() + hold,
        "brightness": [random.randint(MIN_BRIGHT, MAX_BRIGHT) for _ in pixels]
    })

# ----- initial draw -----

for c in clusters:
    for (x, y), b in zip(c["pixels"], c["brightness"]):
        display.pixel(x, y, b if c["on"] else 0)

# ----- main loop -----

while True:
    now = time.monotonic()

    for c in clusters:
        if now >= c["next"]:
            c["on"] = not c["on"]
            # Set the next activation time
            hold = random.uniform(2.0, 6.0) if c["on"] else random.uniform(0.5, 2.0)
            c["next"] = now + hold
            # Update the display for this cluster
            for (x, y), b in zip(c["pixels"], c["brightness"]):
                display.pixel(x, y, b if c["on"] else 0)
    time.sleep(0.05)  # Small delay to avoid high CPU usage

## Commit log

2025-11-03 Add files, simplify and cleanup
    [badge_bottom.stl, badge_top.stl, case_bottom.stl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]
2025-11-04 Cleanup, add website and start assembly documentation
    [badge_bottom.stl, badge_top.stl, case_bottom.stl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]
2025-11-05 Update BOM
2025-11-14 Update hinge tolerances
    [hinge_barrel_x2.stl, hinge_shaft_x2.stl, hinge_slider_x2.stl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]
2025-11-19 Add missing hinge 3MF, update opengraph image and meta description
    [hinges.3mf]
2025-11-28 Fix hinge STLs, add tolerance options, update docs
    [hinge_barrel_x2.stl, hinge_barrel_x2_0.05mm.stl, hinge_barrel_x2_0.10mm.stl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]
2025-12-03 Add looser tolerance options, update docs
    [badge_bottom.stl, badge_top.stl, case_bottom.stl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]
2025-12-08 Add missing Power Management HAT firmware compile step
2026-01-20 Add PS-85 (#7)
    * WIP: Start adding PS-85 docs
    * WIP: PS-85 files
    * Homepage, fix gallery
    * Add source and print files, add photos, complete docs
    * Update main readme, homepage tweaks
    * Update hero, docs clarity edits
    * Fix charlieplex holes in print and source files
    * Update boot image
    [case_bottom.stl, charlieplex.stl, gpio_cover.stl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]
2026-10-12 Fix status LED GPIO in assembly guide (#9)
